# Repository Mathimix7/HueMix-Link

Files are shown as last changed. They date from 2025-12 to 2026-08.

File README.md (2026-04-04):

<h1 align="center">HueMix-Link</h1>
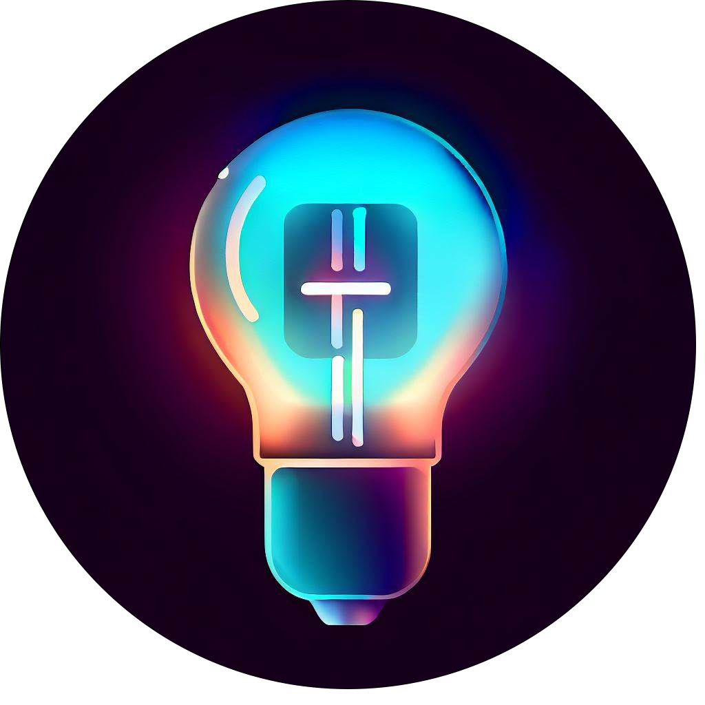
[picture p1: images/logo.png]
HueMix-Link's logo


## Table of Contents

- [Quick Start](#quick-start)
- [Project Overview](#project-overview)
- [Screenshots](#screenshots)
- [What Is In This Repository](#what-is-in-this-repository)
- [System Overview](#system-overview)
- [Prerequisites](#prerequisites)
- [Installation](#installation)
- [First-time Commissioning Workflow](#first-time-commissioning-workflow)
- [ESP Firmware: Build and Flash](#esp-firmware-build-and-flash)
- [Firmware Updates (OTA Page)](#firmware-updates-ota-page)
- [Configuration and Data Storage](#configuration-and-data-storage)
- [Networking and Ports](#networking-and-ports)
- [How Automation Works](#how-automation-works)
- [Devices](#devices)
- [License](#license)

## Quick Start

1. Install the backend on a Linux host:

 ```bash
  git clone https://github.com/Mathimix7/HueMix-Link.git
  cd HueMix-Link
  sudo bash install.sh
  ```

2. Open the web UI at `http://huemixlink.local` or your server IP.
2. Pair your Hue Bridge from the Bridge configuration page.
3. Put an ESP device into pairing mode and add it from the Pairing page.
4. Configure the device behavior, then verify it by triggering a button, motion sensor, or lightstrip sync.

## Project Overview

HueMix-Link is a local smart home bridge that connects custom ESP-based devices (gateways, buttons, remotes, motion sensors, door sensors, and lightstrips) to Philips Hue rooms and scenes.

It provides:

- A Flask web UI for setup and management
- A UDP server for low-latency gateway communication
- Automation logic for buttons, remotes, and motion sensors
- OTA firmware update workflows for all device types
- Backup and restore tools for configuration data

## Screenshots

<table width="85%" align="center">
  <tr>
    <td colspan="2" align="center">
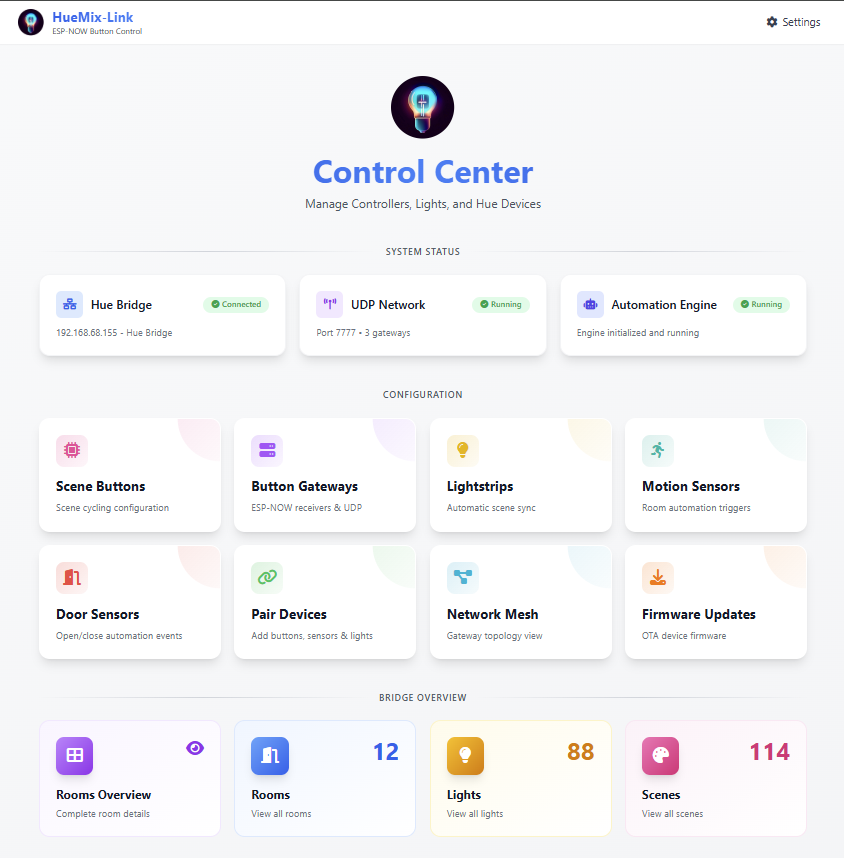
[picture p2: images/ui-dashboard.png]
Dashboard
      
    </td>
  </tr>
  <tr>
    <td width="50%" align="center">
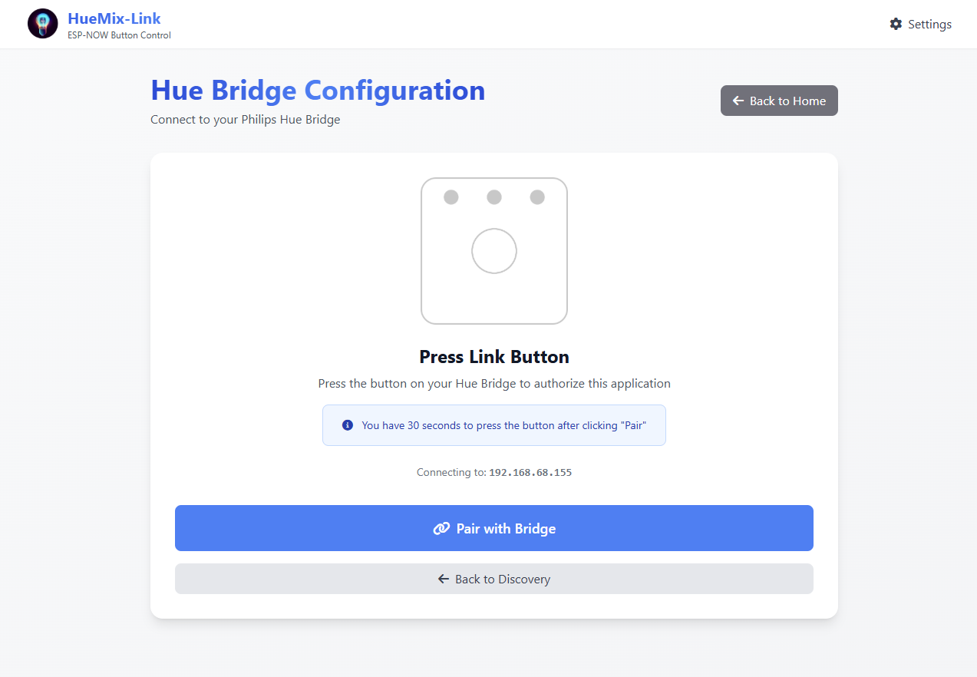
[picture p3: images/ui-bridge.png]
Bridge configuration
      
    </td>
    <td width="50%" align="center">
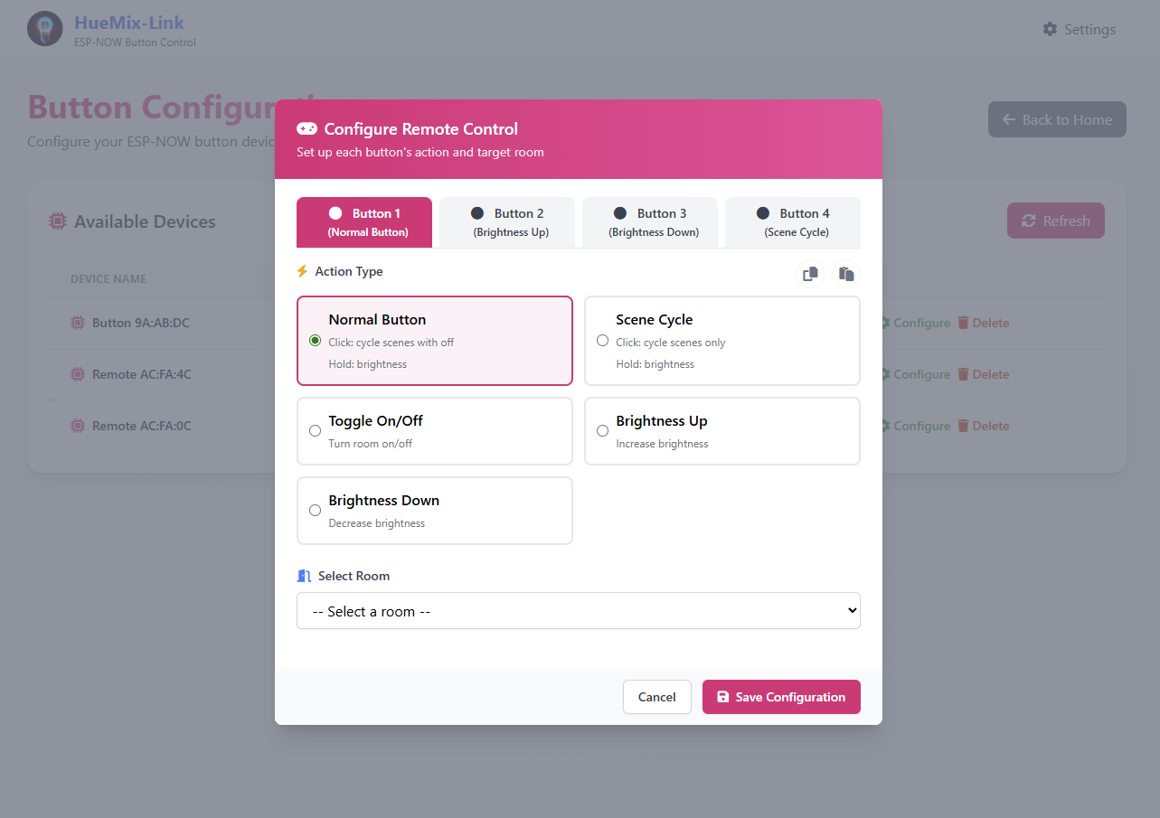
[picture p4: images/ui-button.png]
Button configuration
      
    </td>
  </tr>
  <tr>
    <td width="50%" align="center">
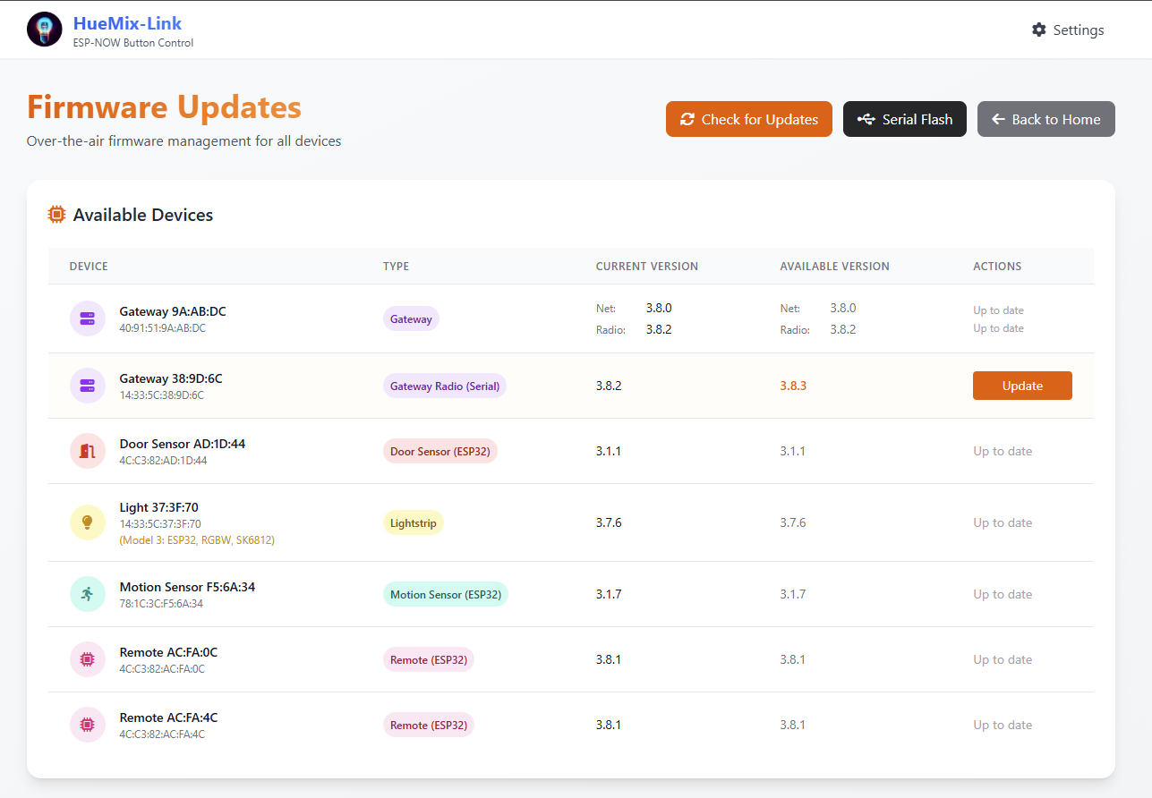
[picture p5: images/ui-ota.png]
OTA page
      
    </td>
    <td width="50%" align="center">
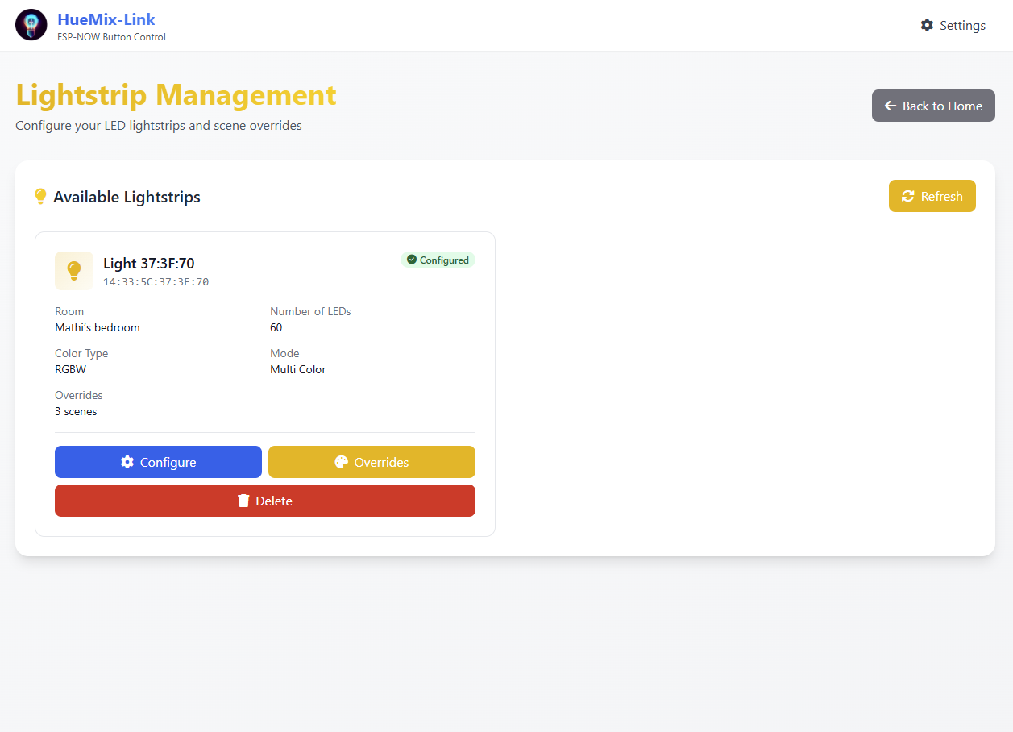
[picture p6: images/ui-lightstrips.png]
Lightstrip configuration
      
    </td>
  </tr>
</table>

## What Is In This Repository

- `python/`: Main backend service (Flask UI + UDP network + automations + OTA)
- `esp-firmware/`: PlatformIO firmware sources for all device types (gateway, buttons, remotes, motion sensors, door sensors, lightstrips)
- `Hardware-designs/`: KiCad design files for all device types (gateway, buttons, remotes, motion sensors, door sensors, lightstrips)
- `3D Files/`: 3D model files for all device types (STL format for 3D printing)
- `install.sh`: Linux installer/updater
- `VERSION`: Version file for installer/update workflows

## System Overview

### High-level architecture

1. **All ESP devices use ESP-NOW**: Low-power mesh protocol for device-to-device communication
2. **Gateways bridge ESP-NOW to UDP**: Gateways receive ESP-NOW messages and forward them to the backend via UDP
3. **Backend (UDP server) receives events**: Button presses, remote actions, motion detections, device hellos, delivery reports
4. **Automation engine maps events to Hue actions**: Scene activation, toggle on/off, brightness adjust, and lightstrip sync
5. **Hue state is cached and synchronized**: Automations and lightstrips stay aligned with current room/scene state
6. **Web UI for management**: Device pairing, automation configuration, OTA updates, monitoring, and backups

### Main runtime services

- **Flask + Waitress**: Web UI server `127.0.0.1:5001` (default)
- **UDP listener**: Receives gateway messages on `0.0.0.0:7777` (default, configurable)
- **Automation service**: Listens to device events and Hue state changes, applies configured logic
- **OTA manager**: Handles firmware distribution, chunking, and acknowledgment tracking

## Prerequisites

### Software

- Python 3.9+ (3.10+ recommended)
- `pip` and virtual environment support (`venv`)
- Network access to your Hue Bridge (same LAN)
- Linux OS with `systemd` (for production install)
- `sudo` access and `apt` package manager

### Hardware

- At least one Hue Bridge with configured rooms/scenes
- Supported HueMix-Link devices (gateways, buttons, remotes, motion sensors, door sensors, lightstrips)
- Firmware binaries matching your device type and model

## Installation

### Linux

From the repository root:

```bash
sudo bash install.sh
```

The installer will:

- Deploy the Python app to `/opt/huemix-link`
- Create a dedicated service user and Python virtual environment
- Set up a `systemd` service (`huemix-link`) to run on boot
- Configure HAProxy to expose the web app (HTTP port 80, HTTPS port 443 by default)
- Store all runtime data in `/opt/huemix-link/data`

Useful installer options:

```bash
sudo bash install.sh --help           # Show all options
sudo bash install.sh --yes            # Non-interactive install
sudo bash install.sh --dry-run        # Preview without making changes
sudo bash install.sh --force          # Force recreation of venv
sudo bash install.sh --show-version   # Show installed and source versions
sudo bash install.sh --port 8080      # Expose on custom HTTP port
sudo bash install.sh --no-https       # Disable HTTPS (HTTP only)
sudo bash install.sh --no-local       # Skip huemixlink.local hostname setup
```

After installation, the web UI is accessible at:

- `https://huemixlink.local` (or your server IP)
- `http://huemixlink.local` (or your server IP)

### Updating

To update the backend to a newer version, pull the latest code and re-run the installer:

```bash
git pull
sudo bash install.sh
```

The installer detects the existing installation, updates the files, and restarts the service automatically.

## First-time Commissioning Workflow

1. **Start the backend** (automatic on boot if installed via installer)
2. **Open the web UI** at `http://huemixlink.local` (or your server IP)
3. **Configure Hue Bridge**:
   - Go to the Bridge configuration page
   - Auto-discover or enter bridge IP manually
   - Press the Hue Bridge link button
   - Pair app with bridge (saves credentials)
4. **Pair ESP devices**:
   - Go to Pairing page
   - Start pairing window (choose device type if desired)
   - Power on or reset target devices
   - Devices announce themselves via ESP-NOW → gateway → backend
5. **Configure each device**:
    - **Buttons/Remotes**: Map to room + scenes + action behavior (normal, toggle, brightness, scene-cycle)
    - **Motion Sensors**: Set room, time slots, motion actions, after-actions, cooldown periods
    - **Door Sensors**: Set room, open/close actions, and any automation triggers tied to magnetic state changes
    - **Lightstrips**: Assign room, configure LED count/type, optional color scene overrides
    - **Gateways**: Verify online status, mesh routing, LED schedule (day/night auto-off)
6. **Validate behavior** by triggering physical events and checking Hue room/scene changes

## ESP Firmware: Build and Flash

### Flashing ESP devices

**Option 1: Serial flash via OTA page**

1. Go to the **OTA** page in the web UI
2. Select firmware type
3. Connect ESP device via serial in programming mode
4. Click **Flash** and select serial port
5. Monitor progress on the page

**Option 2: Serial port flash**

Use PlatformIO to flash directly via USB:

```bash
cd esp-firmware
pio run -e esp32_net_node --target upload
```

Or use `esptool.py` directly:

```bash
esptool.py --port /dev/ttyUSB0 write_flash 0x0 huemixlink-esp32-net-vX.Y.Z.bin
```

Pre-built firmware binaries are available in the project's GitHub releases. Download the `.bin` file(s) matching your device type and platform.

## Firmware Updates (OTA Page)

The **OTA** page in the web UI lets you:

- **Check available versions** from GitHub releases
- **Select device** type/model and target device
- **Battery-powered devices**: double-press the reset button before OTA update
- **Initiate flash** with progress monitoring
- **Monitor errors** and retry failed updates

## Configuration and Data Storage

All runtime configuration is stored in `python/data/` (or `/opt/huemix-link/data` in production) as JSON files:

- `bridge.json`: Hue bridge IP and app username
- `config.json`: Server settings (UDP port, dev mode)
- `gateways.json`: Known gateway devices
- `buttons.json`: Button and remote configurations
- `motion_sensors.json`: Motion sensor configurations and time slots
- `lightstrips.json`: Lightstrip configurations and color overrides
- `pairing_history.json`: Last 5 paired devices
- `home_id`: Unique identifier for this HueMix-Link instance. This value is embedded in every packet as a shared secret and used to verify that incoming messages belong to your installation. All devices must be paired while this ID is set — re-pairing is required if it changes.

Backups are created and restored through the settings page; they are stored in `data/backups/`.

## Networking and Ports

- **Web server (internal)**: `127.0.0.1:5001` (Flask)
- **UDP listener (internal)**: `0.0.0.0:7777` (default, receives gateway messages)
- **External HTTP/HTTPS (production)**: Exposed by HAProxy (default HTTP 80 + HTTPS 443)

UDP port can be changed in settings; the backend will restart UDP listening with the new port.

## How Automation Works

1. **Device sends event** via **ESP-NOW** (button press, remote action, motion detection)
2. **Gateway receives** via ESP-NOW and forwards message to backend via **UDP**
3. **UDP server** decodes and validates packet (signature check using HomeID)
4. **Device manager** resolves device identity; **pairing manager** verifies eligibility
5. **Automation engine** applies configured logic:
   - **Buttons/Remotes**: Scene cycle, toggle, brightness adjust, hold-to-adjust
   - **Motion Sensors**: Trigger scenes/lights on detection; post-motion fade/off actions; cooldown throttling
6. **Hue API** is called to apply scene/room/light changes
7. **Hue state manager** caches current room, light, and scene state
8. **Lightstrip sync**: Checks if any lightstrips should mirror current scene; sends raw LED commands via **ESP-NOW → gateway → UDP**

On startup, config sync reconciles saved room/scene references against live Hue topology to avoid stale mappings.

## Devices

### Gateway

<table><tr>
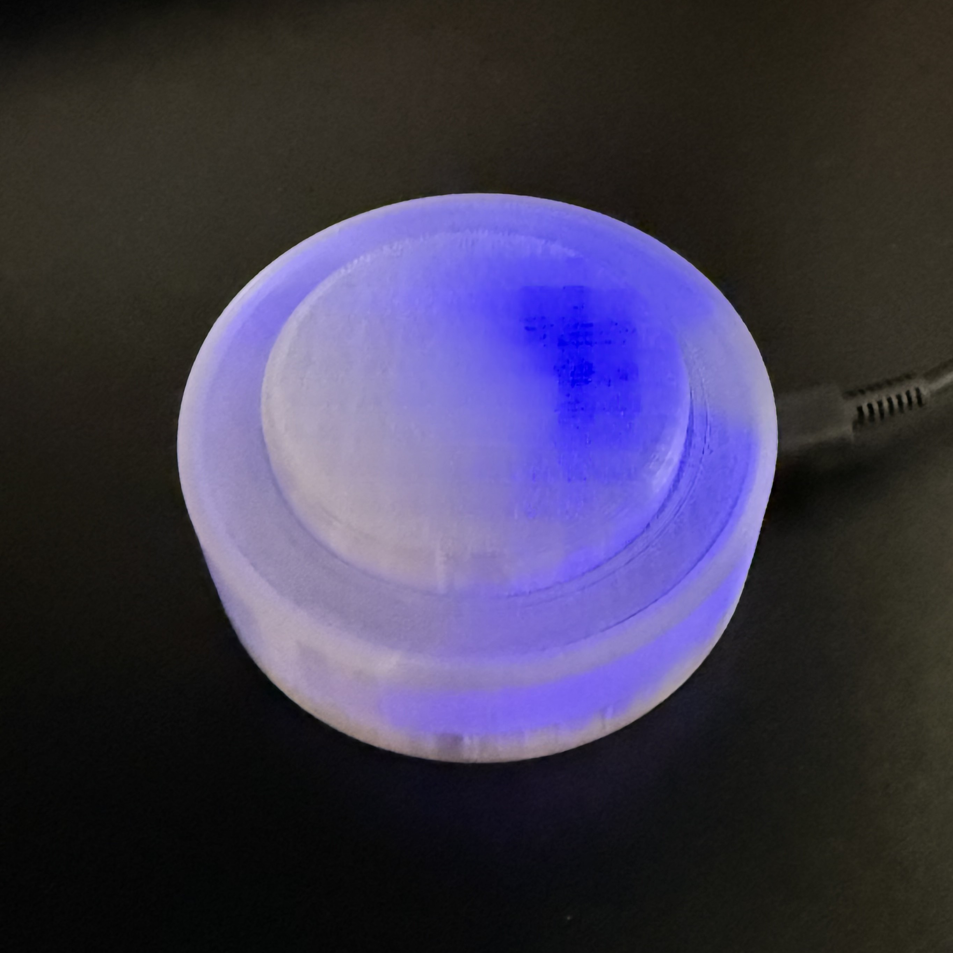
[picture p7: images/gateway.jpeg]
Gateway
  <td></td>
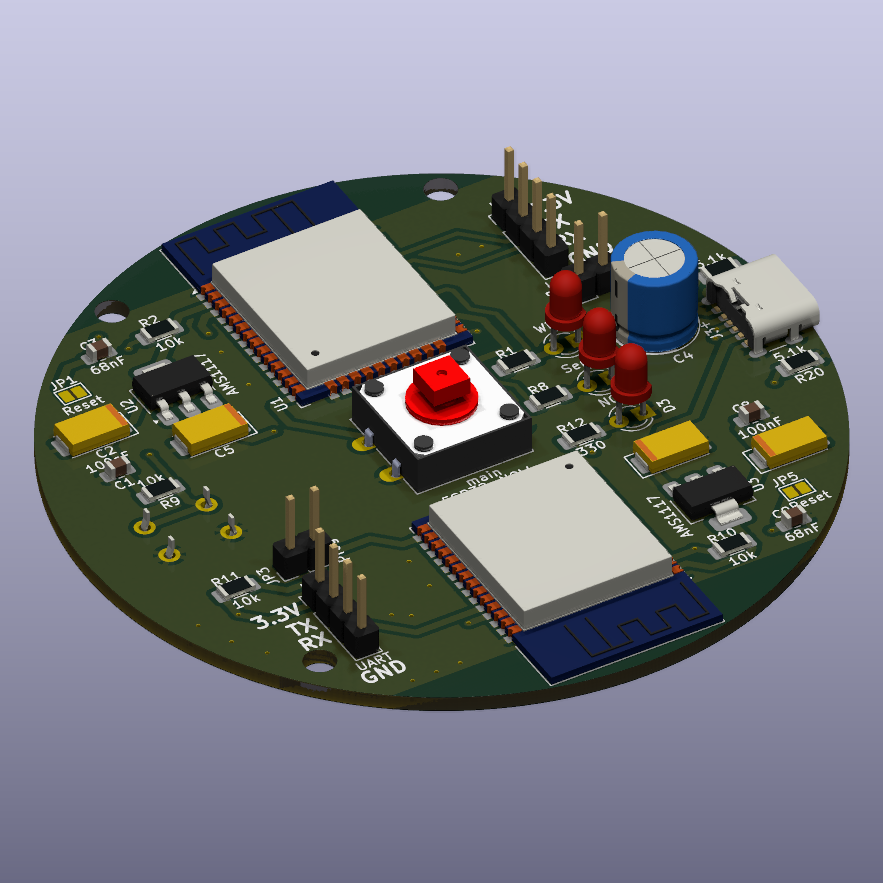
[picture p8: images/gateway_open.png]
Gateway
  <td></td>
</tr></table>

The Gateway is a single board that contains two ESP32 modules working together:

- **Net Node** — connects to your home WiFi and bridges between the backend (UDP) and the ESP-NOW mesh. Runs WiFiManager for wireless configuration and relays commands to the radio node over a high-speed UART link.
- **Radio Node** — handles all ESP-NOW communication with peripheral devices (buttons, remotes, sensors, lightstrips) and forwards packets to/from the net node over UART. Extends ESP-NOW coverage independently of WiFi.

**LED indicators**

| LED | State | Meaning |
|-----|---|---|
| WiFi | Off | No power / booting |
| WiFi | Fast blink (0.2s) | Not yet configured — WiFi config portal is open |
| WiFi | Slow blink (0.5s) | Connecting or retrying WiFi |
| WiFi | Solid on | Online and operational |
| Data | Brief flash | Packet received or forwarded |
| Data | Breathing (fade in/out) | Net node OTA firmware update in progress |
| Radio | Brief flash | ESP-NOW packet relayed |
| Radio | Breathing (fade in/out) | Radio node OTA firmware update in progress |

**Buttons**

- **Main button**: Acts as a single button that can be mapped to a Hue room in the web UI
- **Aux button**: Hold 5+ seconds to factory-reset and re-open the WiFi config portal

**Initial setup**

1. Power on the gateway — the WiFi LED fast-blinks and it broadcasts SSID `HueMix Link - XXXXXXXX`
2. Connect to that SSID (password: `HueMixLink`) with a phone or laptop
3. Enter your home WiFi credentials and the backend server IP + UDP port
4. The gateway connects, the WiFi LED goes solid, and it sends a HELLO to the backend

**Pairing**

Gateways pair automatically once configured.

**OTA**

Both nodes are updated from the OTA page. Gateways receive OTA directly (no double-press needed).

---

### Radio Gateway (Serial Python)

The Radio Gateway can also run as a serial-connected ESP32 node that pairs with the Python backend instead of WiFi.

- **Net/host side**: Python maintains the gateway state, serial transport, OTA scheduling, and dashboard telemetry
- **Radio side**: ESP32 radio node handles ESP-NOW traffic, OLED status display, and forwards packets over UART
- **LED indicators**: Follows the configured gateway LED schedule; the OLED display also respects the same on/off timing
- **OTA**: Updated from the OTA page using the `gateway_radio_python` firmware target

**Setup**

1. Flash the `esp32_radio_python` firmware
2. Connect the radio node to the backend host over USB serial
3. Configure the serial port in the web UI
4. The backend will sync HOME_ID, gateway state, and dashboard telemetry automatically

---

### Button

<table><tr>
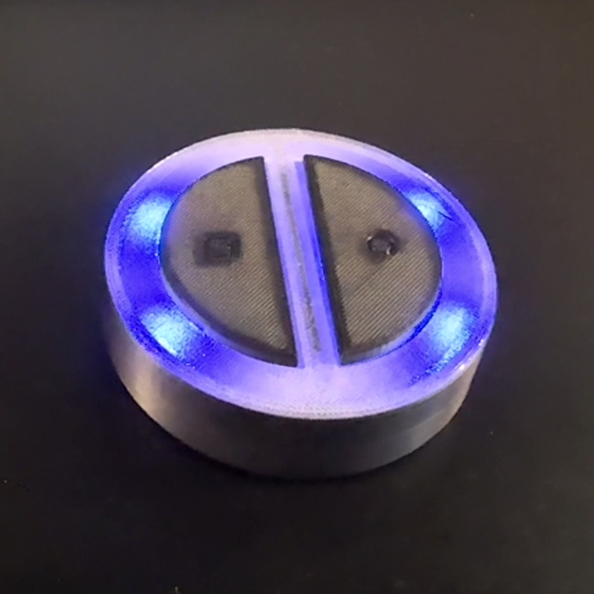
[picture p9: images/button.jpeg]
Button
  <td></td>
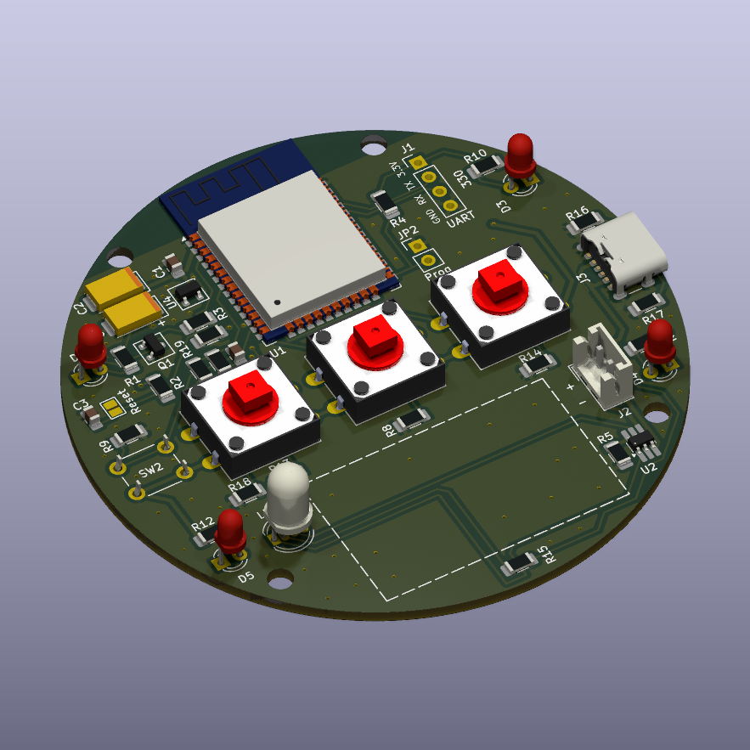
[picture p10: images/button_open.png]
Button
  <td></td>
</tr></table>

The Button is a single pushbutton device that sends click, hold, and release events via ESP-NOW. The ESP32 version is battery-powered and deep-sleeps between presses, while the ESP8266 version is always-on and runs continuously.

> [!WARNING]
> The `normal_button` firmware is deprecated. The ESP32 Normal Button board v3 and later should use the `remote_button` firmware configured as 1, 2, or 3 buttons.

**Events sent**

| Action | Trigger |
|---|---|
| Click | Short press and release |
| Holding | Held beyond 500 ms, repeated every 500 ms |
| Release | Released after a hold |

**Default automation** (configurable in web UI): Click cycles scenes in the assigned room. Hold adjusts brightness. Release stops brightness adjustment.

**LED indicators**

| State | Meaning |
|---|---|
| Brief flash | Action sent via ESP-NOW |
| 2 fast blinks | No acknowledgment — gateway may be out of range |
| 2 slow blinks | Failed to pair device |
| 3 blinks | OTA mode |
| 5 blinks | Device powered on |
| Breathing | OTA in progress |

**Setup and pairing**

1. Flash firmware via serial or the OTA page
2. Open the Pairing page, start a pairing window, then press the button to wake the device
3. After pairing, assign the button to a room in the device settings

**OTA**

**Double-press the reset button** to enter OTA mode — the LED will blink 3 times to confirm. Then initiate the flash from the OTA page.

---

### Remote

<table><tr>
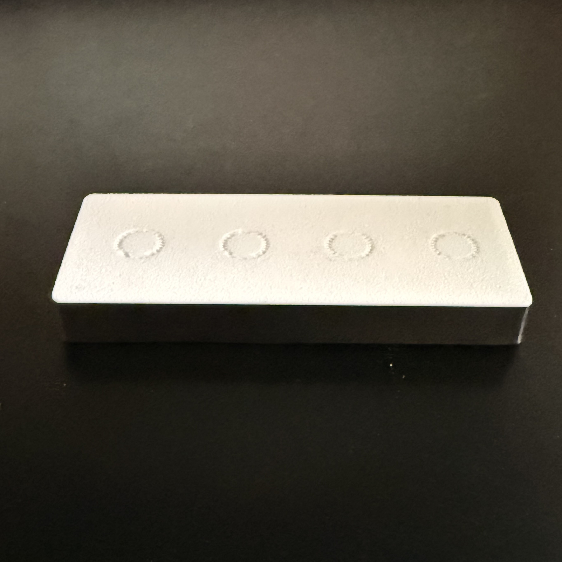
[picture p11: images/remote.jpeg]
Remote
  <td></td>
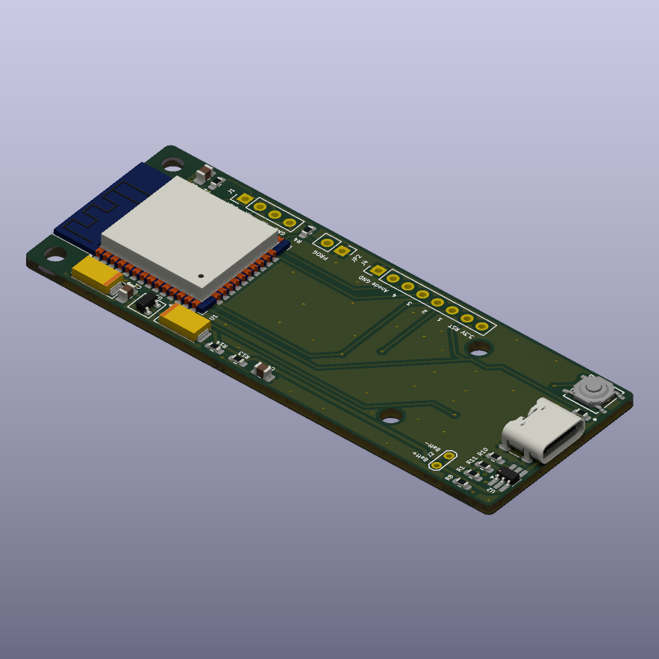
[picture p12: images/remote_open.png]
Remote
  <td></td>
</tr></table>

The Remote is a battery-powered ESP32 device with up to 4 independently configurable buttons. Each button can target a different room with its own action type. The number of active buttons (1–4) is configured via hardware at flash time.

**Action types per button** (configurable in web UI)

| Type | Click | Hold |
|---|---|---|
| Normal | Cycle scenes / turn room off | Adjust brightness |
| Toggle | Toggle room on/off | — |
| Brightness Up | Increase brightness | Increase continuously |
| Brightness Down | Decrease brightness | Decrease continuously |
| Scene Cycle | Cycle scenes (no off) | Adjust brightness |

**LED indicators**

| State | Meaning |
|---|---|
| Brief flash | Button action sent |
| 2 fast blinks | No acknowledgment — gateway may be out of range |
| 2 slow blinks | Failed to pair device |
| 3 blinks | OTA mode |
| 5 blinks | Device powered on |
| On 2 seconds | Button count configuration saved |
| Breathing | OTA in progress |

**Setting the button count**

Triple-press the reset button within 1 second to enter button-count config mode, while holding the target number of buttons simultaneously:

- 1 button: hold only button 4
- 2 buttons: hold buttons 1 + 2
- 3 buttons: hold buttons 1 + 2 + 4
- 4 buttons: hold all four buttons or None

**Setup and pairing**

1. Flash firmware via serial or the OTA page
2. Open the Pairing page, start a pairing window, then press any button to wake the device
3. After pairing, configure each button's room and action type in the device settings

**OTA**

Battery-powered. **Double-press the reset button** to enter OTA mode. The LED will blink 3 times to confirm. Then flash from the OTA page.

---

### Motion Sensor

<table><tr>
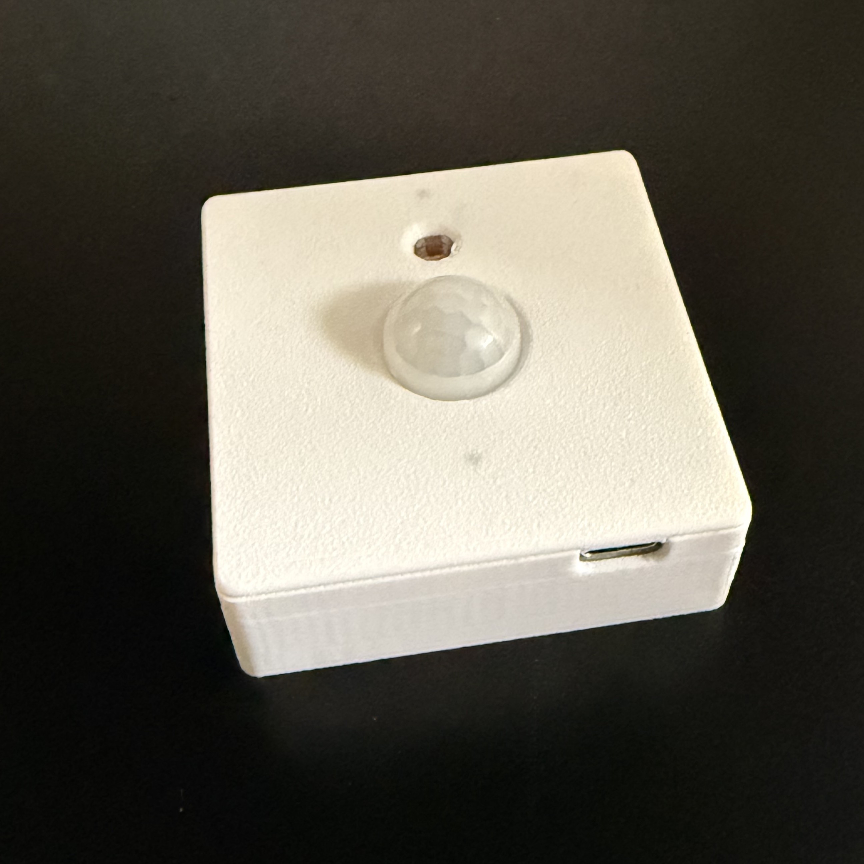
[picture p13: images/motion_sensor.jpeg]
Motion Sensor
  <td></td>
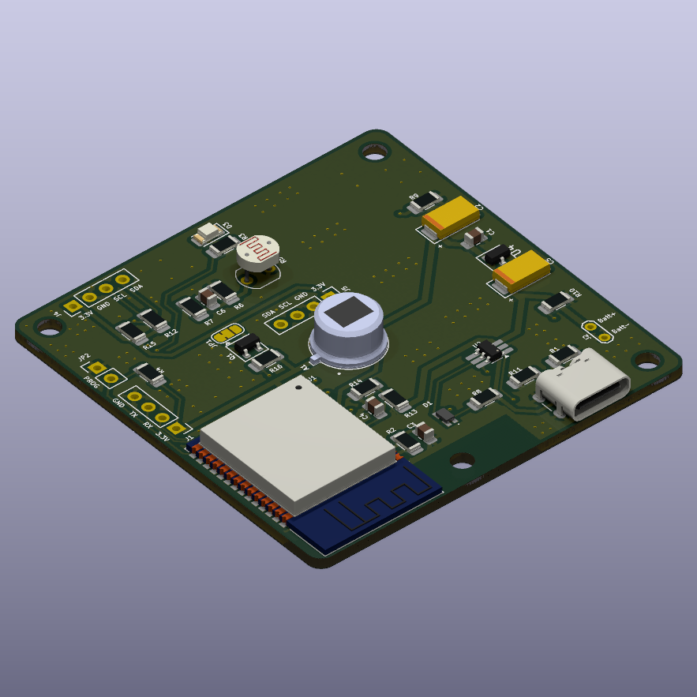
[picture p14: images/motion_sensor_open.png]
Motion Sensor
  <td></td>
</tr></table>

The Motion Sensor is a battery-powered ESP32 device with a PIR sensor and an ambient light level sensor (LDR). It sleeps in deep sleep and wakes when the PIR fires. After sending a motion event it enters a configurable cooldown period (default 60s) before re-arming.

**Data sent on motion detection**

- Motion detected flag
- Ambient light level (1-10)
- Battery voltage

**LED indicators**

| State | Meaning |
|---|---|
| Brief flash | Motion detected, event sent |
| 2 fast blinks | No acknowledgment — gateway may be out of range |
| 3 blinks | OTA mode |
| 5 blinks | Device powered on |
| Breathing | OTA in progress |

**Automation options** (configurable in web UI)

- Assign to a room and one or more scenes
- Set time slots (e.g., a different scene during the night)
- Configure an after-motion action (turn off, dim, change scene) and its delay
- Set the cooldown period (minimum seconds before re-triggering)

**Setup and pairing**

1. Flash firmware via serial or the OTA page
2. Open the Pairing page, start a pairing window, then single-press the reset button to wake the device
3. After pairing, configure the room, scenes, and time slots in the device settings

**OTA**

Battery-powered. **Double-press the reset button** to enter OTA mode. The LED will blink 3 times to confirm. Then flash from the OTA page.

---

### Door Sensor

<table><tr>
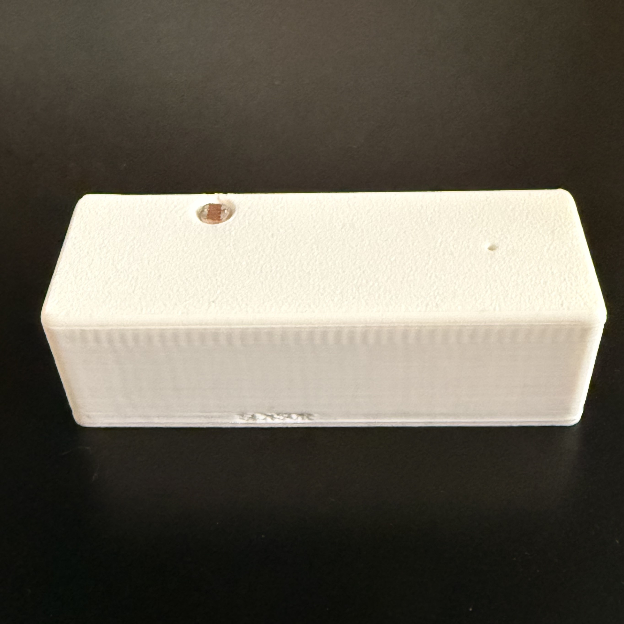
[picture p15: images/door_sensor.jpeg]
Door Sensor
  <td></td>
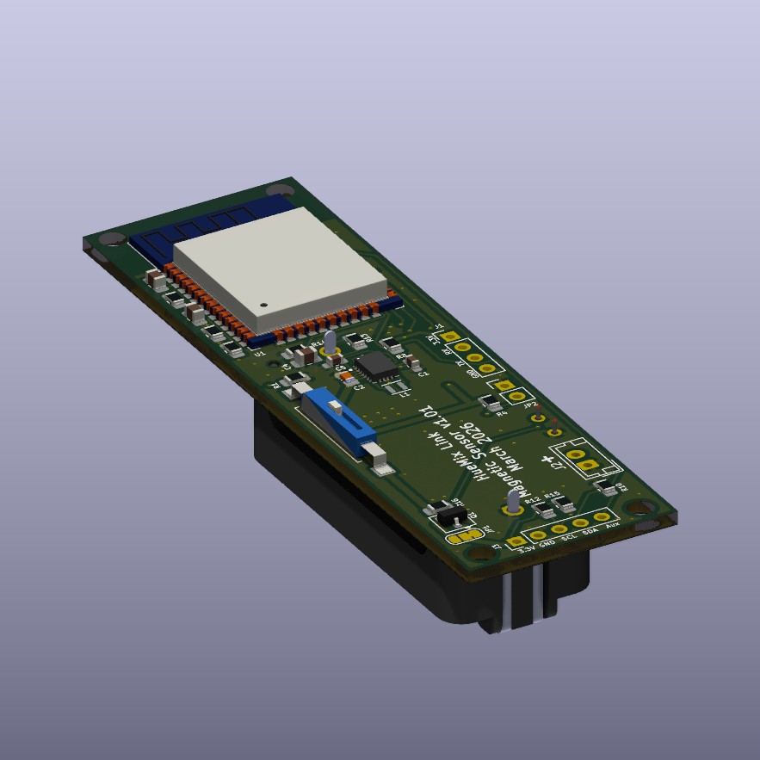
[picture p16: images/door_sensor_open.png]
Door Sensor
  <td></td>
</tr></table>

The Door Sensor is a battery-powered ESP32 device that reports magnetic open/close state changes and ambient light level over ESP-NOW.

**Events sent**

- Door opened
- Door closed
- Ambient light level (1-10)
- Battery voltage
- Firmware version / platform metadata

**LED indicators**

| State | Meaning |
|---|---|
| Brief flash | Door event sent |
| 2 fast blinks | No acknowledgment — gateway may be out of range |
| 3 blinks | OTA mode |
| 5 blinks | Device powered on |
| Breathing | OTA in progress |

**Setup and pairing**

1. Flash the door sensor firmware via serial or the OTA page
2. Open the Pairing page, start a pairing window, then single-press the reset button or activate the reed switch to wake the device
3. After pairing, assign the sensor to a room and add any open/close automations

**OTA**

Battery-powered. **Double-press the reset button** to enter OTA mode. Then flash from the OTA page.

---

### Lightstrip

<table><tr>
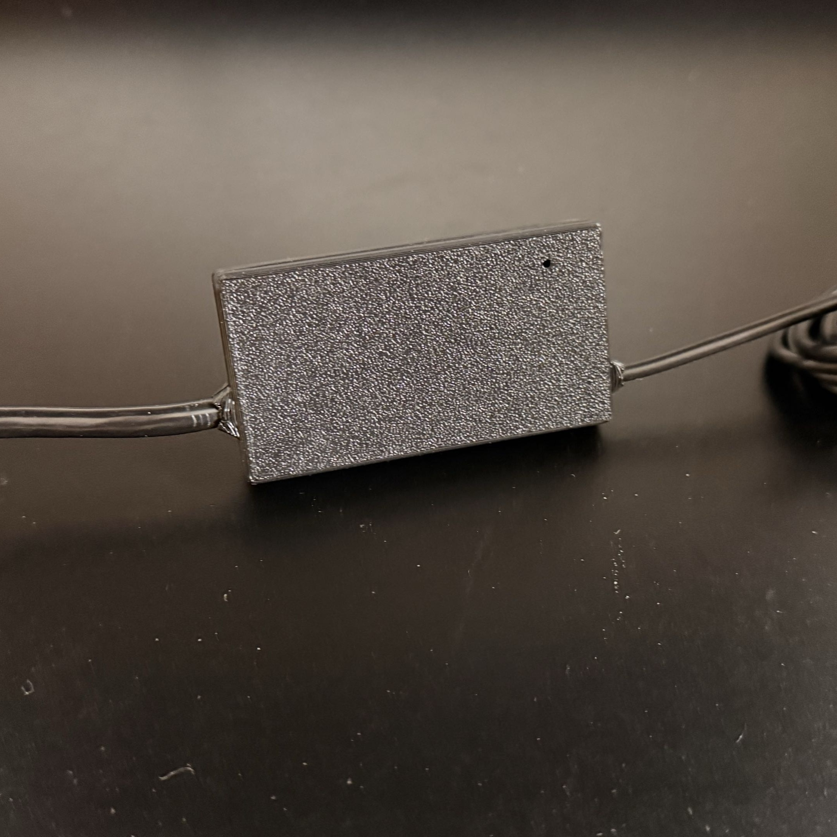
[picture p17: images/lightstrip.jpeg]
Lightstrip
  <td></td>
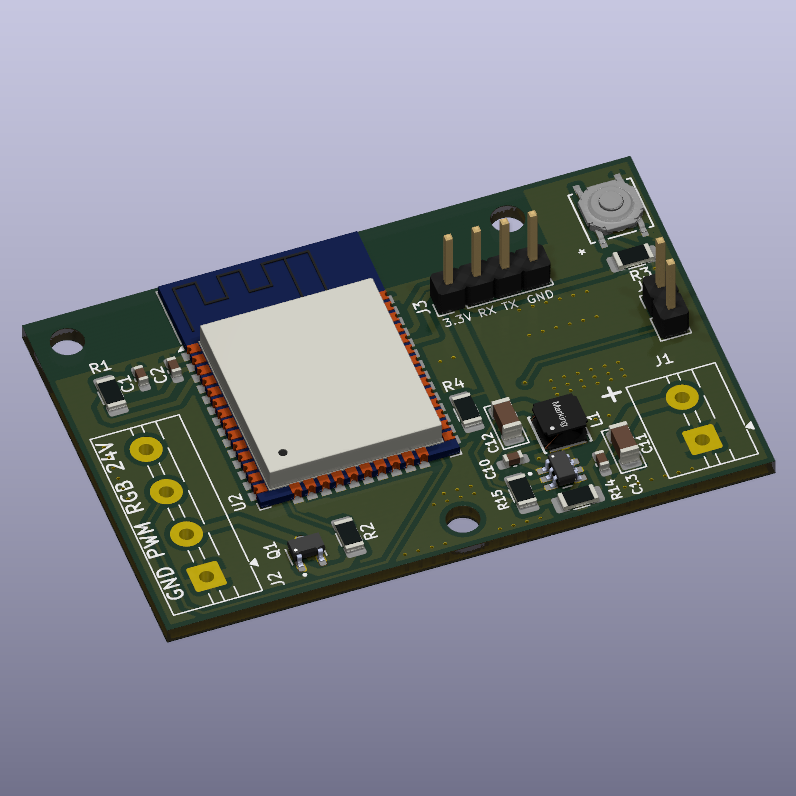
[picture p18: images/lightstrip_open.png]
Lightstrip
  <td></td>
</tr></table>

The Lightstrip is an ESP32 or ESP8266 device that drives WS2812B or SK6812 LED strips (up to 60 LEDs). It mirrors the scene colors of an assigned Hue room in real-time, syncing color, brightness, and saturation from the Hue state cache.

**Hardware models**

| Model | MCU | LED type | Notes |
|---|-----|---|---|
| 1 | ESP32 | WS2812B | Standard RGB |
| 2 | ESP8266 | WS2812B | Standard RGB |
| 3 | ESP32 | SK6812 | RGBW |
| 4 | ESP8266 | SK6812 | RGBW |
| 5 | ESP32 | WS2812B | RGB + warm white PWM channel |
| 6 | ESP8266 | WS2812B | RGB + warm white PWM channel |

**LED strip behavior**

- **On**: Displays current Hue scene colors
- **Off**: All LEDs off
- **Scene change**: Immediately transitions to new colors when the Hue room scene changes

**Setup and pairing**

1. Flash the correct model firmware to match your LED strip hardware
2. Open the Pairing page, start a pairing window, then power on or reset the device
3. After pairing, assign the lightstrip to a room and set the LED count in the device settings

**OTA**

Lightstrips receive OTA directly (no double-press needed).

---

## License

This project is licensed under the terms in `LICENSE`.

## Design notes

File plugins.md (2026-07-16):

# HueMix-Link Plugin System

HueMix-Link supports runtime-loaded plugins that extend the core platform with
custom device types, packet handlers, web UI pages, OTA firmware updates, and
more — all without modifying the core codebase.

---

## Table of Contents

- [Architecture Overview](#architecture-overview)
- [Plugin Lifecycle](#plugin-lifecycle)
- [Plugin Manifest (`plugin.json`)](#plugin-manifest-pluginjson)
- [Entry Points](#entry-points)
- [PluginHost API](#pluginhost-api)
- [Lifecycle Hooks](#lifecycle-hooks)
- [Event System](#event-system)
- [Device Registration & Packet Routing](#device-registration--packet-routing)
- [MAC Binding](#mac-binding)
- [Home Box Integration](#home-box-integration)
- [Flask Blueprint Registration](#flask-blueprint-registration)
- [OTA Firmware Support](#ota-firmware-support)
- [Complete Example: Temperature Tracking Plugin](#complete-example-temperature-tracking-plugin)
- [Installation](#installation)
- [Best Practices](#best-practices)
- [Troubleshooting](#troubleshooting)

---

## Architecture Overview

```
┌────────────────────────────────────────────────────────────┐
│                    HueMix-Link Core                        │
│  ┌─────────────┐  ┌──────────────┐  ┌───────────────────┐  │
│  │PluginManager│  │ NetworkServer│  │ PairingManager    │  │
│  │             │  │              │  │                   │  │
│  │ • load      │  │ • UDP packets│  │ • pair/unpair     │  │
│  │ • lifecycle │  │ • MAC routing│  │ • device rename   │  │
│  │ • events    │  │ • message IDs│  │ • pairing history │  │
│  └──────┬──────┘  └──────┬───────┘  └────────┬──────────┘  │
│         │                │                   │             │
│         └────────────────┼───────────────────┘             │
│                          │                                 │
│              PluginHost (injected services)                │
└──────────────────────────┼─────────────────────────────────┘
                           │
              ┌────────────┼────────────┐
              ▼            ▼            ▼
        ┌──────────┐ ┌──────────┐ ┌──────────┐
        │ Plugin A │ │ Plugin B │ │ Plugin C │
        │ (device) │ │ (service)│ │ (web UI) │
        └──────────┘ └──────────┘ └──────────┘
```

The **PluginManager** loads enabled plugins at startup from the registry
(`python/data/plugins.json`). Each plugin receives a **PluginHost** object that
provides access to core services (network server, pairing manager, config
manager, etc.) and an event bus for inter-plugin communication.

Plugins can:

- Register **custom device types** — when a device HELLO advertises a
  `plugin_id` matching the plugin, the network server routes its packets to the
  plugin.
- Handle **raw packet events** — subscribe to `packet_received` and inspect
  packet types, source MACs, and payloads.
- Expose **Flask blueprints** — add web UI endpoints under
  `/plugins/<your-plugin>/...`.
- Provide **OTA firmware metadata** — list devices eligible for over-the-air
  updates.
- Define a **home box card** — a tile rendered on the main dashboard for quick
  status at a glance.
- Subscribe to **core events** — react to pairing, device rename, and other
  system events.

---

## Plugin Lifecycle

Each plugin progresses through a well-defined lifecycle. All hooks are optional
— implement only what your plugin needs.

```
  ┌──────────────┐
  │  Registered  │  (entry exists in plugins.json)
  └──────┬───────┘
         │ [enabled = true]
         ▼
  ┌──────────────┐
  │    Import    │  module imported via importlib
  └──────┬───────┘
         ▼
  ┌──────────────┐
  │   Create     │  create_plugin() or Plugin() called
  └──────┬───────┘
         ▼
  ┌──────────────┐
  │ configure /  │  hook: prepare internal state
  │   setup      │
  └──────┬───────┘
         ▼
  ┌──────────────┐                                    ┌─────────────┐
  │   register   │  hook: register Flask blueprint    │  As many    │
  │              │  with the core app object          │  events as  │
  └──────┬───────┘                                    │  desired    │
         ▼                                            └──────▲──────┘
  ┌──────────────┐                                           │
  │ start / run  │  hook: subscribe to events, start         │
  │ / initialize │  background threads, open resources       │
  └──────┬───────┘                                           │
         │                                                   │
         ▼  (normal operation)                               │
  ┌──────────────┐  dispatch_event() ────────────────────────┘
  │   Running    │  on_packet_received()
  └──────┬───────┘  on_plugin_hello()
         │
         │ [shutdown]
         ▼
  ┌──────────────┐
  │  stop /      │  hook: flush state, close resources,
  │  shutdown /  │  stop background threads
  │  teardown    │
  └──────────────┘
```

The PluginManager calls hooks with flexible signatures. It tries multiple
argument combinations so your hook methods can accept only the parameters they
need:

```python
# All of these signatures work for register():
def register(self, app, context, host, manifest, options): ...
def register(self, app, context, host): ...
def register(self, context, host): ...
def register(self, app): ...
def register(self): ...
```

---

## Plugin Manifest (`plugin.json`)

Every plugin must provide a manifest as a standalone `plugin.json`
file at the root of the repository. The manifest is stored in the global registry at
`python/data/plugins.json` after installation.

### Required Fields

| Field | Type | Description |
|---|---|---|
| `id` | `string` | Human-readable identifier (e.g. `"temperature_tracking"`) |
| `plugin_id` | `string` | UUID v4 that uniquely identifies this plugin. Must match the UUID compiled into supporting device firmware. |
| `module` | `string` | Python import path: `"plugins.<package_name>.plugin"` |
| `version` | `string` | Semantic version of the plugin code (e.g. `"1.2.0"`). Used for update checking. |

### Optional Fields

| Field | Type | Default | Description |
|---|---|---|---|
| `enabled` | `boolean` | `true` | Whether the plugin loads at startup |
| `plugin_api_version` | `integer` | `1` | Plugin API version this plugin targets. The core rejects plugins with mismatched API versions. |
| `kind` | `string` | `"generic"` | Plugin category |
| `capabilities` | `string[]` | `[]` | Feature flags like `"devices"`, `"web_ui"`, `"ota"` |
| `options` | `object` | `{}` | Free-form configuration passed to `create_plugin()` |
| `devices` | `array` | `[]` | Device type declarations for routing (see below) |
| `ota` | `array` | `[]` | OTA firmware target declarations |
| `home_box` | `object` | `null` | Dashboard card definition |
| `metadata` | `object` | `{}` | Install-time metadata (source_repo, installed_at, etc.) |

### Device Declaration

Each entry in the `devices` array tells the core:

- What `device_type` integer this plugin claims.
- Which `packet_types` it handles.
- How the device is displayed in the pairing UI.

```json
{
  "id": "temperature_tracking",
  "plugin_id": "550e8400-e29b-41d4-a716-446655440000",
  "module": "plugins.temperature_tracking.plugin",
  "enabled": true,
  "devices": [
    {
      "device_type": 0,
      "name": "Temperature Sensor",
      "type": "Sensor",
      "icon": "🌡️"
    },
    {
      "device_type": 1,
      "name": "Battery Temp Sensor",
      "type": "Sensor",
      "icon": "🌡️"
    }
  ]
}
```

When the network server receives a HELLO packet advertising a `plugin_id` that
matches this plugin's UUID, it routes the device to this plugin. The
`device_type` value is used for pairing rules and display.

### Home Box Card

The `home_box` field defines a tile card rendered on the main dashboard:

```json
{
  "home_box": {
    "name": "Temperature Tracking",
    "description": "View sensor temperatures and configure devices",
    "icon": "thermometer-half",
    "color": "emerald",
    "link": "/plugins/temperature"
  }
}
```

If `home_box` is absent, no dashboard card is shown.

---

## Entry Points

Your plugin module must expose one of these factory callables:

### `create_plugin(options=None, context=None, host=None, manifest=None)`

A factory function that returns your plugin instance:

```python
def create_plugin(options=None, context=None, host=None, manifest=None, **_kwargs):
    return MyPlugin(options=options or {}, context=context or host, manifest=manifest)
```

### `Plugin` class

A class that the PluginManager instantiates directly:

```python
class Plugin:
    def __init__(self, options=None, context=None, host=None, manifest=None):
        self.options = options or {}
        self.context = context or host
        self.manifest = manifest
```

The PluginManager tries multiple argument combinations so your factory can
accept only the parameters it needs:

```python
# All supported signatures:
create_plugin(options, context, host, manifest)
create_plugin(options, context, host)
create_plugin(options, context)
create_plugin(context)
create_plugin()
```

---

## PluginHost API

The `PluginHost` object is the bridge between your plugin and the core system.
It is passed to your plugin as `context` or `host` in lifecycle hooks and
events.

### Service Access

```python
# Get a service, returning None if unavailable
network_server = host.service('network_server')

# Get a service, raising KeyError if unavailable
network_server = host.require('network_server')

# Check if a service exists
if host.has('pairing_manager'):
    ...
```

### Available Services

| Service Name | Object | Description |
|---|---|---|
| `app` | Flask application | Register blueprints, access config |
| `config_manager` | ConfigManager | Read/write app configuration |
| `data_manager` | DataManager | Read/write JSON data files |
| `network_server` | NetworkServer | Send/recv UDP packets to devices |
| `pairing_manager` | PairingManager | Pair/unpair devices, manage history |
| `automation_service` | AutomationService | Trigger automations |
| `home_id_manager` | HomeIDManager | Read/write HOME_ID |
| `plugin_manager` | PluginManager | Query other plugins, MAC bindings |
| `logger` | Logger | Standard Python logger |

### Event Bus

```python
# Publish an event that other plugins or the core can react to
host.publish('temperature_reading', {'sensor_mac': ..., 'temperature_c': ...})

# Subscribe to events from other plugins
host.subscribe('device_renamed', self.on_device_renamed)
```

---

## Lifecycle Hooks

All hooks are optional. Implement only what you need.

### `configure(options, context, host, manifest)` / `setup(...)`

Called first, before anything else. Use this to initialize internal state from
`options` and `manifest`.

```python
def setup(self, options=None, context=None, host=None, manifest=None):
    self.plugin_uuid = manifest.get('plugin_id') if manifest else None
    self.history_limit = options.get('history_limit', 100) if options else 100
```

### `register(app, context, host, manifest, options)`

Called after `configure/setup`. Use this to register Flask blueprints with the
core application.

```python
def register(self, app, context=None):
    self.context = context or self.context
    app.register_blueprint(self.blueprint)
```

### `start(context, host, manifest, app)` / `run(...)` / `initialize(...)`

Called last, after `register`. Use this to subscribe to events, start
background threads, open file handles, or begin network operations.

```python
def start(self, context=None):
    self.context = context or self.context
    self._subscribe_to_events()
    self._start_background_worker()
```

### `stop(context, host)` / `shutdown(...)` / `teardown(...)`

Called during graceful shutdown (reverse order of loading). Use this to flush
state, close resources, and stop threads.

```python
def stop(self, context=None):
    self._stop_background_worker()
    self._flush_readings_to_disk()
```

---

## Event System

Plugins receive events through several mechanisms:

### `on_event(event_name, payload, host)`

Generic event handler — receives all events the core dispatches:

```python
def on_event(self, event_name, payload, host=None):
    if event_name == 'packet_received':
        self._handle_packet(payload)
```

### `handle_event(event_name, payload, host)`

Alias for `on_event` with the same semantics.

### `on_{event_name}(payload, host)`

Specific event handler — only called for the named event. Takes priority over
`on_event`/`handle_event`:

```python
def on_packet_received(self, payload, host=None):
    # Only receives 'packet_received' events
    packet_type = payload.get('type')
    source_mac = payload.get('source_mac')
    ...
```

### Events Dispatched by the Core

| Event | Payload | When |
|---|---|---|
| `packet_received` | `{type, payload, source_mac, sender_ip, gateway_radio_mac}` | Any UDP packet arrives |
| `plugin_hello` | `{device_mac, plugin_uuid, plugin_device_type, rssi, version, platform, sender_ip, gateway_radio_mac, is_paired}` | A plugin device sends a HELLO |
| `device_renamed` | `{device_id, plugin_id, old_name, new_name, device_type}` | A paired device is renamed |

### Publishing Custom Events

Plugins can publish their own events for other plugins to consume:

```python
# In plugin A:
host.publish('temperature_reading', {
    'sensor_mac': 'AA:BB:CC:DD:EE:FF',
    'temperature_c': 23.5,
})

# In plugin B:
def start(self, context=None):
    context.subscribe('temperature_reading', self.on_temp_reading)

def on_temp_reading(self, event_name, payload, host=None):
    print(f"Got reading: {payload['temperature_c']}°C")
```

---

## Device Registration & Packet Routing

This is the most powerful feature of the plugin system — plugins can define
their own device types and handle raw packets.

### How Routing Works

```
Device HELLO ──► NetworkServer
                    │
                    ▼
              Has plugin_id in HELLO?
              ┌─────┴─────┐
             Yes           No
              │             │
              ▼             ▼
        PluginManager   Standard
        .get_plugin_    pairing
        for_mac()       flow
              │
              ▼
        Route all packets
        from that MAC to
        the owning plugin
```

### Declaring Device Types

In your manifest's `devices` array, list each device type your plugin owns:

```json
{
  "devices": [
    {"device_type": 42, "name": "My Custom Sensor", "type": "Sensor", "icon": "🔵"}
  ]
}
```

### Handling Packets

Implement `on_packet_received` in your plugin:

```python
MY_PACKET_TYPE = 0x55

def on_packet_received(self, event_name, payload, host=None):
    packet_type = payload.get('type')
    packet_payload = payload.get('payload') or b''
    source_mac = payload.get('source_mac')

    if packet_type != MY_PACKET_TYPE:
        return

    # Parse your custom protocol
    temp, humidity = struct.unpack('<hH', packet_payload[:4])
    self._store_reading(source_mac, temp / 10.0, humidity / 10.0)
```

### Sending Packets

Use `network_server.send_raw_packet_to_device()` to send data:

```python
def _send_config(self, mac):
    network_server = self.context.require('network_server')
    packet = self._build_packet(mac)
    network_server.send_raw_packet_to_device(
        mac,
        packet,
        wait_for_delivery=True,
        msg_id=network_server.get_message_id(),
        gateway_preference=gateway_mac,
    )
```

Because routing is MAC-based, multiple plugins can safely declare the same
`device_type` without conflicts.

---

## MAC Binding

When a plugin device is paired, the core creates a persistent `MAC → plugin_id`
binding stored in `python/data/plugin_device_bindings.json`. This binding
ensures that all future packets from that MAC are routed to the correct plugin.

```python
# Core side (called during pairing):
plugin_manager.bind_mac_to_plugin("AA:BB:CC:DD:EE:FF", "550e8400-...")

# Plugin side (check if a MAC belongs to you):
plugin_manager = host.require('plugin_manager')
plugin_for_mac = plugin_manager.get_plugin_for_mac(source_mac)
if plugin_for_mac != self.plugin_uuid:
    return  # Not my device
```

Your plugin should always verify that incoming packets are from a device bound
to it:

```python
def on_packet_received(self, event_name, payload, host=None):
    source_mac = payload.get('source_mac')
    plugin_manager = self._get_plugin_manager(host)
    if not plugin_manager:
        return

    plugin_for_mac = plugin_manager.get_plugin_for_mac(source_mac)
    if not plugin_for_mac or plugin_for_mac != self.plugin_uuid:
        return  # Not our device, skip

    # Safe to process
    ...
```

---

## Home Box Integration

A "home box" is a card rendered on the main dashboard (`/`). Define it in your
manifest:

```json
{
  "home_box": {
    "name": "Temperature Tracking",
    "description": "View sensor temperatures and configure devices",
    "icon": "thermometer-half",
    "color": "emerald",
    "link": "/plugins/temperature"
  }
}
```

- `icon`: Font Awesome icon name (e.g., `"thermometer-half"`, `"microchip"`)
- `color`: Tailwind color name (e.g., `"emerald"`, `"sky"`, `"violet"`)
- `link`: URL path to your plugin's main page

---

## Flask Blueprint Registration

Plugins can serve their own web pages by registering a Flask blueprint during
the `register` hook:

```python
class MyPlugin:
    def __init__(self, **kwargs):
        self.blueprint = Blueprint(
            'my_plugin',
            __name__,
            url_prefix='/plugins/my-plugin',
            template_folder='templates',
            static_folder='static',
        )
        self.blueprint.add_url_rule('/', 'index', self.index)
        self.blueprint.add_url_rule('/status', 'status', self.status)
        self.blueprint.add_url_rule('/api/data', 'api_data', self.api_data)

    def register(self, app, context=None):
        app.register_blueprint(self.blueprint)

    def index(self):
        return render_template('my_plugin_home.html')

    def status(self):
        return jsonify({'enabled': True, 'status': 'running'})
```

Directory structure for a plugin with web UI:

```
my_plugin/
├── __init__.py
├── plugin.py
├── templates/
│   └── my_plugin_home.html
└── static/
    ├── style.css
    └── script.js
```

---

## OTA Firmware Support

Plugins that manage devices can expose OTA metadata by implementing
`get_ota_devices()`:

```python
def get_ota_devices(self):
    return [
        {
            'mac_address': 'AA:BB:CC:DD:EE:FF',
            'version': '1.2.3',
            'platform': 'esp32',
            'last_gateway_mac': '11:22:33:44:55:66',
            'name': 'Temperature Sensor',
            'device_type': 0,
        }
    ]
```

The core collects these across all plugins and presents them in the OTA
management interface. The `plugin_id` is injected automatically by the core.

---

## Complete Example: Temperature Tracking Plugin

A full working example is included at `python/plugins/temperature_tracking/`.
It demonstrates:

- **Plugin manifest** — declares two device types (standard and battery
  temperature sensors), UUID matching firmware.
- **`create_plugin()` factory** — accepts `options`, `context`, `manifest`,
  and `host`.
- **Flask blueprint** — serves a dashboard (`/plugins/temperature/`), REST API
  endpoints (`/plugins/temperature/api/devices/...`), and a graphs page.
- **`on_packet_received`** — handles `0x55` temperature readings, parses a
  binary protocol with struct, stores readings with timestamps.
- **`on_plugin_hello`** — registers sensors when they come online, sends
  pending configuration.
- **`on_device_renamed`** — keeps internal sensor names in sync with the core
  pairing manager.
- **`get_ota_devices()`** — exposes all known sensors for OTA updates.
- **Host service usage** — uses `network_server`, `plugin_manager`, and
  `pairing_manager` from the host context.
- **Config push** — sends device configuration packets over UDP with delivery
  confirmation.

### Key Files

| File | Purpose |
|---|---|
| `plugins/temperature_tracking/plugin.py` | Main plugin class, packet handling, web UI |
| `plugins/temperature_tracking/storage.py` | In-memory + file-backed data storage (JSON) |
| `plugins/temperature_tracking/templates/` | Jinja2 templates for web UI |
| `plugins/temperature_tracking/static/` | Static assets (CSS, JS) |

---

## Installation

### Via the Admin UI

1. Navigate to **Admin → Plugin Manager**.
2. Paste the Git repository URL (GitHub only) and optionally a branch.
3. Click **Install Plugin** — the system clones the repo, validates the
   manifest, installs Python dependencies, copies the package folder, and
   registers the plugin.
4. **Restart the service** (or restart from the admin UI) for the plugin to
   load.

### Manual Installation

1. Add your plugin package to `python/plugins/<package_name>/`.
2. Add an entry to `python/data/plugins.json`:

   ```json
   {
     "plugins": [
       {
         "id": "my_plugin",
         "plugin_id": "your-uuid-here",
         "module": "plugins.my_plugin.plugin",
         "enabled": true
       }
     ]
   }
   ```

3. Restart the HueMix-Link service.

---

## Plugin Versioning & Updates

### Version Field

Every plugin should declare a `version` field in its `plugin.json` manifest using
[semantic versioning](https://semver.org/) (`MAJOR.MINOR.PATCH`, e.g., `"1.2.0"`).

- **MAJOR**: Breaking changes to the plugin's device protocol, API, or data storage.
- **MINOR**: New features that are backward-compatible.
- **PATCH**: Bug fixes and minor improvements.

The version is stored in the registry at `python/data/plugins.json` and displayed
in the admin plugin manager UI.

### Plugin API Version

The `plugin_api_version` field declares which version of the PluginHost API the
plugin was built against. The current core API version is **1**.

If the core's `PLUGIN_API_VERSION` does not match the plugin's declared
`plugin_api_version`, the plugin is **skipped at load time** with a warning in
the logs. This prevents plugins written for a different API from crashing at
runtime.

```json
{
  "id": "my_plugin",
  "plugin_id": "550e8400-...",
  "module": "plugins.my_plugin.plugin",
  "version": "1.2.0",
  "plugin_api_version": 1
}
```

### How Updates Work

The update mechanism uses **GitHub Releases**. When you check for updates:

1. The system fetches the latest release from the plugin's `source_repo` via the
   [GitHub Releases API](https://docs.github.com/en/rest/releases/releases).
2. It compares the release tag (parsed as semver) against the installed version.
3. If a newer version is found, an **Update** button appears in the admin UI.

### Applying an Update

When you click **Update**:

1. The system clones the repository at the latest release tag.
2. Validates the new manifest (`plugin.json`).
3. Removes the old plugin package directory.
4. Copies the new package files.
5. Re-installs Python dependencies from `requirements.txt` (if present).
6. Updates the registry entry with the new version and metadata — preserving
   `enabled` state, device bindings, and plugin options.
7. A **server restart** is required for the updated plugin code to load.

### Release Workflow for Plugin Developers

To make your plugin updatable via the admin UI:

1. Tag each release with a semver tag: `v1.0.0`, `v1.1.0`, `v2.0.0`, etc.
2. Create a **GitHub Release** from the tag. The release body is shown as
   release notes in the admin UI.
3. Update the `version` field in your `plugin.json` to match the release tag.

The system automatically picks up the latest release. If no formal releases
exist, it falls back to checking Git tags for the highest semver tag.

### What Gets Preserved During an Update

| Field | Preserved? |
|---|---|
| `enabled` state | Yes |
| Plugin `options` | Yes |
| MAC → plugin device bindings | Yes |
| Pairing history entries | Yes |
| Device names and metadata | Yes |
| `version` | Updated from new manifest |
| `metadata.source_repo` | Yes |
| `metadata.updated_at` | Set to current time |

---

## Best Practices

### Plugin UUID

Use a proper UUID v4 for `plugin_id` (generated via `uuid.uuid4()`). This UUID
must be compiled into any device firmware that should be routed to your plugin.

### Packet Protocol Design

- Use a dedicated `packet_type` byte (0x50–0x7F range for plugins).
- Include a signature/hash for integrity if the packet is mutated in transit.
- Pad payloads to a consistent size (185 bytes is standard in this system).

### Error Handling

- Wrap all event handlers in try/except — an unhandled exception in one plugin
  does not crash other plugins.
- Log failures with `context.logger` or a dedicated logger.
- Validate all incoming data from the network.

### State Management

- Use `data_manager.read_json()` / `write_json()` for persistent state.
- Keep internal state thread-safe (use locks if accessing from background
  threads).
- Flush state in `stop()` / `shutdown()`.

### Background Threads

- Use `threading.Thread(daemon=True)` for background workers so they don't
  block shutdown.
- Name your threads for easier debugging.

### Flask Blueprints

- Prefix all routes with `/plugins/<your-plugin-name>/`.
- Use `template_folder` and `static_folder` relative to your plugin package.
- Register the blueprint in `register()`, not `__init__()`.

---

## Troubleshooting

### Plugin not loading

- Check `python/data/plugins.json` for correct `id`, `plugin_id`, and `module`.
- Verify the module path exists: `python/plugins/<package>/plugin.py`.
- Check the server logs for import errors or exception tracebacks.

### Packets not reaching my plugin

- Verify the device firmware sends the correct `plugin_id` UUID in HELLO
  packets.
- Verify the device MAC is bound to your plugin (check
  `plugin_device_bindings.json`).
- Check `on_packet_received` signature — it must accept the event parameters.

### Blueprint 404 errors

- Ensure the blueprint is registered in `register()`, not `__init__()`.
- The core must call `register()` before the Flask server starts serving
  requests.
- Verify the `url_prefix` and route paths.

### Changes not taking effect

- Plugin changes (install, uninstall, enable, disable) require a full service
  restart — there is no hot-reload mechanism. Use the admin panel's restart
  button or run `sudo systemctl restart huemix-link`.

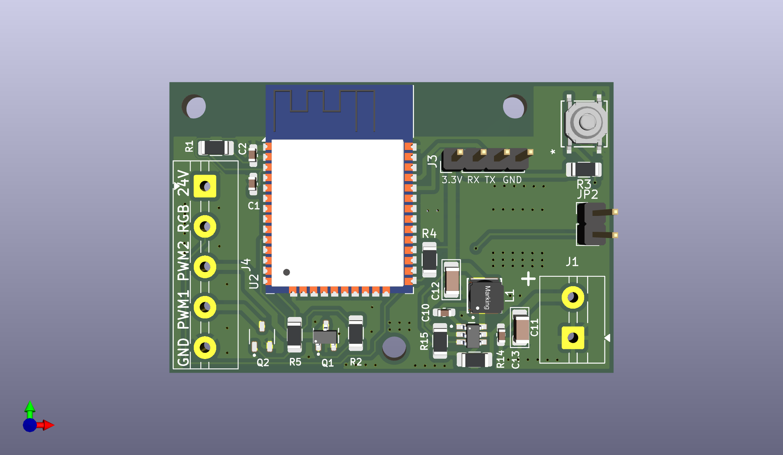
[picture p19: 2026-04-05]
Hardware-designs/Lightstrip/Lightstrip_front.png

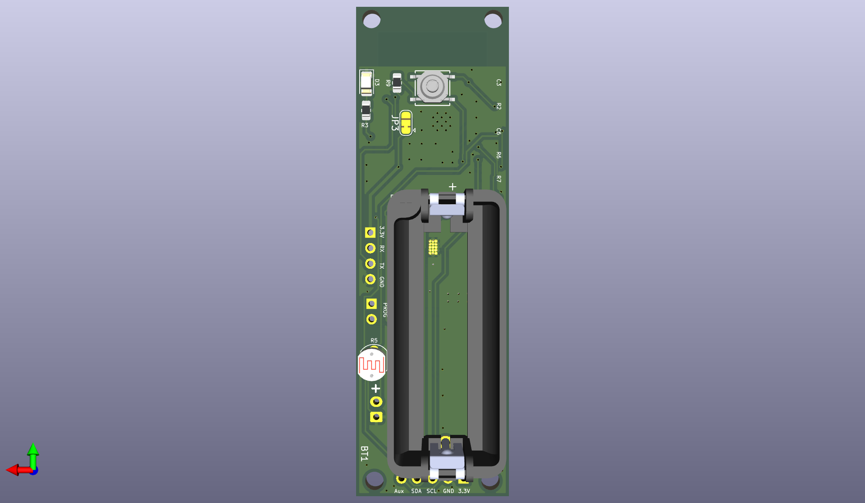
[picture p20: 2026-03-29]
Hardware-designs/Magnetic Sensor/Magnetic Sensor-back.png

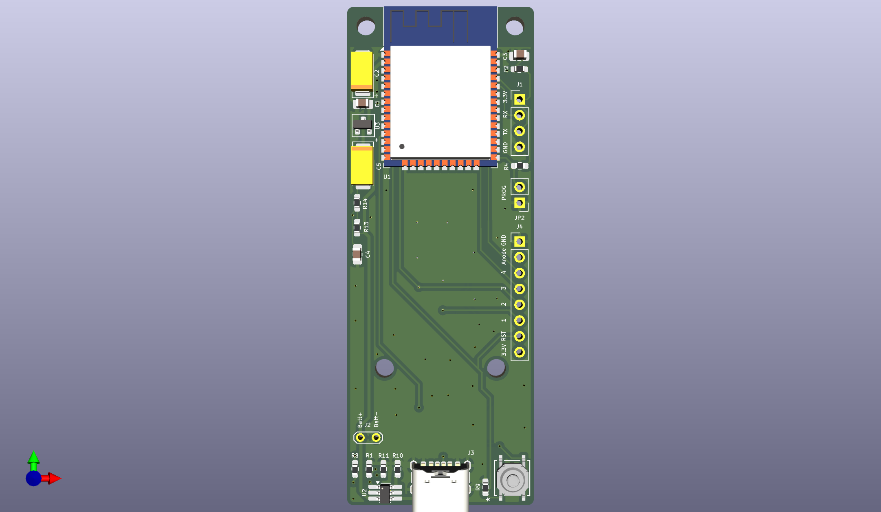
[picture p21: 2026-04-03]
Hardware-designs/Remote_4button_v1/Remote_4button_v1_front.png

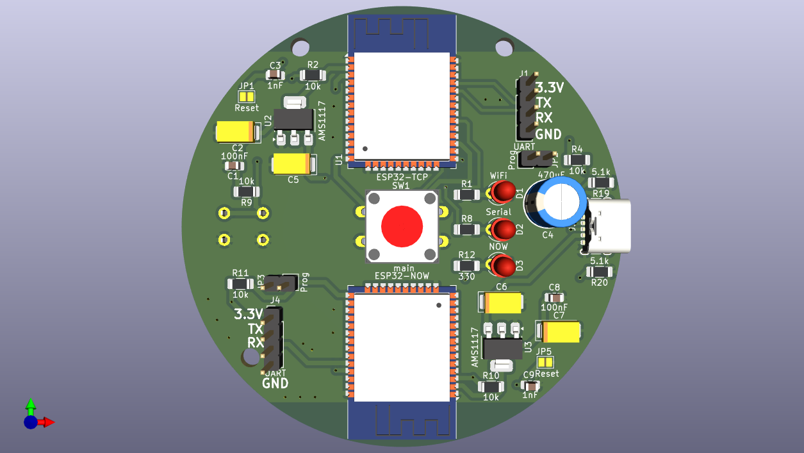
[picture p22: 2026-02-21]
Hardware-designs/Gateway_v1.1/Gateway_v1.1_front.png

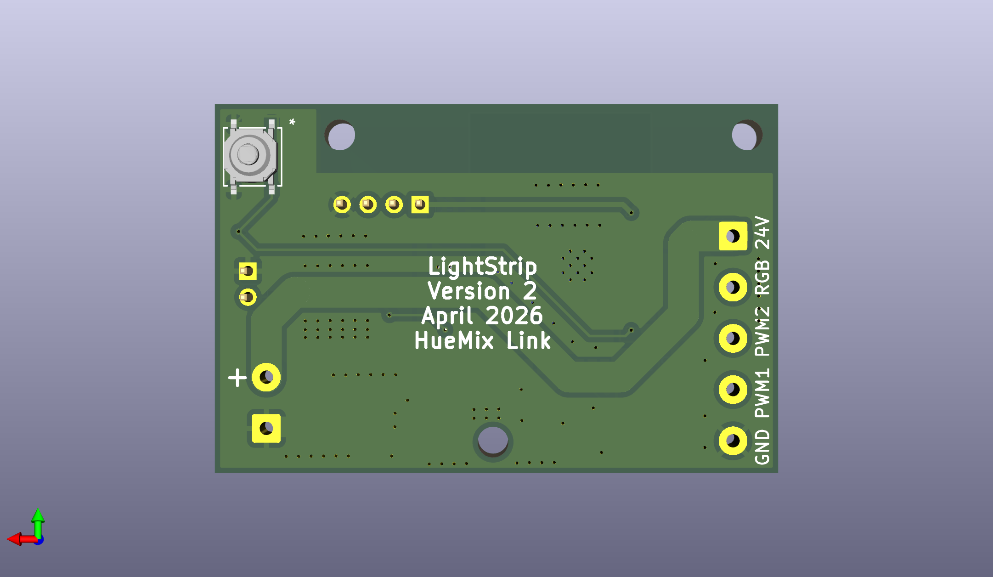
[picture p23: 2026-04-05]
Hardware-designs/Lightstrip/Lightstrip_back.png

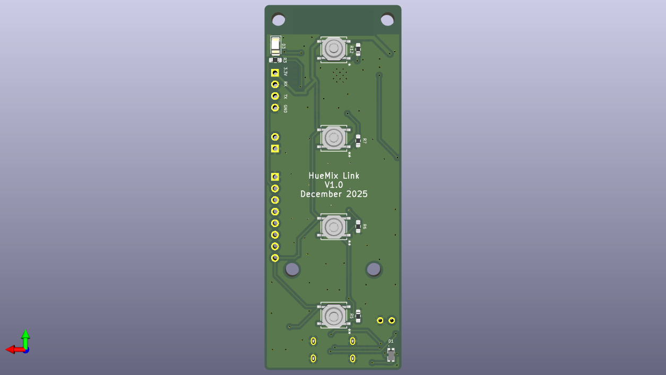
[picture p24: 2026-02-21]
Hardware-designs/Remote_4button_v1/Remote_4button_v1_back.png

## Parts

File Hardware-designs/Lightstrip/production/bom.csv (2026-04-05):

Designator | Footprint | Quantity | Value | LCSC Part #
C1 | 0603 | 1 | 68nF
C10, C13, C2 | 0603 | 3 | 100nF
C11 | 1206 | 1 | 4.7uFx25V
C12 | 1206 | 1 | 22uFx10V
J1 | TerminalBlock_MaiXu_MX126-5.0-02P_1x02_P5.00mm | 1 | In 24V
J3 | PinHeader_1x04_P2.54mm_Vertical | 1 | UART
J4 | TerminalBlock_MaiXu_MX126-5.0-05P_1x05_P5.00mm | 1 | lamps
JP2 | PinHeader_1x02_P2.54mm_Vertical | 1 | Prog
L1 | WE-LQSH_4020 | 1 | WE-LQSH_4020
Q1, Q2 | SOT95P280X125-3N | 2 | AO3400A
R1, R3, R4 | 1206 | 3 | 10K
R14 | 1206 | 1 | 412k
R15 | 1206 | 1 | 200k
R2, R5 | 1206 | 2 | 100
SW1, SW2 | SMT_FS | 2 | PTS526 SM15 SMTR2 LFS
U1 | IC_TPS560430X3FDBVT | 1 | TPS560430X3FDBVT
U2 | ESP32-WROOM-32D | 1 | ESP32-WROOM-32E

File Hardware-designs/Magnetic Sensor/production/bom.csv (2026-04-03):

Designator | Footprint | Quantity | Value | LCSC Part #
BT1 | BAT_BH123A | 1 | BH123A
C1 | 0603 | 1 | 22uF
C2 | CAPC2012X145N | 1 | 47uF
C3 | 0805 | 1 | 68nF
C4, C6 | 0805 | 2 | 100nF
C5 | 0603 | 1 | 100nF
D3 | 1206 | 1 | LED
J1 | PinHeader_1x04_P2.54mm_Vertical | 1 | UART
J2 | JST_EH_B2B-EH-A_1x02_P2.50mm_Vertical | 1 | JST_02
J3 | PinHeader_1x05_P2.54mm_Vertical | 1 | JST_05
JP2 | PinHeader_1x02_P2.54mm_Vertical | 1 | Prog
L1 | L_Murata_DFE201610P | 1 | L
Q1 | SOT-23 | 1 | AO3407A
R1 | 0805 | 1 | 200k
R10, R2, R4, R9 | 0805 | 4 | 10k
R12, R15, R16 | 0805 | 3 | 4.7k
R13, R8 | 0805 | 2 | 1M
R14 | 0805 | 1 | 300k
R3 | 0805 | 1 | 330
R5 | R_LDR_5.1x4.3mm_P3.4mm_Vertical | 1 | LDR07
R6 | 0805 | 1 | 470k
R7 | 0805 | 1 | 75k
SW1 | SW_SPST_REED_CT10-XXXX-G2 | 1 | SW_Reed_Opener
SW2 | SMT_FS | 1 | PTS526 SM15 SMTR2 LFS
U1 | ESP32-WROOM-32D | 1 | ESP32-WROOM-32
U2 | IC_TPS63021DSJR | 1 | TPS63021DSJR

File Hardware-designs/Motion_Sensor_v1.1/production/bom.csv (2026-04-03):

Designator | Footprint | Quantity | Value | LCSC Part #
A1 | TO254P940H490-3 | 1 | IRA-S410ST01
C1, C4, C6 | 0805 | 3 | 100nF
C2 | CP_EIA-6032-15_Kemet-U_HandSolder | 1 | 220uF
C3 | 0805 | 1 | 68nF
C5 | CP_EIA-6032-15_Kemet-U_HandSolder | 1 | 22uF
D1 | APHBM2012ETSGTC | 1 | LED_Dual_AKKA
D3 | 1206 | 1 | LED
J1 | PinHeader_1x04_P2.54mm_Vertical | 1 | UART
J2 | TestPoint_2Pads_Pitch2.54mm_Drill0.8mm | 1 | Bat
J3 | USB_C_Receptacle_GCT_USB4125-xx-x-0190_6P_TopMnt_Horizontal | 1 | USB_C
J4, J5 | PinHeader_1x04_P2.54mm_Vertical | 2 | I2C
JP2 | PinHeader_1x02_P2.54mm_Vertical | 1 | Prog
Q1 | SOT-23 | 1 | AO3407A
R1, R11 | 1206 | 2 | 5.1k
R10 | 1206 | 1 | 3.9k
R12, R15, R16 | 1206 | 3 | 4.7k
R13 | 1206 | 1 | 1M
R14 | 1206 | 1 | 300k
R2, R4, R9 | 1206 | 3 | 10k
R3, R8 | 1206 | 2 | 330
R5 | R_LDR_5.1x4.3mm_P3.4mm_Vertical | 1 | LDR07
R6 | 1206 | 1 | 470k
R7 | 1206 | 1 | 75k
SW2 | SMT_FS | 1 | PTS526 SM15 SMTR2 LFS
U1 | ESP32-WROOM-32D | 1 | ESP32-WROOM-32
U2 | TSOT-23-6_HandSoldering | 1 | TP4057
U4 | SOT-23 | 1 | MCP1700

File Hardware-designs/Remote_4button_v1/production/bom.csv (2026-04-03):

Designator | Footprint | Quantity | Value | LCSC Part #
C1, C4 | 0805 | 2 | 100nF
C2 | CP_EIA-6032-15_Kemet-U_HandSolder | 1 | 220uF
C3 | 0805 | 1 | 68nF
C5 | CP_EIA-6032-15_Kemet-U_HandSolder | 1 | 22uF
D1 | APHBM2012ETSGTC | 1 | LED_Dual_AKKA
D3 | 1206 | 1 | LED
J1 | PinHeader_1x04_P2.54mm_Vertical | 1 | UART
J2 | TestPoint_2Pads_Pitch2.54mm_Drill0.8mm | 1 | Bat
J3 | USB_C_Receptacle_GCT_USB4125-xx-x-0190_6P_TopMnt_Horizontal | 1 | USB_C
J4 | PinHeader_1x08_P2.54mm_Vertical | 1 | Conn_01x08_Pin
JP2 | PinHeader_1x02_P2.54mm_Vertical | 1 | Prog
R1, R11 | 0603 | 2 | 5.1k
R10 | 0603 | 1 | 3.9k
R12, R2, R4, R5, R6, R7, R9 | 0603 | 7 | 10k
R13 | 0603 | 1 | 1M
R14 | 0603 | 1 | 300
R3, R8 | 0603 | 2 | 330
SW1, SW2, SW3, SW4, SW5 | SMT_FS | 5 | PTS526 SM15 SMTR2 LFS
U1 | ESP32-WROOM-32D | 1 | ESP32-WROOM-32
U2 | TSOT-23-6_HandSoldering | 1 | TP4057
U3 | SOT-23 | 1 | MCP1700T-1202E-TT

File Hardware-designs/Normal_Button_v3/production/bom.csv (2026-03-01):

Designator | Footprint | Quantity | Value | LCSC Part #
C1, C4 | 0805 | 2 | 100nF
C2 | CP_EIA-6032-15_Kemet-U_HandSolder | 1 | 220uF
C3 | 0805 | 1 | 1nF
C5 | CP_EIA-6032-15_Kemet-U_HandSolder | 1 | 22uF
D1, D3, D4, D5 | LED_D3.0mm | 4 | LED
J1 | PinHeader_1x04_P2.54mm_Vertical | 1 | UART
J2 | JST_EH_B2B-EH-A_1x02_P2.50mm_Vertical | 1 | Bat
J3 | USB_C_Receptacle_GCT_USB4125-xx-x-0190_6P_TopMnt_Horizontal | 1 | USB_C
JP1 | SolderJumper-2_P1.3mm_Open_Pad1.0x1.5mm | 1 | Reset
JP2 | PinHeader_1x02_P2.54mm_Vertical | 1 | Prog
LED1 | LED_D5.0mm-4_RGB | 1 | Everlight_EASV3015RGBA0
Q1 | SOT-23 | 1 | MMBT3904
R1, R10, R11, R12, R15 | 1206 | 5 | 330
R13, R14, R18, R2, R4, R8, R9 | 1206 | 7 | 10k
R16, R17 | 1206 | 2 | 5.1k
R19 | 1206 | 1 | 100k
R3 | 1206 | 1 | 1k
R5 | 1206 | 1 | 3.9k
R6 | 1206 | 1 | 1M
R7 | 1206 | 1 | 300k
SW1 | SW_PUSH-12mm | 1 | main
SW2 | SW_PUSH_6mm | 1 | Aux
SW3 | SW_PUSH-12mm | 1 | Side 1
SW4 | SW_PUSH-12mm | 1 | Side 2
U1 | ESP32-WROOM-32E | 1 | ESP32-WROOM-32
U2 | TSOT-23-6_HandSoldering | 1 | TP4057
U4 | SOT-23 | 1 | MCP1700T-3302E/TT

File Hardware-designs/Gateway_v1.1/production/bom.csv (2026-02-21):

Designator | Footprint | Quantity | Value | LCSC Part #
C1, C8 | 0805 | 2 | 100nF
C2, C7 | CP_EIA-6032-15_Kemet-U_HandSolder | 2 | 220uF
C3, C9 | 0805 | 2 | 1nF
C4 | CP_Radial_D8.0mm_P3.50mm | 1 | 470uF
C5, C6 | CP_EIA-6032-15_Kemet-U_HandSolder | 2 | 22uF
D1 | LED_D3.0mm | 1 | WiFi
D2 | LED_D3.0mm | 1 | Serial
D3 | LED_D3.0mm | 1 | NOW
J1, J4 | PinHeader_1x04_P2.54mm_Vertical | 2 | UART
J3 | USB_C_Receptacle_GCT_USB4125-xx-x-0190_6P_TopMnt_Horizontal | 1 | USB_C
JP1, JP5 | SolderJumper-2_P1.3mm_Open_Pad1.0x1.5mm | 2 | Reset
JP2, JP3 | PinHeader_1x02_P2.54mm_Vertical | 2 | Prog
R1, R12, R8 | 1206 | 3 | 330
R10, R11, R2, R4, R9 | 1206 | 5 | 10k
R19, R20 | 1206 | 2 | 5.1k
SW1 | SW_PUSH-12mm | 1 | main
SW2 | SW_PUSH_6mm | 1 | Aux
U1 | ESP32-WROOM-32 | 1 | ESP32-TCP
U2, U3 | SOT-223-3_TabPin2 | 2 | AMS1117
U4 | ESP32-WROOM-32 | 1 | ESP32-NOW

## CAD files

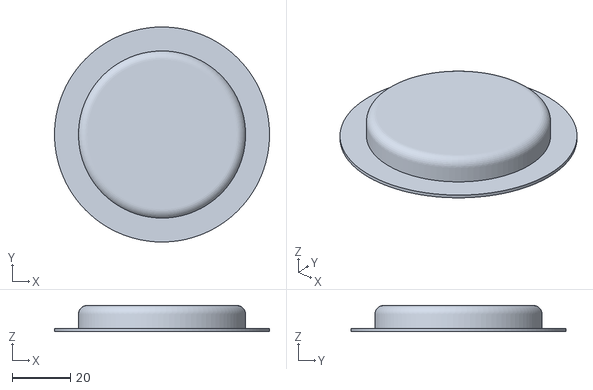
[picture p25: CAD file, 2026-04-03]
3D Files/Buttons/1_Button/Button_1_Button.stl
74.0 x 74.0 x 9.00

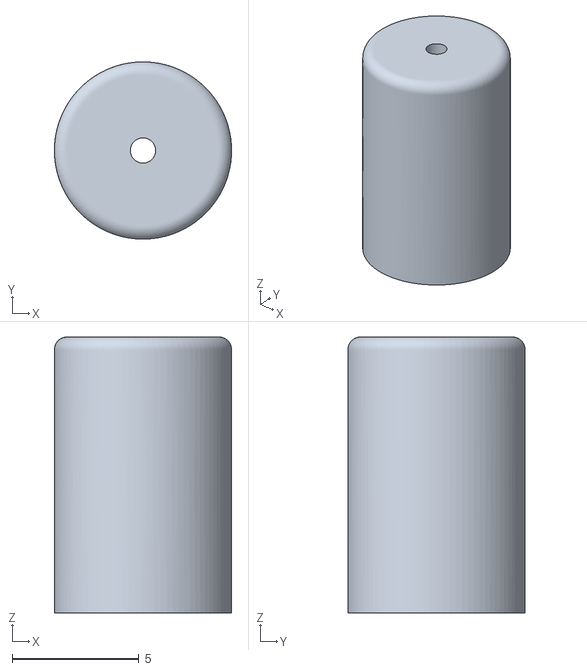
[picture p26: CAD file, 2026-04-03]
3D Files/Buttons/2_Button/Axle 2_2 buttons.stl
7.00 x 7.00 x 10.9

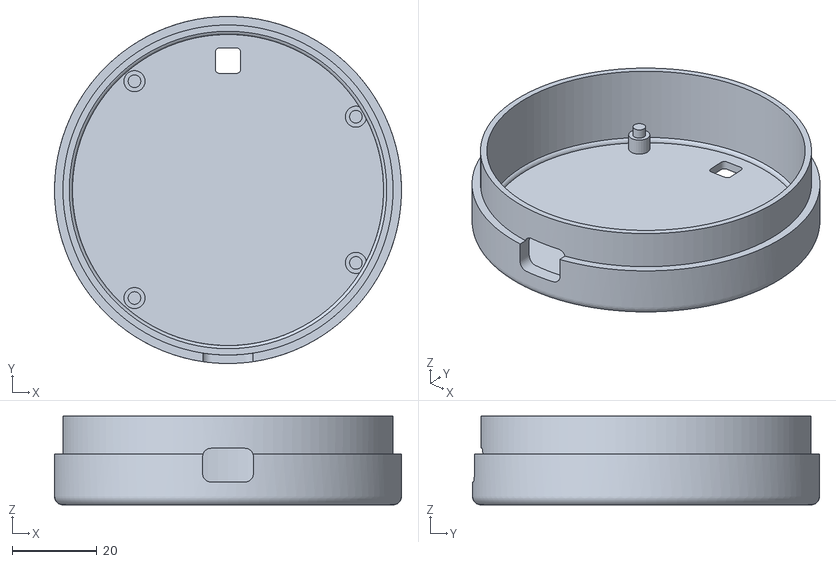
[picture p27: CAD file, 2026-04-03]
3D Files/Buttons/3_Button/Base_3 buttons.stl
82.0 x 82.0 x 21.0

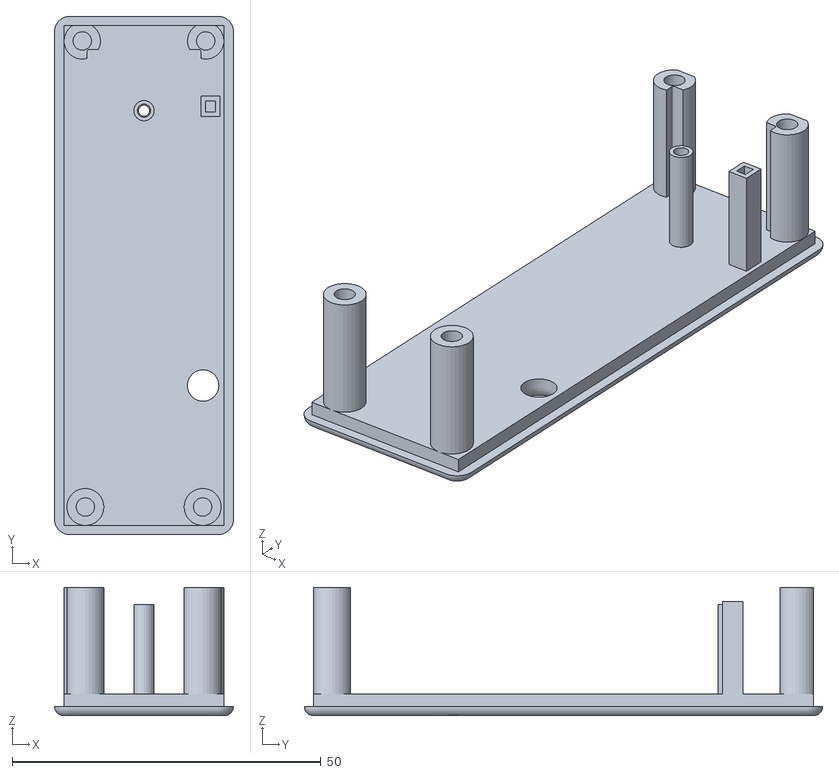
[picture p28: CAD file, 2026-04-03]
3D Files/Door Sensor/Lid Magnetic Sensor.stl
29.0 x 84.0 x 20.8

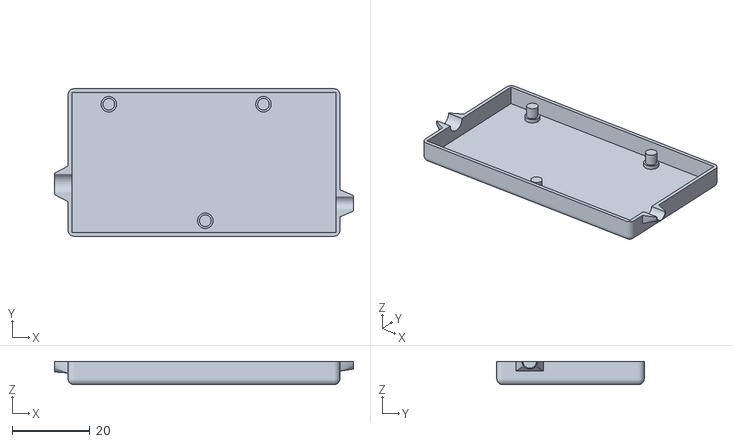
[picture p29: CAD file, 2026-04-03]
3D Files/Lightstrip/Base Lightstrip controller.stl
77.0 x 38.0 x 6.00

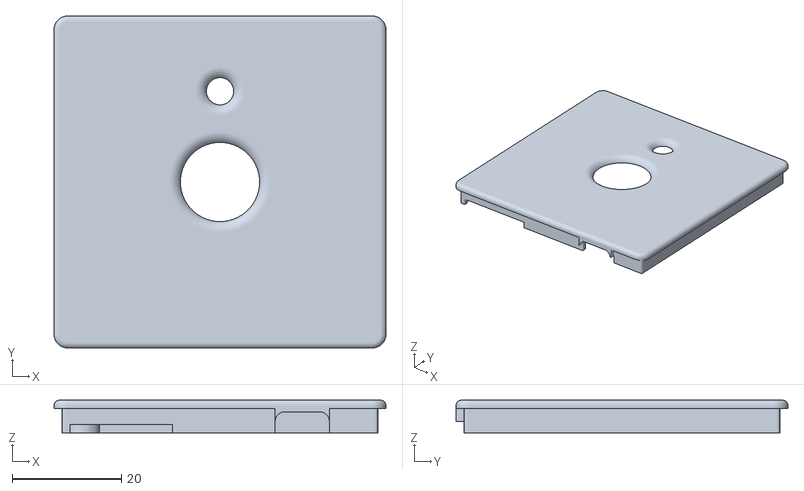
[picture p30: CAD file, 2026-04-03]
3D Files/Motion Sensor/Lid Motion Sensor_14mm.stl
60.8 x 60.8 x 6.00

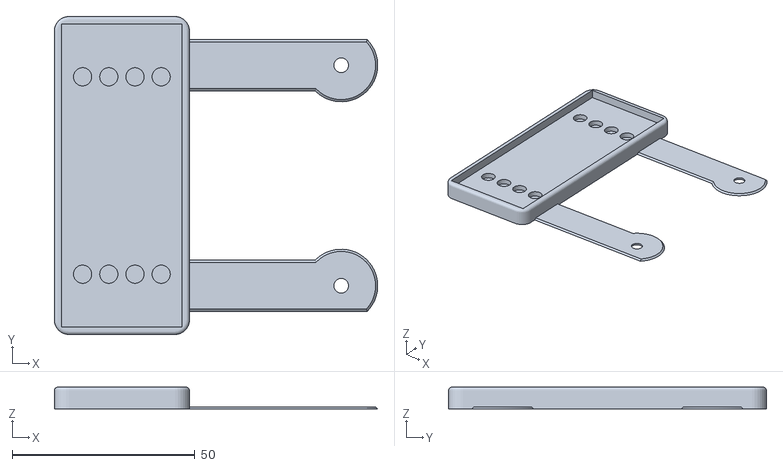
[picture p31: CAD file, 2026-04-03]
3D Files/Remote/Remote Holder.stl
88.5 x 87.0 x 6.00

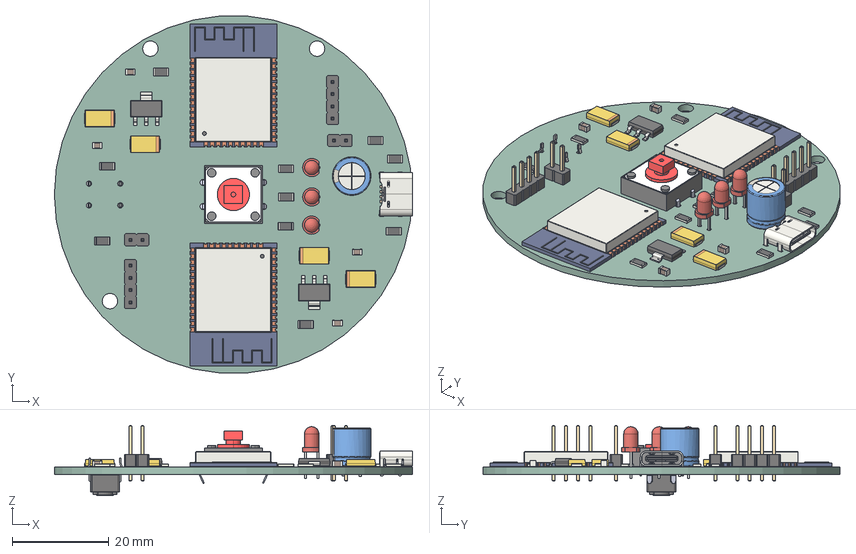
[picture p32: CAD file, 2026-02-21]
Hardware-designs/Gateway_v1.1/Gateway_v1.1.step
74.3 x 74.0 x 14.5 mm
CP_EIA-6032-15_Kemet-U x 4
USB_C_Receptacle_GCT_USB4125-xx-x-0190_6P_TopMnt_Horizontal
SOT-223 x 2
PinHeader_1x04_P2.54mm_Vertical x 2
R_1206_3216Metric x 10
Body002 (Mirror #1)
Body003 (Mirror #2)
C_0805_2012Metric x 4
PinHeader_1x02_P2.54mm_Vertical x 2
ESP32-WROOM-32 x 2
LED_D3.0mm x 3
CP_Radial_D8.0mm_P3.50mm
SW_PUSH_6mm
Gateway_v1.1_PCB

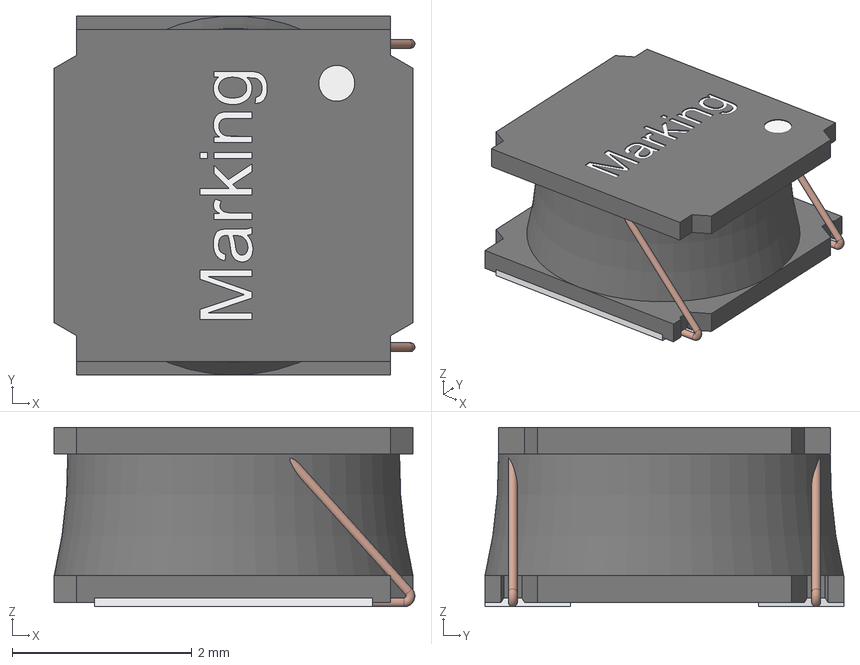
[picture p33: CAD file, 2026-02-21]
Hardware-designs/Lightstrip/components/74405042100/WE-LQSH_4020.step
4.02 x 4.00 x 2.00 mm
housing
contact x 2
Glue
Wire x 2

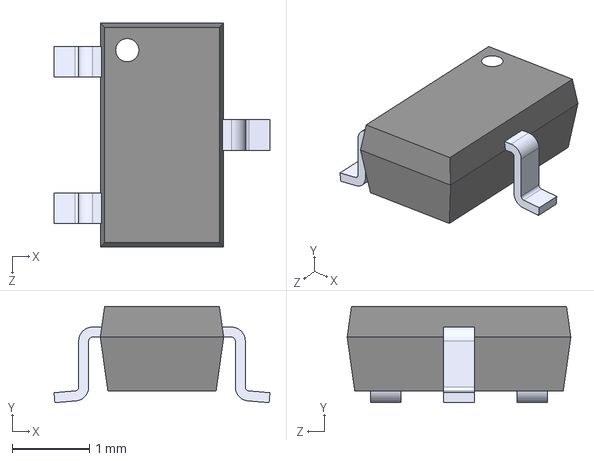
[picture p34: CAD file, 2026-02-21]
Hardware-designs/Lightstrip/components/AO3400A/AO3400A.step
2.80 x 1.25 x 2.90 mm

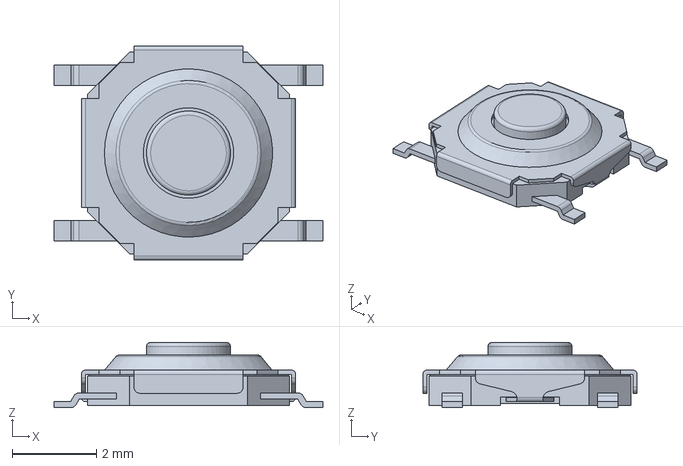
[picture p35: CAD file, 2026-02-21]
Hardware-designs/Lightstrip/components/PTS526_SM15_SMTR2_LFS/PTS526SK15SMTR2_LFS.stp
6.40 x 5.10 x 1.55 mm

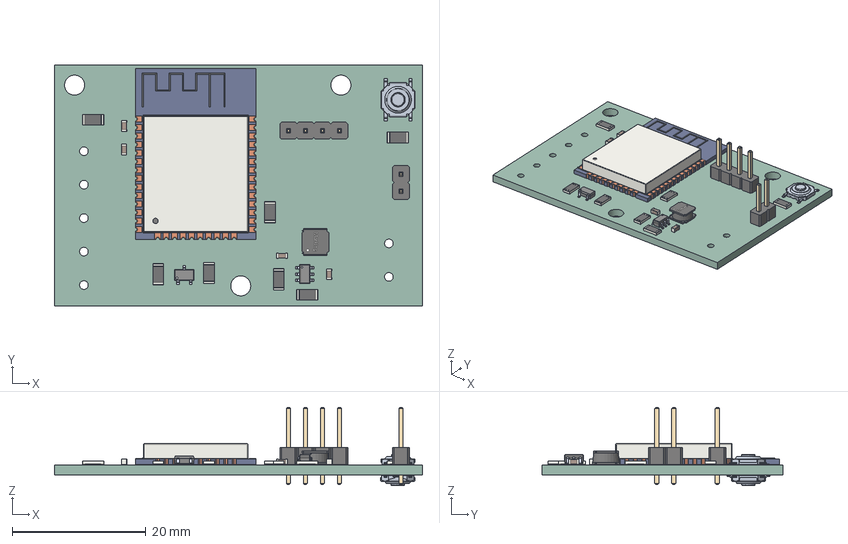
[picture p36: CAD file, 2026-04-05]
Hardware-designs/Lightstrip/Lightstrip.step
55.0 x 36.0 x 11.7 mm
R_1206_3216Metric x 7
ESP32-WROOM-32
PinHeader_1x04_P2.54mm_Vertical
C_0603_1608Metric x 4
housing
contact x 2
Glue
Wire x 2
PinHeader_1x02_P2.54mm_Vertical
PTS526SK15SMTR2_LFS x 2
AO3400A
TPS560430X3FDBVT
Lightstrip_PCB

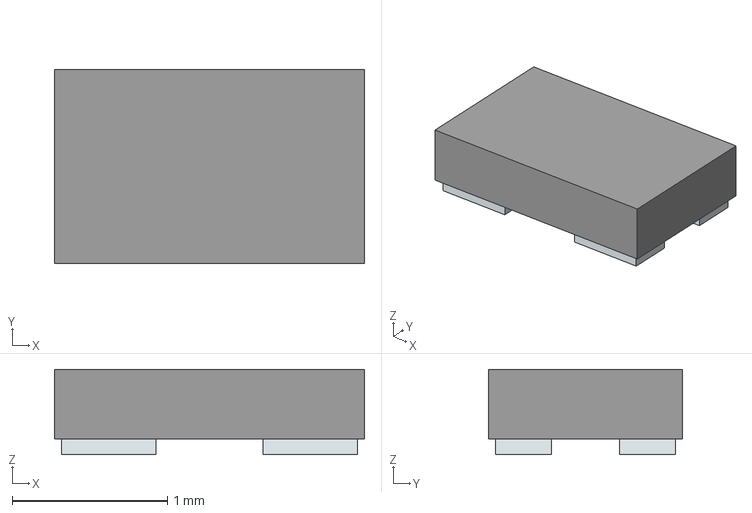
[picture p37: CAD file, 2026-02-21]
Hardware-designs/Magnetic Sensor/components/APHBM2012ETSGTC/APHBM2012ETSGTC.stp
2.00 x 1.25 x 0.55 mm
Pins

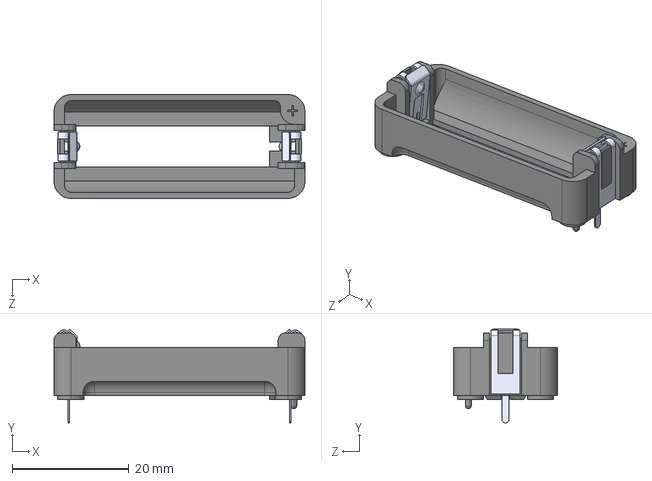
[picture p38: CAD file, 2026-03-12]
Hardware-designs/Magnetic Sensor/components/BH123A/BH123A.step
43.0 x 16.1 x 17.8 mm

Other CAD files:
3D Files/Gateway/Button Server.stl
Hardware-designs/Magnetic Sensor/components/C1608X5R1A226M080AC/C1608X5R1A226M080AC.step
Hardware-designs/Magnetic Sensor/components/IRA_S410ST01/IRA-S410ST01.step
Hardware-designs/Magnetic Sensor/components/MCP1700T_3302E_MB/SOT-23_MC_MCH.step
3D Files/Buttons/1_Button/Axle_1_Button.stl
3D Files/Buttons/1_Button/Base_1_Button.stl
3D Files/Buttons/1_Button/Lid_1_Button.stl
3D Files/Buttons/2_Button/Axle 1_2 buttons.stl
3D Files/Buttons/2_Button/Base_2 buttons.stl
3D Files/Buttons/2_Button/Circle button_2 buttons.stl
3D Files/Buttons/2_Button/Lid_2 buttons.stl
3D Files/Buttons/2_Button/Square button_2 buttons.stl
3D Files/Buttons/3_Button/Axle 1_3 buttons.stl
3D Files/Buttons/3_Button/Axle 2_3 buttons.stl
3D Files/Buttons/3_Button/Axle 3_3 buttons.stl
3D Files/Buttons/3_Button/Center button_3 buttons.stl
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

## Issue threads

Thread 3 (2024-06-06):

GPIO12 pull resistor

gmixich, 2024-06-06:
Don't install R3 (GPIO12 pull up resistor). ESP32 can't boot correctly when GPIO12 has the resistor installed. When running internal pull-up is activate for properly function of button.

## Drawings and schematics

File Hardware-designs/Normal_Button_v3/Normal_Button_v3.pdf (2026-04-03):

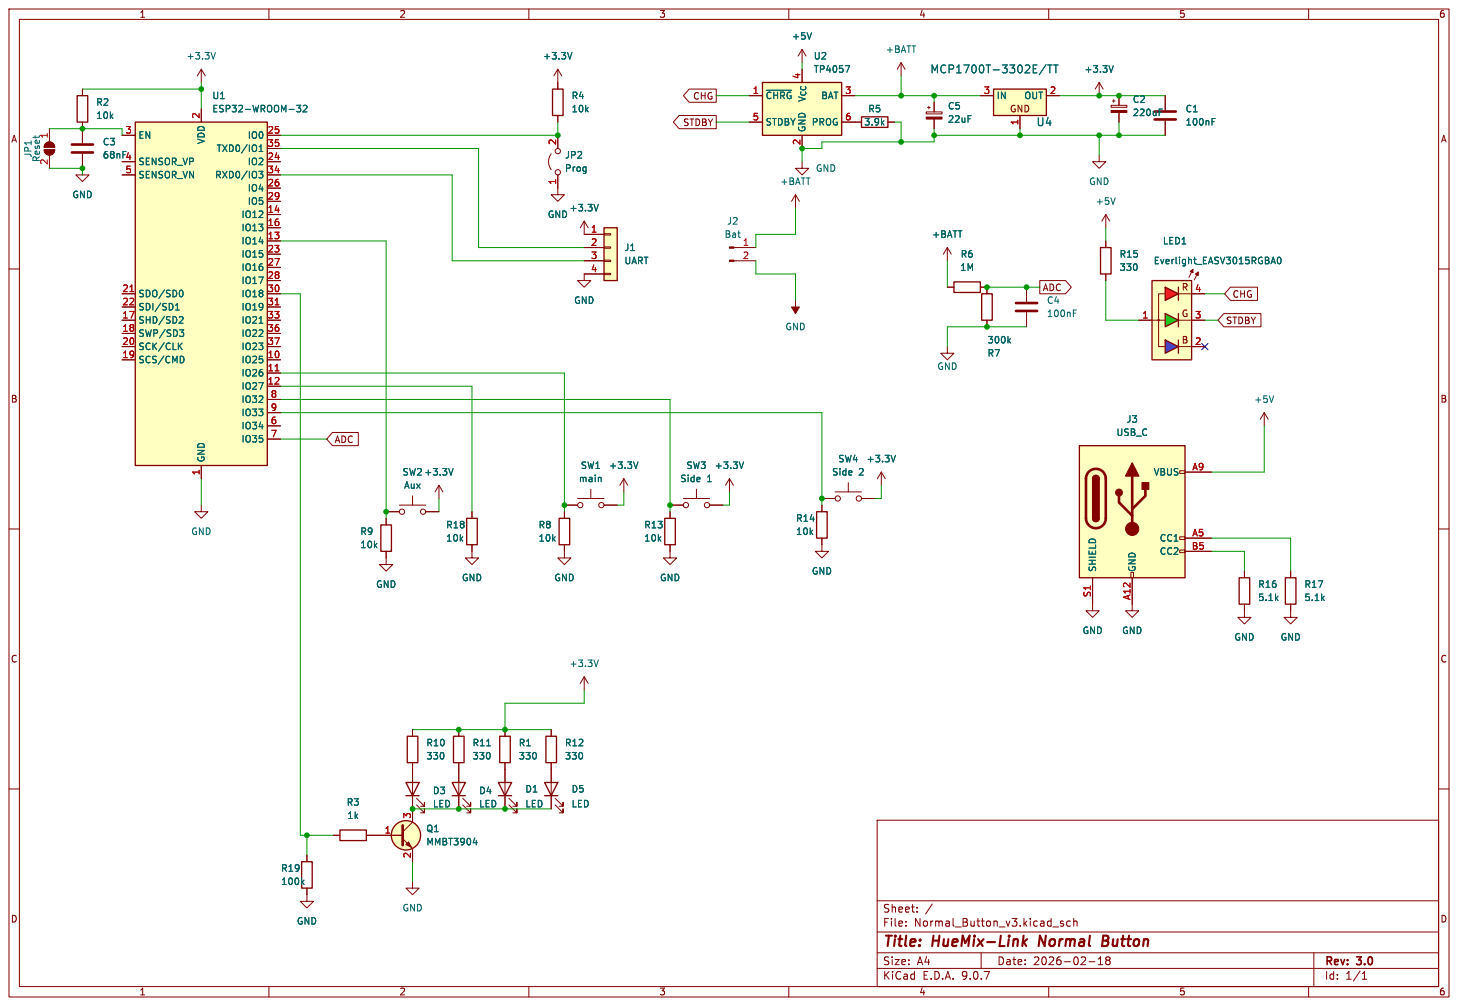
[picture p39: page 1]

1 2 +3.3V U2 TP4057 ~{CHRG} 1 STDBY 5 V_{CC} 4 GND

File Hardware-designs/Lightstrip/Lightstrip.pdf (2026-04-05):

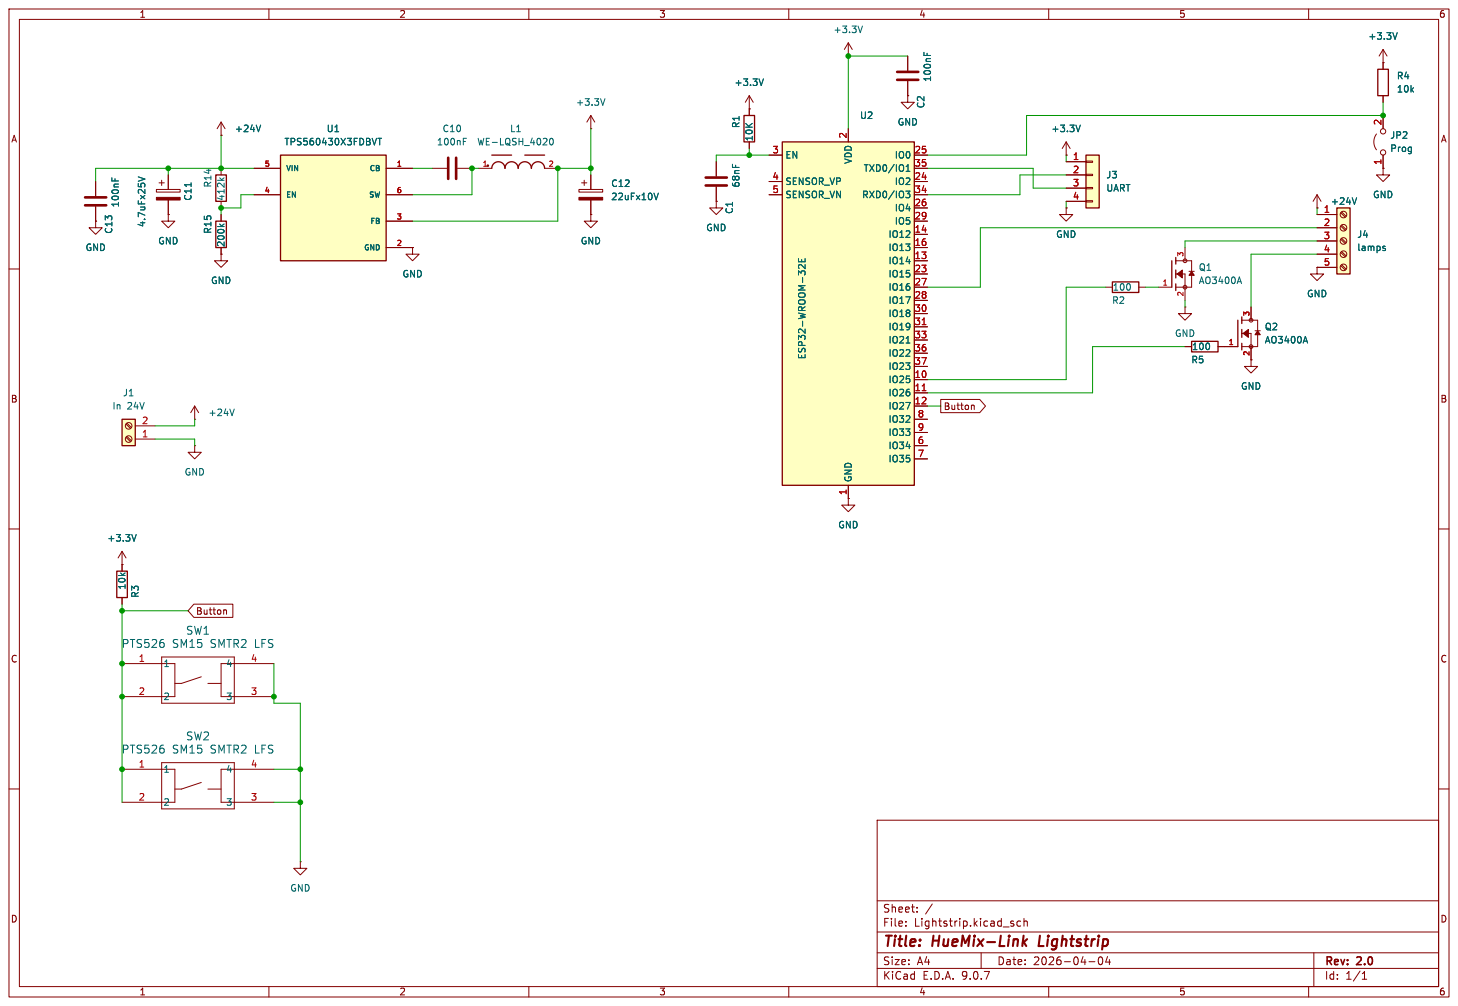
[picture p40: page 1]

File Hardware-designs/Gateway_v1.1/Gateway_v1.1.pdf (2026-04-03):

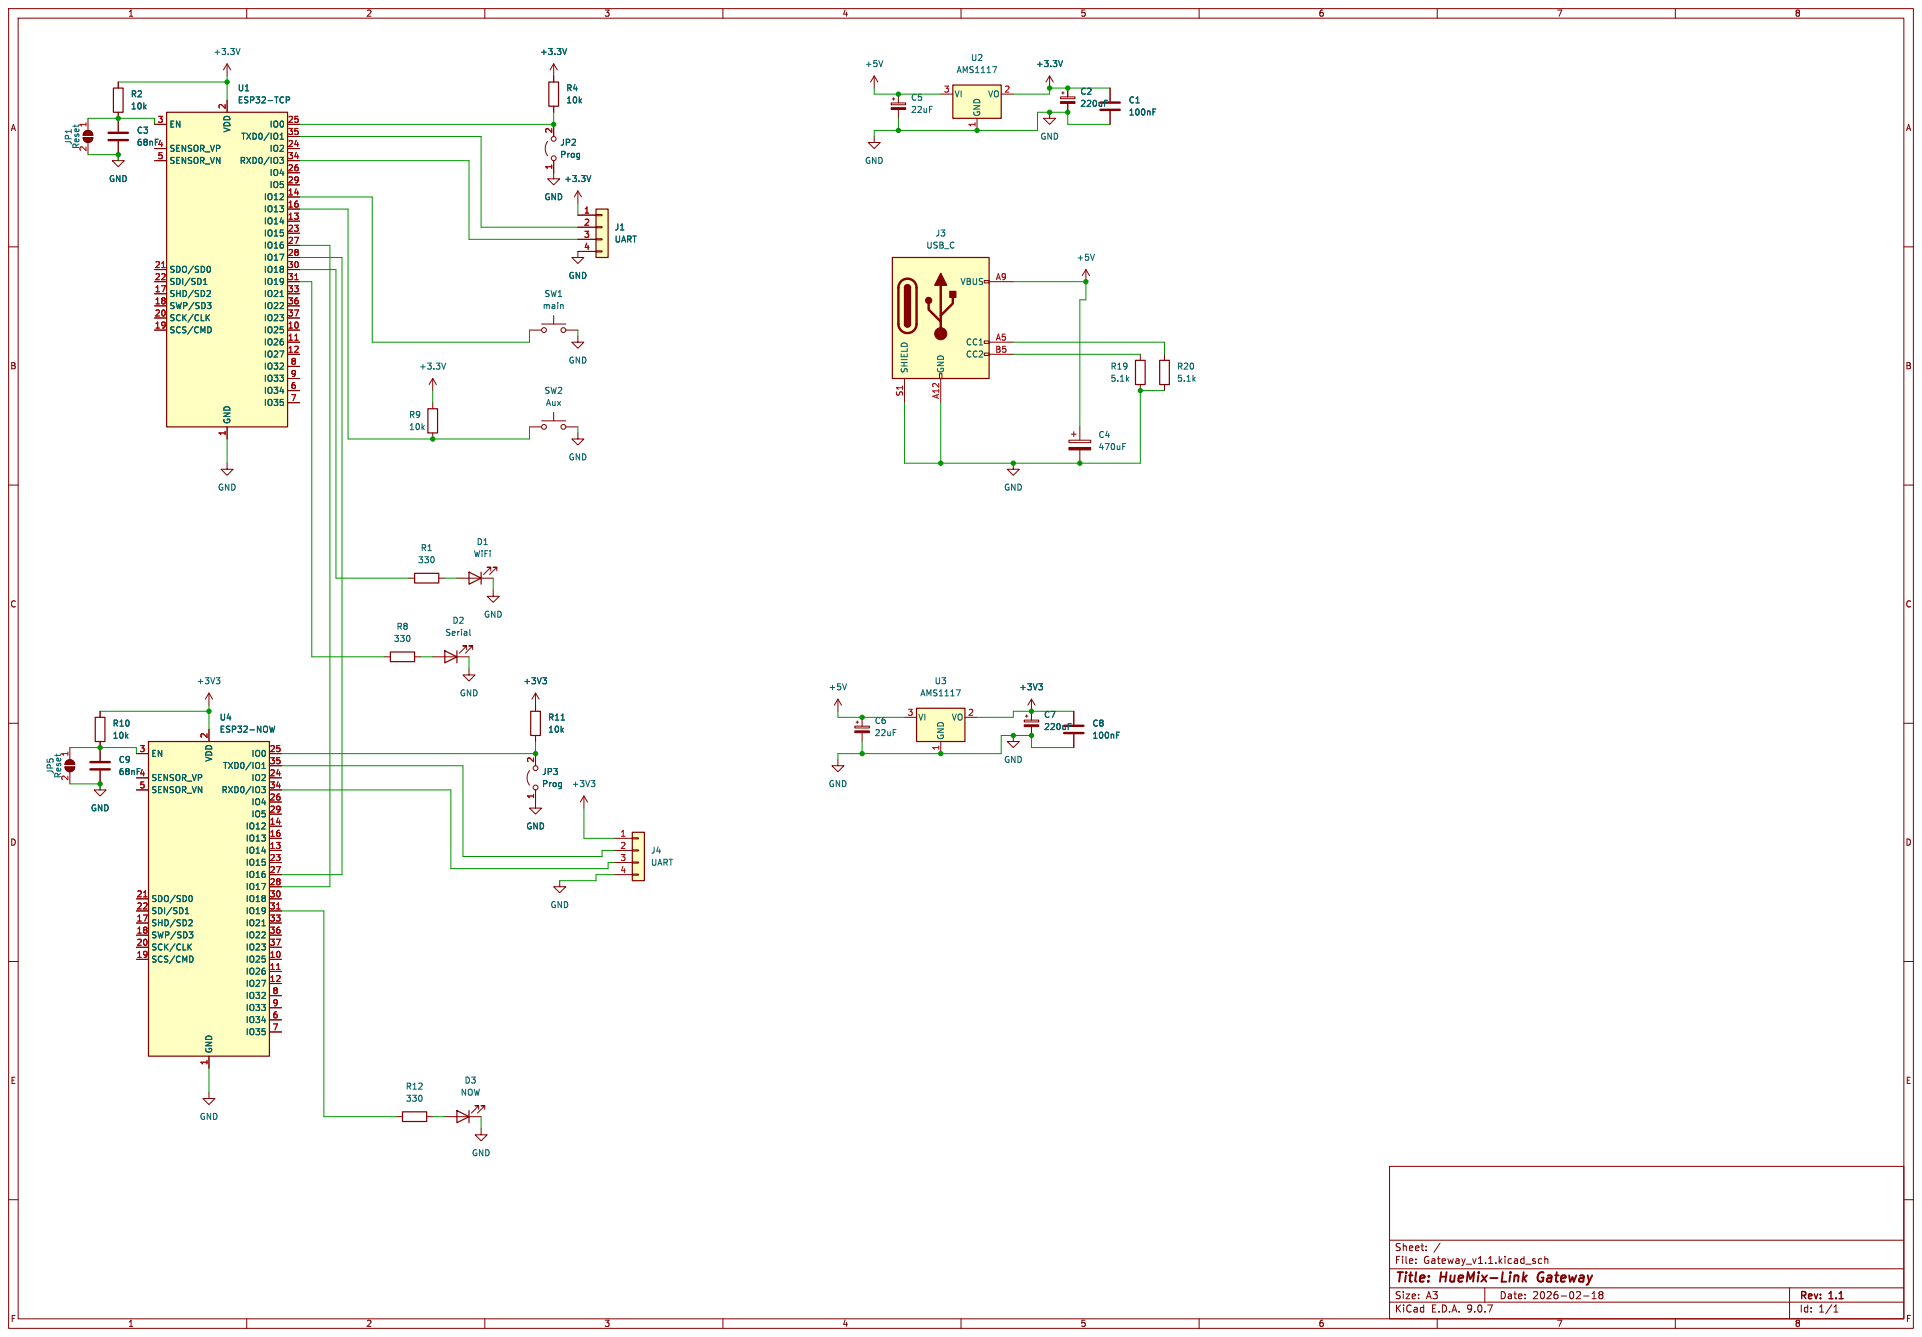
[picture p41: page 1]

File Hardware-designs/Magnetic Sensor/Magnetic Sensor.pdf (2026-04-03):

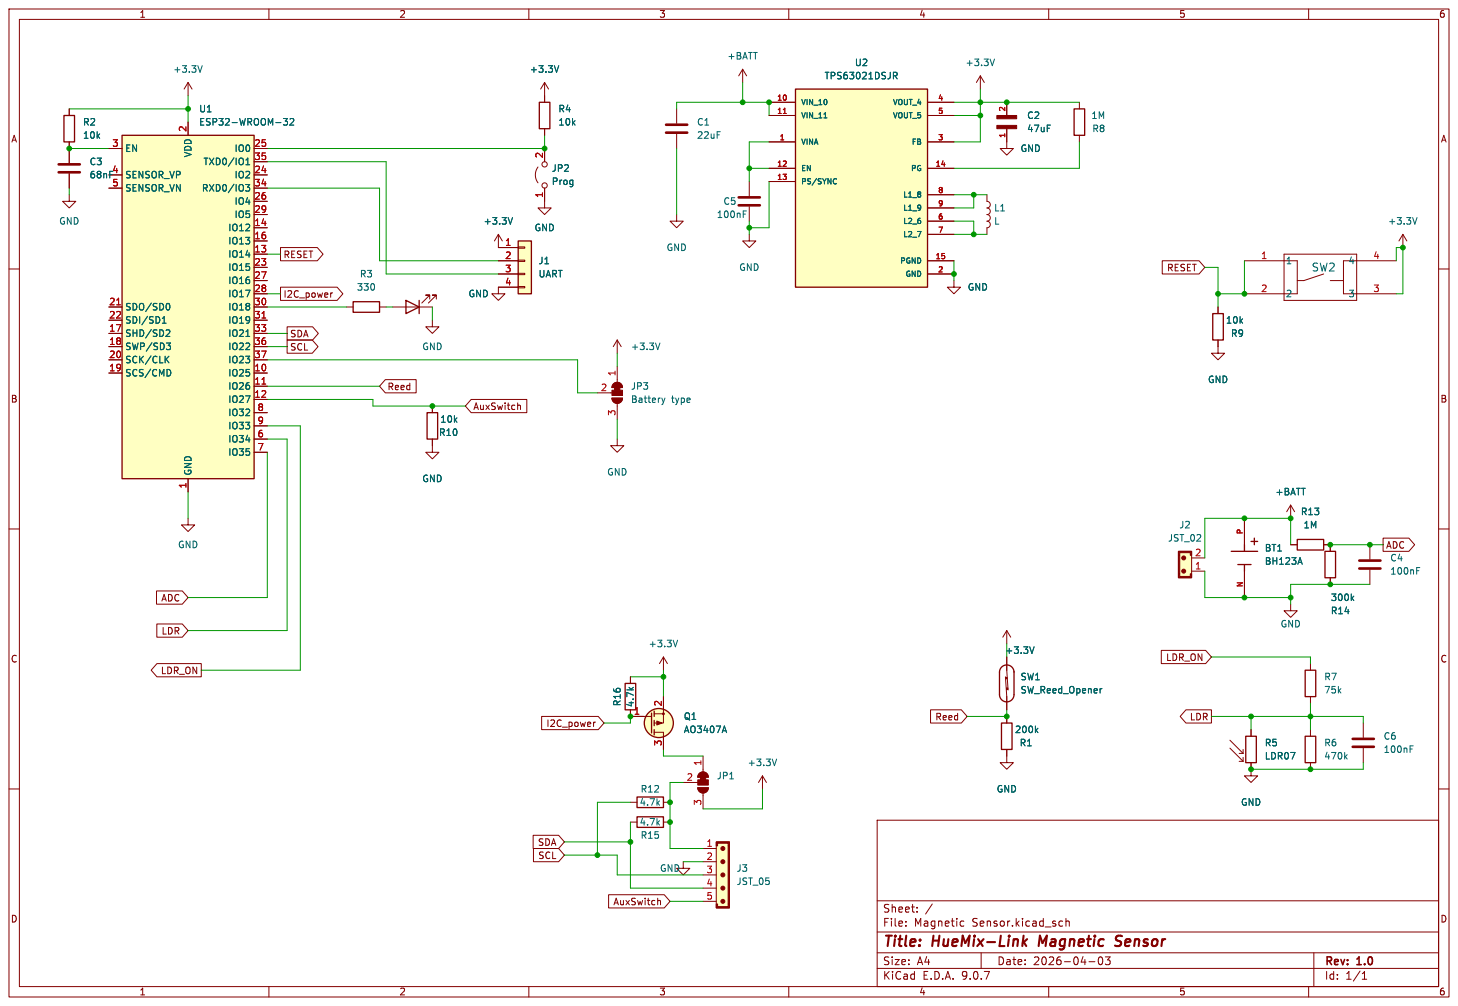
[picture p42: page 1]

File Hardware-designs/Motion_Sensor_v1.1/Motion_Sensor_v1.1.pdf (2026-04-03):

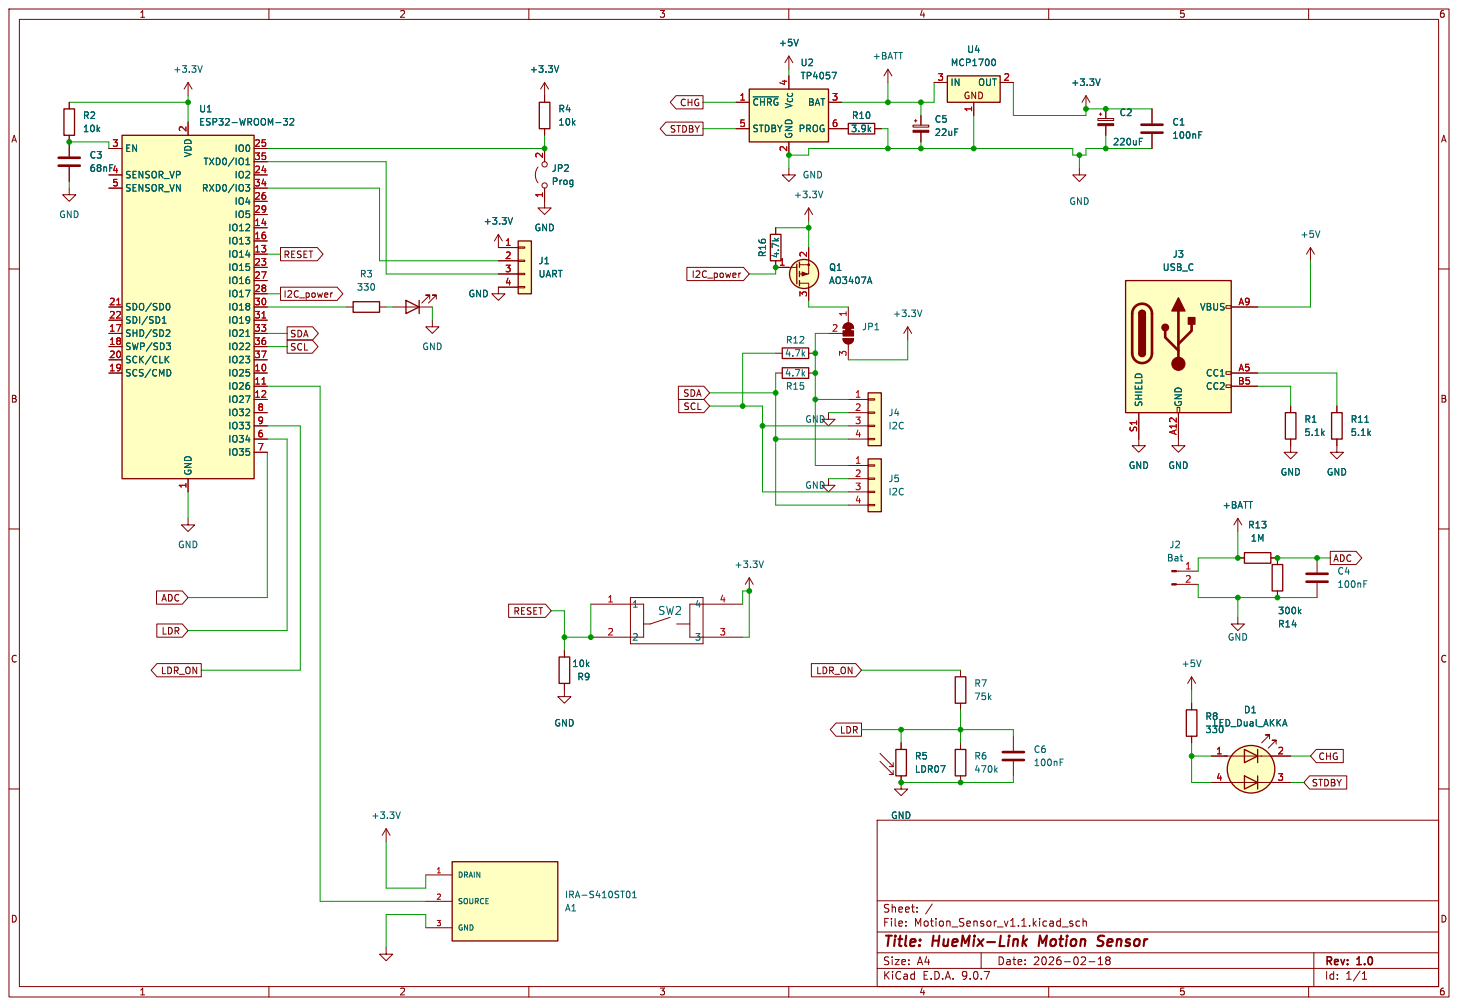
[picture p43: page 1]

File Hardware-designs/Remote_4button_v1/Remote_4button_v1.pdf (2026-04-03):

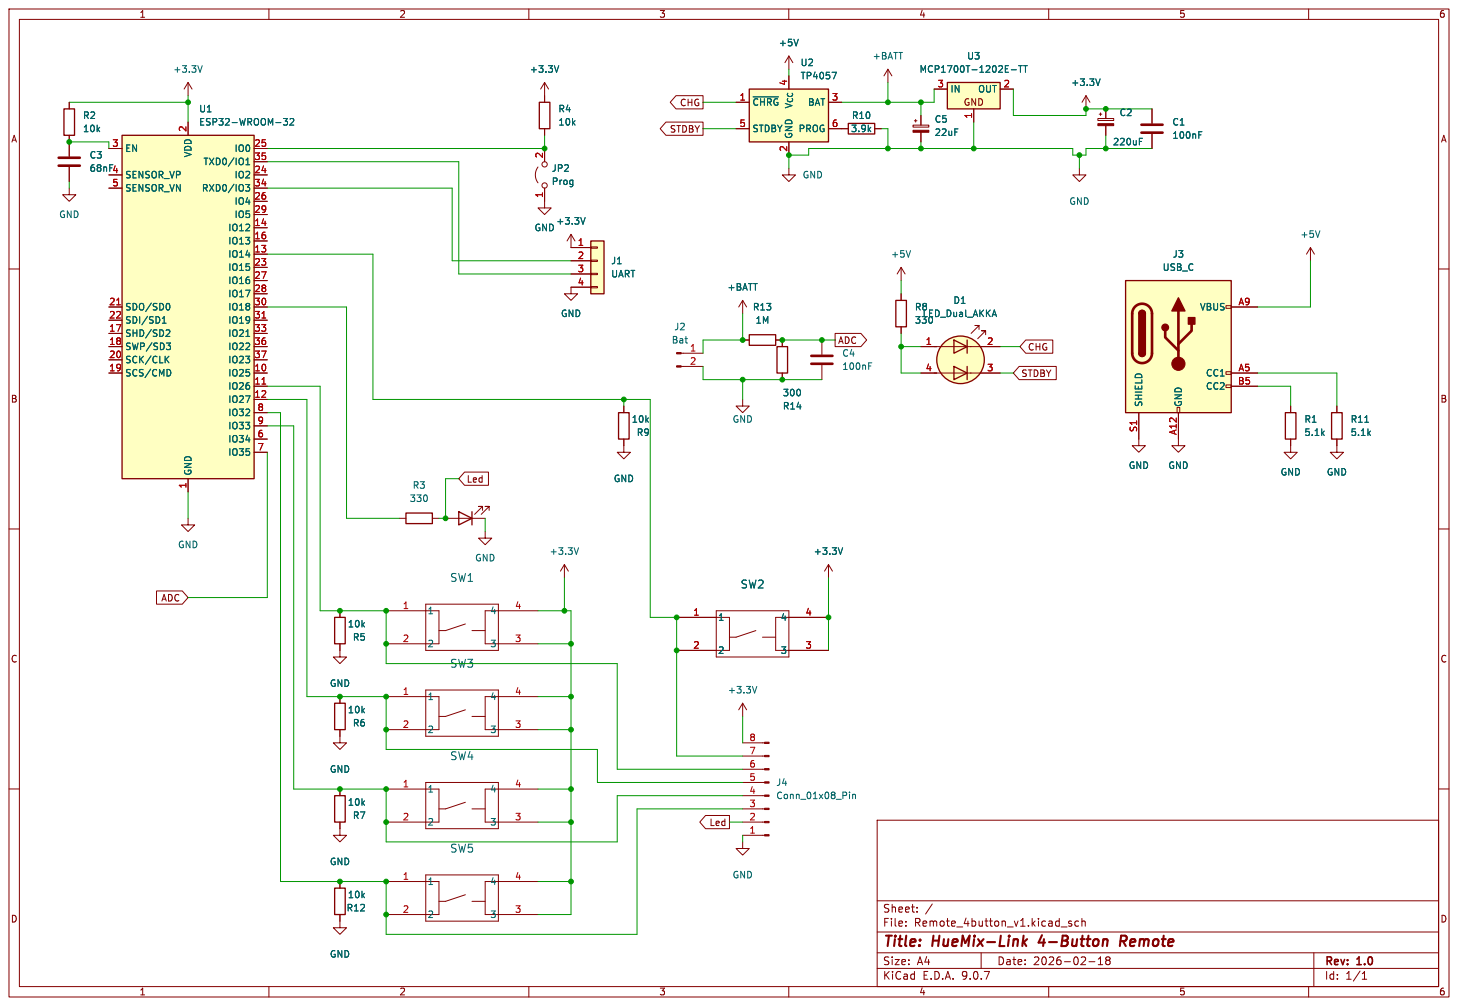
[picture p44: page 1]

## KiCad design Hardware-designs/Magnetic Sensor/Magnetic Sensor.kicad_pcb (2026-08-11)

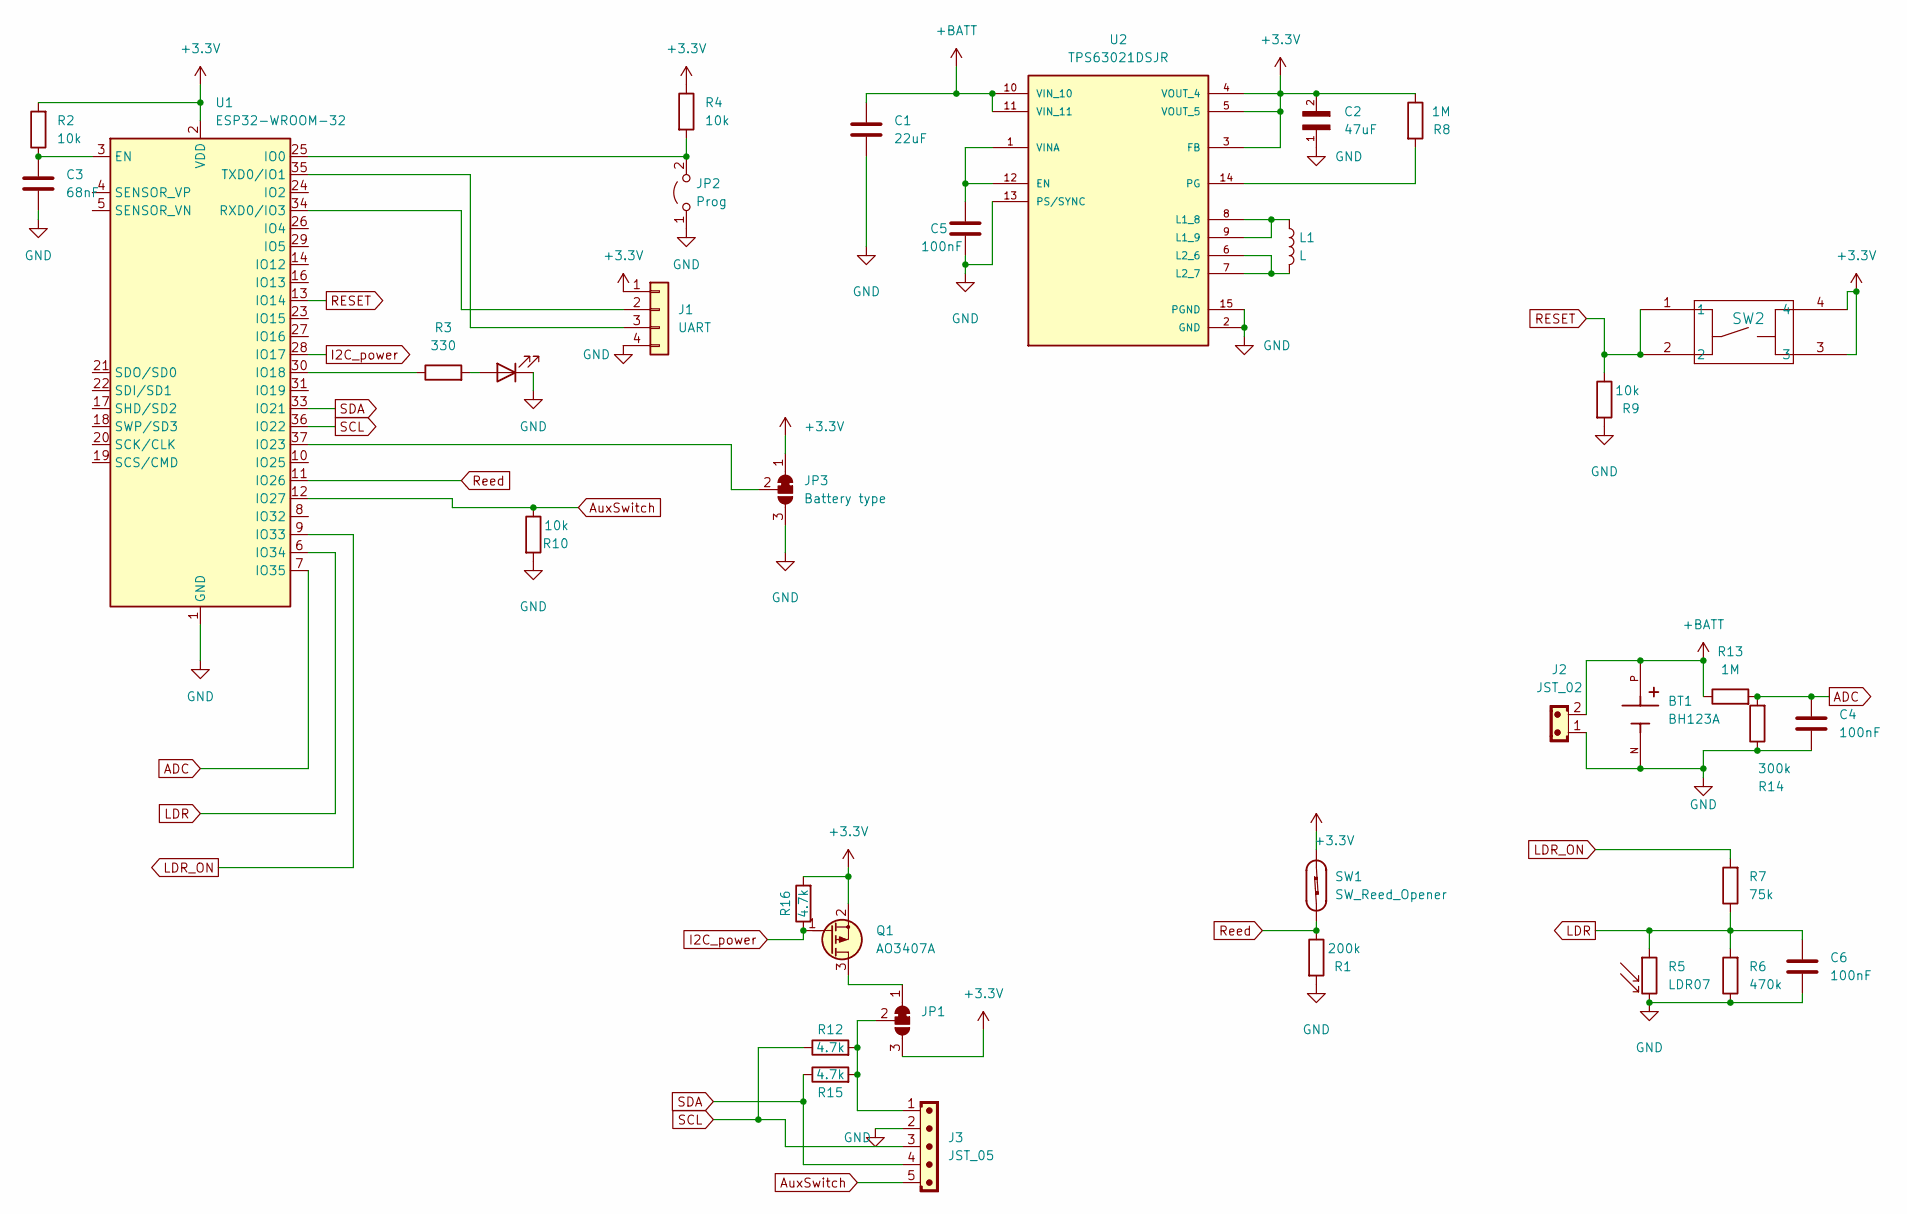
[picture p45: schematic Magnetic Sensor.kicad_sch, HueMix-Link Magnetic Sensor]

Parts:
BT1: BH123A; BAT_BH123A; PARTREV E
C1: 22uF; C_0603_1608Metric_Pad1.08x0.95mm_HandSolder
C2: 47uF; CAPC2012X145N; PARTREV NA
C3: 68nF; C_0805_2012Metric_Pad1.18x1.45mm_HandSolder
C4, C6: 100nF; C_0805_2012Metric_Pad1.18x1.45mm_HandSolder
C5: 100nF; C_0603_1608Metric_Pad1.08x0.95mm_HandSolder
D3: LED; LED_1206_3216Metric
J1: UART; PinHeader_1x04_P2.54mm_Vertical
J2: JST_02; JST_EH_B2B-EH-A_1x02_P2.50mm_Vertical
J3: JST_05; PinHeader_1x05_P2.54mm_Vertical
JP1: SolderJumper_3_Bridged12; SolderJumper-3_P1.3mm_Bridged12_RoundedPad1.0x1.5mm
JP2: Prog; PinHeader_1x02_P2.54mm_Vertical
JP3: Battery type; SolderJumper-3_P1.3mm_Bridged12_RoundedPad1.0x1.5mm
L1: L; L_Murata_DFE201610P
Q1: AO3407A; SOT-23
R1: 200k; R_0805_2012Metric_Pad1.20x1.40mm_HandSolder
R2, R4, R9, R10: 10k; R_0805_2012Metric_Pad1.20x1.40mm_HandSolder
R3: 330; R_0805_2012Metric_Pad1.20x1.40mm_HandSolder
R5: LDR07; R_LDR_5.1x4.3mm_P3.4mm_Vertical
R6: 470k; R_0805_2012Metric_Pad1.20x1.40mm_HandSolder
R7: 75k; R_0805_2012Metric_Pad1.20x1.40mm_HandSolder
R8, R13: 1M; R_0805_2012Metric_Pad1.20x1.40mm_HandSolder
R12, R15, R16: 4.7k; R_0805_2012Metric_Pad1.20x1.40mm_HandSolder
R14: 300k; R_0805_2012Metric_Pad1.20x1.40mm_HandSolder
SW1: SW_Reed_Opener; SW_SPST_REED_CT10-XXXX-G2
SW2: PTS526 SM15 SMTR2 LFS; SMT_FS
U1: ESP32-WROOM-32; ESP32-WROOM-32D
U2: TPS63021DSJR; IC_TPS63021DSJR; PARTREV I

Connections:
+3.3V: C2.2, J1.1, JP1.3 (B), JP3.1 (A), Q1.2 (S), R2.2, R4.1, R8.1, R16.2, SW1.2, SW2.3, SW2.4, U1.2 (VDD), U2.3 (FB), U2.4 (VOUT_4), U2.5 (VOUT_5)
+BATT: BT1.P, C1.1, J2.2, R13.1, U2.10 (VIN_10), U2.11 (VIN_11)
ADC: C4.1, R13.2, R14.2, U1.7 (IO35)
AuxSwitch: J3.5, R10.1, U1.12 (IO27)
GND: BT1.N, C1.2, C2.1, C3.2, C4.2, C5.2, C6.2, D3.1 (K), J1.4, J2.1, J3.2, JP2.1 (A), JP3.3 (B), R1.2, R5.2, R6.1, R9.2, R10.2, R14.1, U1.1 (GND), U1.15 (GND), U1.38 (GND), U1.39 (GND), U2.2 (GND), U2.13 (PS/SYNC), U2.15 (PGND)
I2C_power: Q1.1 (G), R16.1, U1.28 (IO17)
LDR: C6.1, R5.1, R6.2, R7.1, U1.6 (IO34)
LDR_ON: R7.2, U1.9 (IO33)
unnamed: D3.2 (A), R3.2
unnamed: J1.2, U1.34 (RXD0/IO3)
unnamed: J1.3, U1.35 (TXD0/IO1)
unnamed: JP1.1 (A), Q1.3 (D)
unnamed: J3.1, JP1.2 (C), R12.2, R15.2
unnamed: JP2.2 (B), R4.2, U1.25 (IO0)
unnamed: JP3.2 (C), U1.37 (IO23)
unnamed: C3.1, R2.1, U1.3 (EN)
unnamed: R3.1, U1.30 (IO18)
unnamed: C5.1, U2.1 (VINA), U2.12 (EN)
unnamed: L1.1, U2.8 (L1_8), U2.9 (L1_9)
unnamed: L1.2, U2.6 (L2_6), U2.7 (L2_7)
unnamed: R8.2, U2.14 (PG)
RESET: R9.1, SW2.1, SW2.2, U1.13 (IO14)
Reed: R1.1, SW1.1, U1.11 (IO26)
SCL: J3.3, R12.1, U1.36 (IO22)
SDA: J3.4, R15.1, U1.33 (IO21)

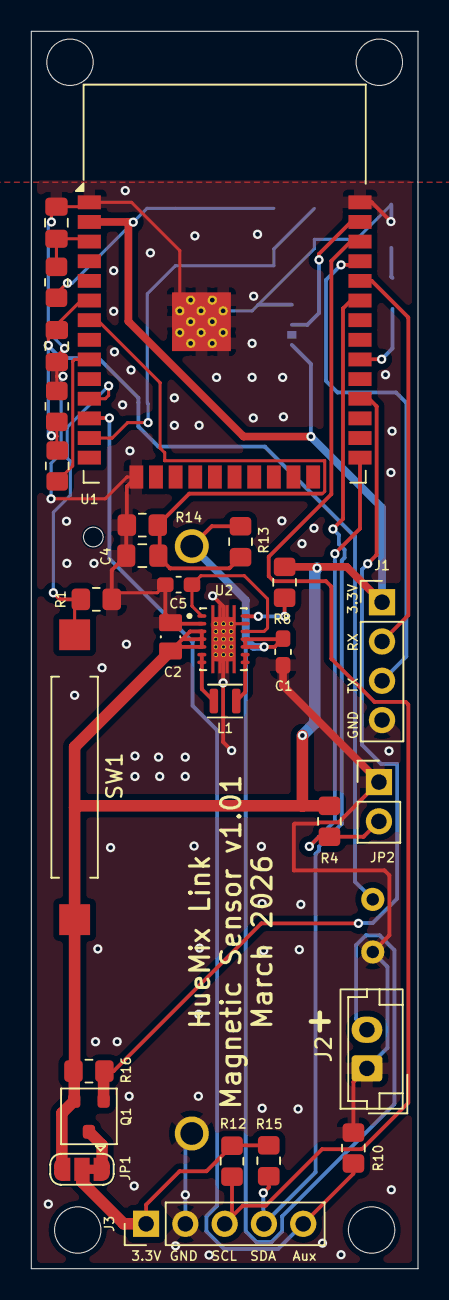
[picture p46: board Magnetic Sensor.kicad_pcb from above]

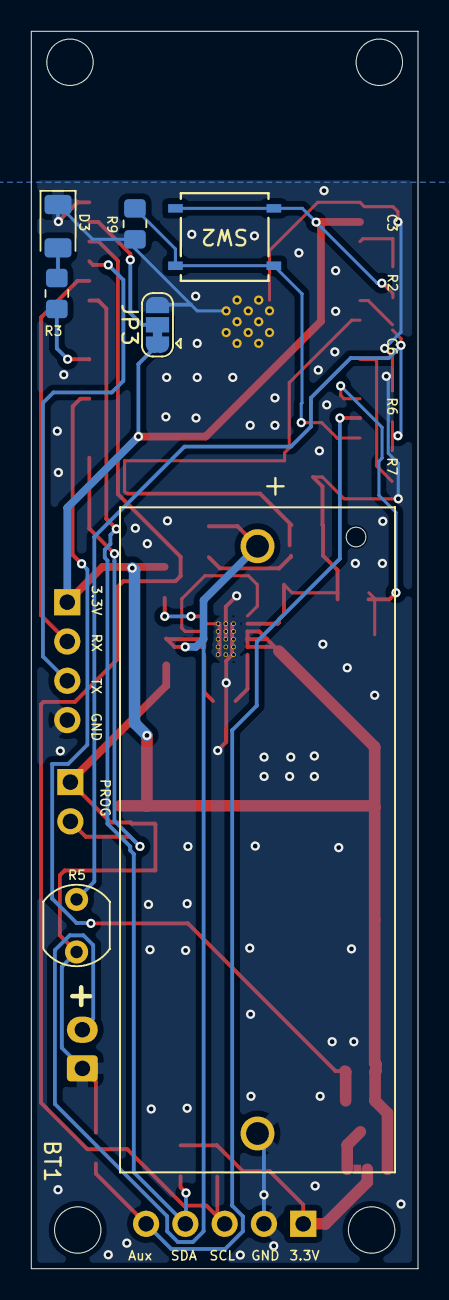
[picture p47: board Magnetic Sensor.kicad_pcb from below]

Board: 2 copper layers, 25.0 x 80.0 mm, 35 parts (7 on the bottom side), 25 nets.

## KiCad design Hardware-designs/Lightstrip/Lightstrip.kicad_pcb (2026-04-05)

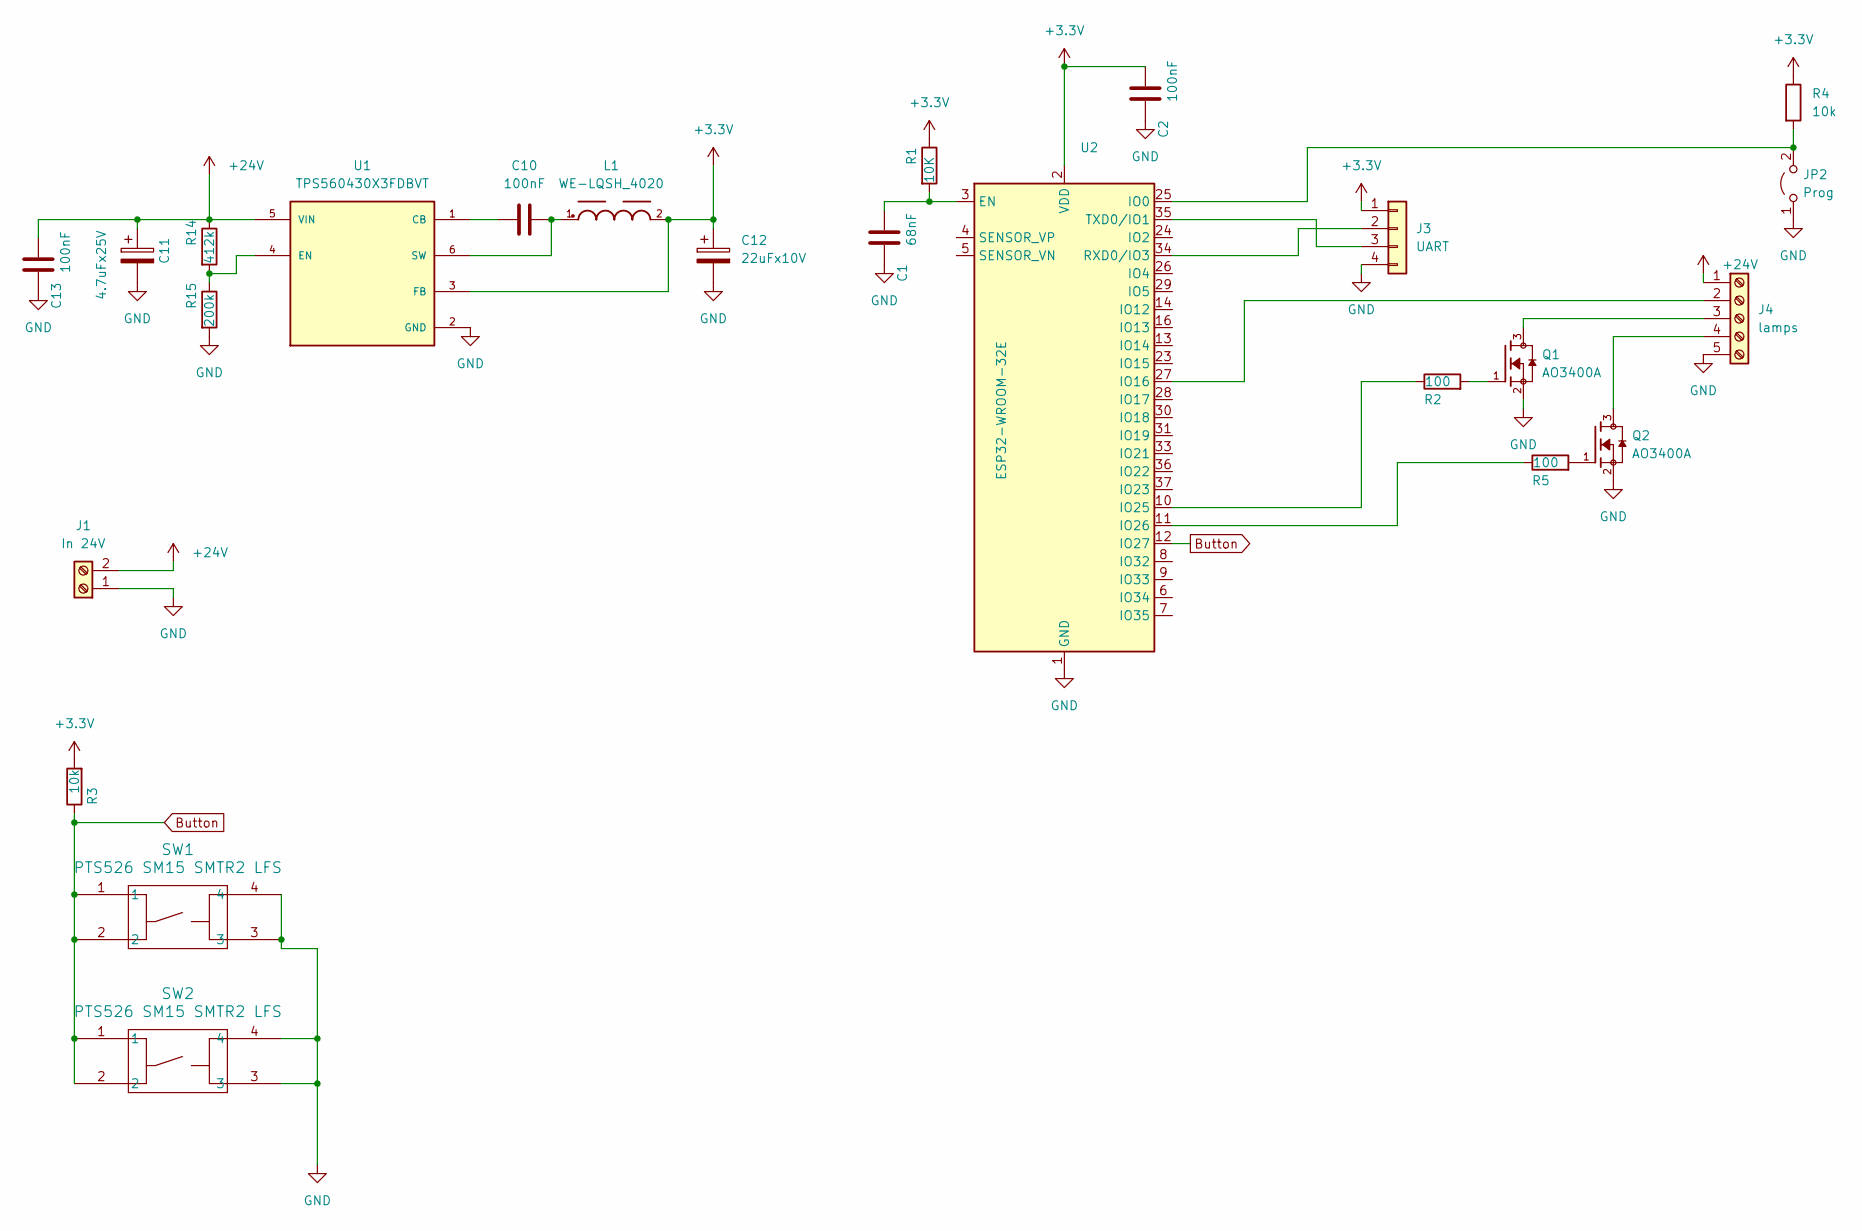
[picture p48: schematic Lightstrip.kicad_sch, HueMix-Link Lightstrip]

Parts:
C1: 68nF; C_0603_1608Metric_Pad1.08x0.95mm_HandSolder
C2, C10, C13: 100nF; C_0603_1608Metric_Pad1.08x0.95mm_HandSolder
C11: 4.7uFx25V; C_1206_3216Metric_Pad1.33x1.80mm_HandSolder
C12: 22uFx10V; C_1206_3216Metric_Pad1.33x1.80mm_HandSolder
J1: In 24V; TerminalBlock_MaiXu_MX126-5.0-02P_1x02_P5.00mm
J3: UART; PinHeader_1x04_P2.54mm_Vertical
J4: lamps; TerminalBlock_MaiXu_MX126-5.0-05P_1x05_P5.00mm
JP2: Prog; PinHeader_1x02_P2.54mm_Vertical
L1: WE-LQSH_4020
Q1, Q2: AO3400A; SOT95P280X125-3N; PARTREV L
R1: 10K; R_1206_3216Metric_Pad1.30x1.75mm_HandSolder
R2, R5: 100; R_1206_3216Metric_Pad1.30x1.75mm_HandSolder
R3, R4: 10k; R_1206_3216Metric_Pad1.30x1.75mm_HandSolder
R14: 412k; R_1206_3216Metric_Pad1.30x1.75mm_HandSolder
R15: 200k; R_1206_3216Metric_Pad1.30x1.75mm_HandSolder
SW1, SW2: PTS526 SM15 SMTR2 LFS; SMT_FS
U1: TPS560430X3FDBVT; IC_TPS560430X3FDBVT; PARTREV B
U2: ESP32-WROOM-32E; ESP32-WROOM-32D

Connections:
+3.3V: C2.2, C12.1, J3.1, L1.2, R1.1, R3.2, R4.1, U1.3 (FB), U2.2 (VDD)
+24V: C11.1, C13.2, J1.2, J4.1, R14.1, U1.5 (VIN)
Button: R3.1, SW1.1, SW1.2, SW2.1, SW2.2, U2.12 (IO27)
GND: C1.1, C2.1, C11.2, C12.2, C13.1, J1.1, J3.4, J4.5, JP2.1 (A), Q1.2, Q2.2, R15.2, SW1.3, SW1.4, SW2.3, SW2.4, U1.2 (GND), U2.1 (GND), U2.15 (GND), U2.38 (GND), U2.39 (GND)
unnamed: J3.2, U2.34 (RXD0/IO3)
unnamed: J3.3, U2.35 (TXD0/IO1)
unnamed: J4.2, U2.27 (IO16)
unnamed: J4.3, Q1.3
unnamed: J4.4, Q2.3
unnamed: JP2.2 (B), R4.2, U2.25 (IO0)
unnamed: Q1.1, R2.2
unnamed: Q2.1, R5.2
unnamed: C10.1, U1.1 (CB)
unnamed: R14.2, R15.1, U1.4 (EN)
unnamed: C10.2, L1.1, U1.6 (SW)
unnamed: C1.2, R1.2, U2.3 (EN)
unnamed: R2.1, U2.10 (IO25)
unnamed: R5.1, U2.11 (IO26)

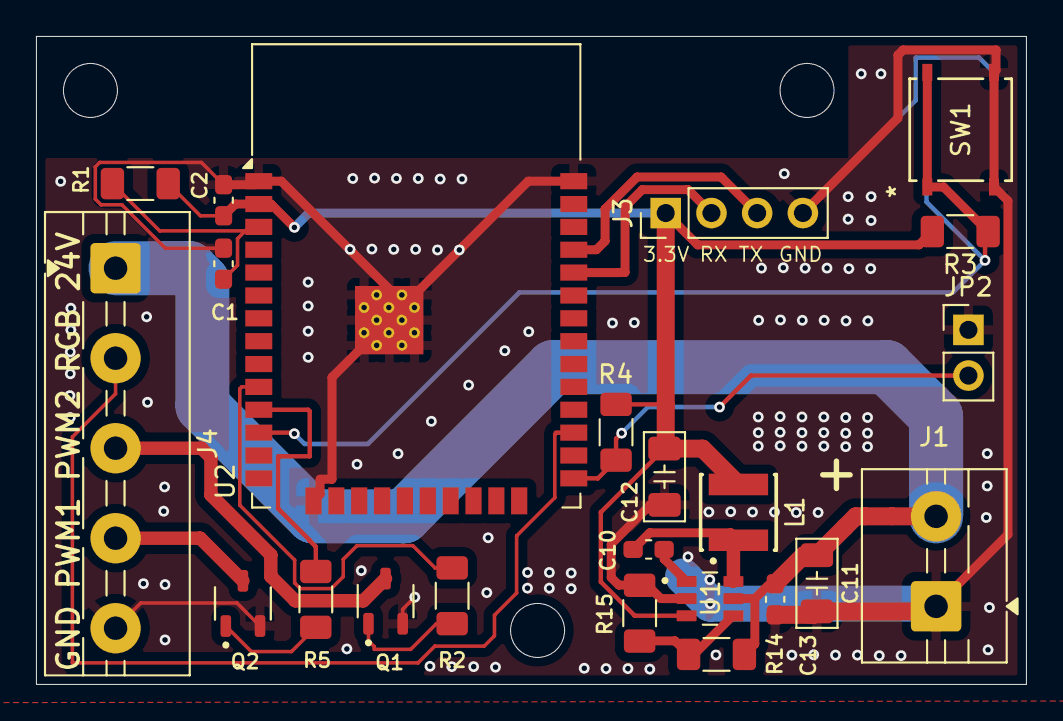
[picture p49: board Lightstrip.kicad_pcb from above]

Board: 2 copper layers, 55.0 x 36.0 mm, 24 parts (1 on the bottom side), 18 nets.

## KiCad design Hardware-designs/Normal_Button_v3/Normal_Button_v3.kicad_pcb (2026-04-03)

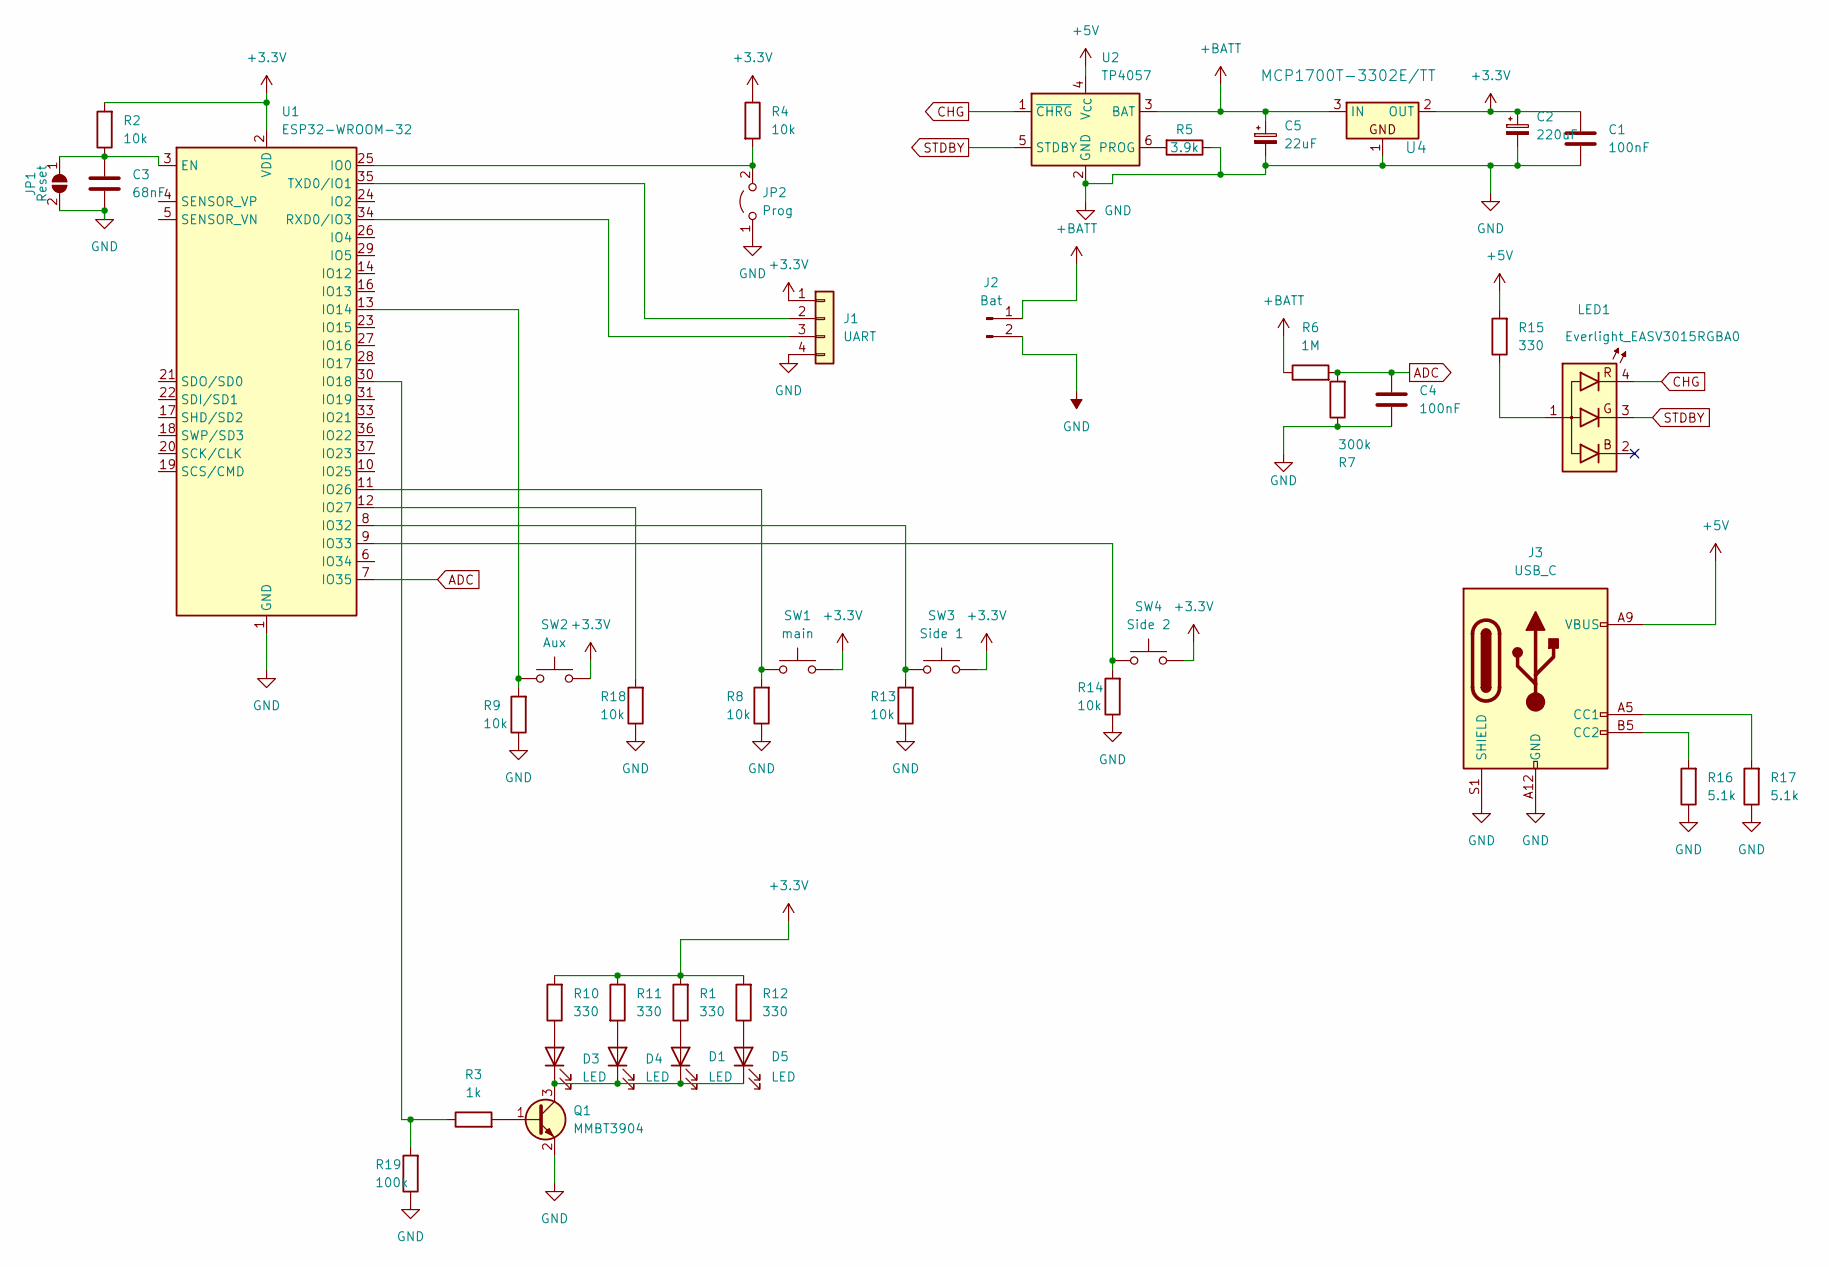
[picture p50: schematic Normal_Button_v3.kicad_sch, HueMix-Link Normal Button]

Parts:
C1, C4: 100nF; C_0805_2012Metric_Pad1.18x1.45mm_HandSolder
C2: 220uF; CP_EIA-6032-15_Kemet-U_HandSolder
C3: 68nF; C_0805_2012Metric_Pad1.18x1.45mm_HandSolder
C5: 22uF; CP_EIA-6032-15_Kemet-U_HandSolder
D1, D3, D4, D5: LED; LED_D3.0mm
J1: UART; PinHeader_1x04_P2.54mm_Vertical
J2: Bat; JST_EH_B2B-EH-A_1x02_P2.50mm_Vertical
J3: USB_C; USB_C_Receptacle_GCT_USB4125-xx-x-0190_6P_TopMnt_Horizontal
JP1: Reset; SolderJumper-2_P1.3mm_Open_Pad1.0x1.5mm
JP2: Prog; PinHeader_1x02_P2.54mm_Vertical
LED1: Everlight_EASV3015RGBA0; LED_D5.0mm-4_RGB
Q1: MMBT3904; SOT-23
R1, R10, R11, R12, R15: 330; R_1206_3216Metric_Pad1.30x1.75mm_HandSolder
R2, R4, R8, R9, R13, R14, R18: 10k; R_1206_3216Metric_Pad1.30x1.75mm_HandSolder
R3: 1k; R_1206_3216Metric_Pad1.30x1.75mm_HandSolder
R5: 3.9k; R_1206_3216Metric_Pad1.30x1.75mm_HandSolder
R6: 1M; R_1206_3216Metric_Pad1.30x1.75mm_HandSolder
R7: 300k; R_1206_3216Metric_Pad1.30x1.75mm_HandSolder
R16, R17: 5.1k; R_1206_3216Metric_Pad1.30x1.75mm_HandSolder
R19: 100k; R_1206_3216Metric_Pad1.30x1.75mm_HandSolder
SW1: main; SW_PUSH-12mm
SW2: Aux; SW_PUSH_6mm
SW3: Side 1; SW_PUSH-12mm
SW4: Side 2; SW_PUSH-12mm
U1: ESP32-WROOM-32; ESP32-WROOM-32E
U2: TP4057; TSOT-23-6_HandSoldering
U4: MCP1700T-3302E/TT; SOT-23

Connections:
+3.3V: C1.1, C2.1, J1.1, R1.2, R2.2, R4.1, R10.2, R11.1, R12.2, SW1.2, SW2.2, SW3.2, SW4.2, U1.2 (VDD), U4.2 (OUT)
+5V: J3.A9 (VBUS), J3.B9 (VBUS), R15.2, U2.4 (V_{CC})
+BATT: C5.1, J2.1, R6.1, U2.3 (BAT), U4.3 (IN)
ADC: C4.1, R6.2, R7.2, U1.7 (IO35)
CHG: LED1.4 (R), U2.1 (~CHRG)
GND: C1.2, C2.2, C3.2, C4.2, C5.2, J1.4, J2.2, J3.A12 (GND), J3.B12 (GND), J3.S1 (SHIELD), JP1.2 (B), JP2.1 (A), Q1.2 (E), R5.1, R7.1, R8.1, R9.1, R13.1, R14.1, R16.1, R17.1, R18.1, R19.1, U1.1 (GND), U1.15 (GND), U1.38 (GND), U1.39 (GND), U2.2 (GND), U4.1
unnamed: D1.2 (A), R1.1
unnamed: D1.1 (K), D3.1 (K), D4.1 (K), D5.1 (K), Q1.3 (C)
unnamed: D3.2 (A), R10.1
unnamed: D4.2 (A), R11.2
unnamed: D5.2 (A), R12.1
unnamed: J1.2, U1.35 (TXD0/IO1)
unnamed: J1.3, U1.34 (RXD0/IO3)
unnamed: J3.A5 (CC1), R17.2
unnamed: J3.B5 (CC2), R16.2
unnamed: C3.1, JP1.1 (A), R2.1, U1.3 (EN)
unnamed: JP2.2 (B), R4.2, U1.25 (IO0)
unnamed: LED1.1 (A), R15.1
unnamed: Q1.1 (B), R3.2
unnamed: R9.2, SW2.1, U1.13 (IO14)
unnamed: R3.1, R19.2, U1.30 (IO18)
unnamed: R8.2, SW1.1, U1.11 (IO26)
unnamed: R18.2, U1.12 (IO27)
unnamed: R13.2, SW3.1, U1.8 (IO32)
unnamed: R14.2, SW4.1, U1.9 (IO33)
unnamed: R5.2, U2.6 (PROG)
STDBY: LED1.3 (G), U2.5 (STDBY)

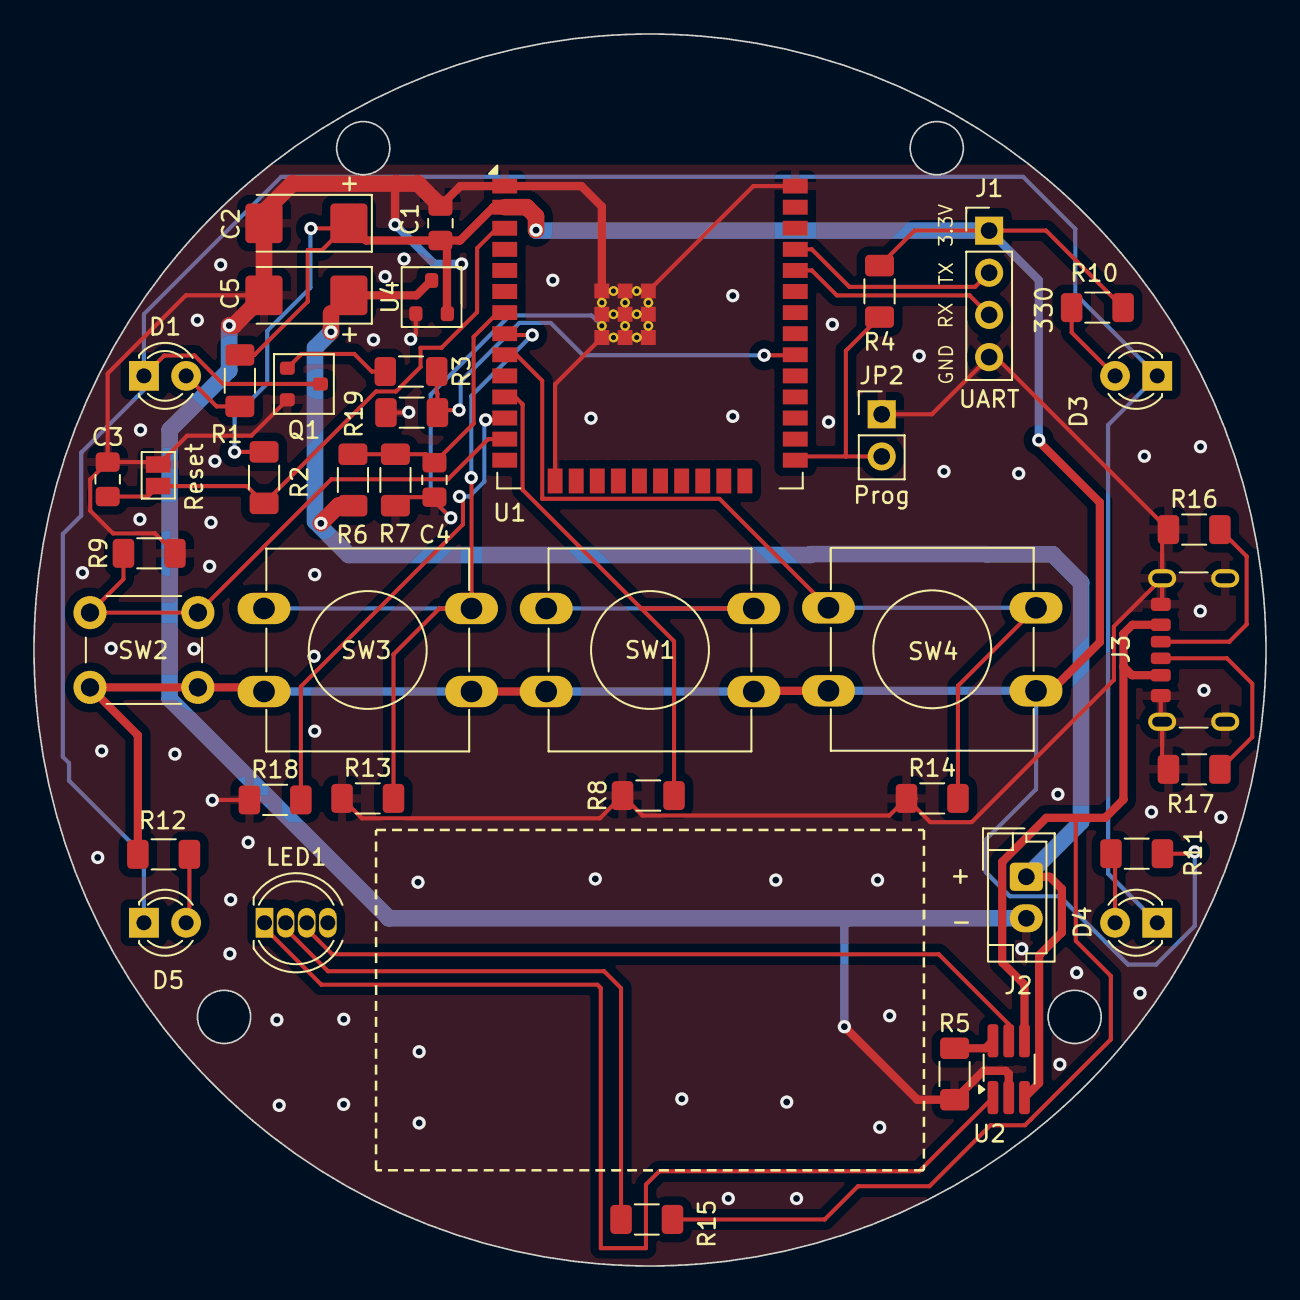
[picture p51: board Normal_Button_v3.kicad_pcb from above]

Board: 2 copper layers, 74.2 x 74.2 mm, 42 parts (0 on the bottom side), 27 nets.

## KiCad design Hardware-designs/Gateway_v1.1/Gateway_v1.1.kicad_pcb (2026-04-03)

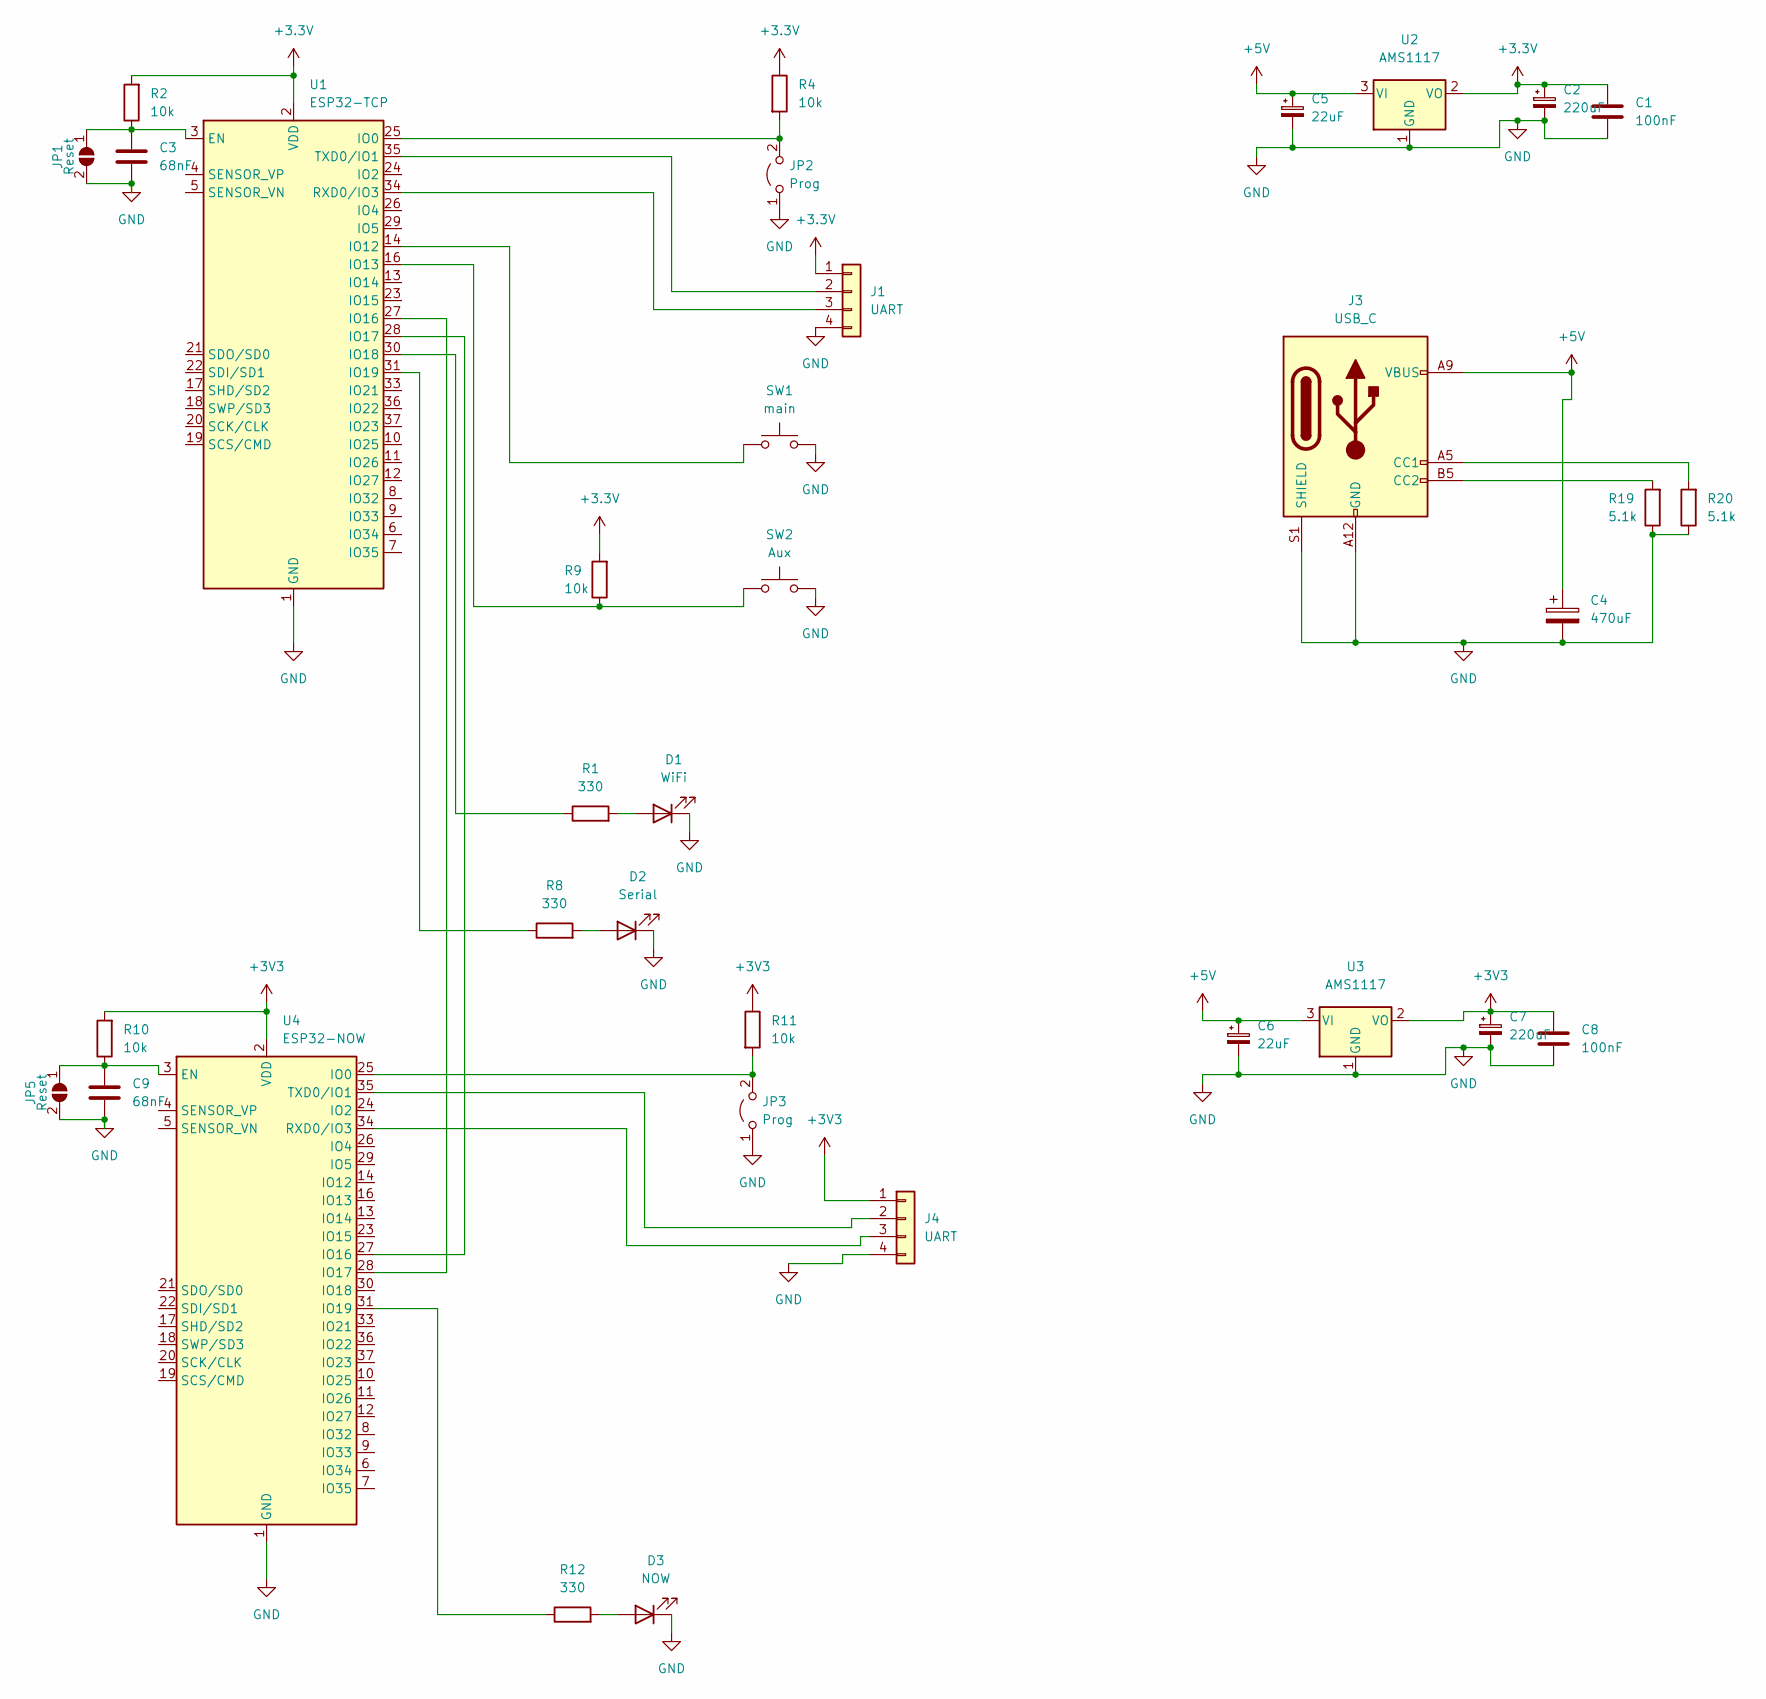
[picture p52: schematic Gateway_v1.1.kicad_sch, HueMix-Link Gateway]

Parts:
C1, C8: 100nF; C_0805_2012Metric_Pad1.18x1.45mm_HandSolder
C2, C7: 220uF; CP_EIA-6032-15_Kemet-U_HandSolder
C3, C9: 68nF; C_0805_2012Metric_Pad1.18x1.45mm_HandSolder
C4: 470uF; CP_Radial_D8.0mm_P3.50mm
C5, C6: 22uF; CP_EIA-6032-15_Kemet-U_HandSolder
D1: WiFi; LED_D3.0mm
D2: Serial; LED_D3.0mm
D3: NOW; LED_D3.0mm
J1, J4: UART; PinHeader_1x04_P2.54mm_Vertical
J3: USB_C; USB_C_Receptacle_GCT_USB4125-xx-x-0190_6P_TopMnt_Horizontal
JP1, JP5: Reset; SolderJumper-2_P1.3mm_Open_Pad1.0x1.5mm
JP2, JP3: Prog; PinHeader_1x02_P2.54mm_Vertical
R1, R8, R12: 330; R_1206_3216Metric_Pad1.30x1.75mm_HandSolder
R2, R4, R9, R10, R11: 10k; R_1206_3216Metric_Pad1.30x1.75mm_HandSolder
R19, R20: 5.1k; R_1206_3216Metric_Pad1.30x1.75mm_HandSolder
SW1: main; SW_PUSH-12mm
SW2: Aux; SW_PUSH_6mm
U1: ESP32-TCP; ESP32-WROOM-32
U2, U3: AMS1117; SOT-223-3_TabPin2
U4: ESP32-NOW; ESP32-WROOM-32

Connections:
+3.3V: C1.1, C2.1, J1.1, R2.2, R4.1, R9.2, U1.2 (VDD), U2.2 (VO)
+3V3: C7.1, C8.1, J4.1, R10.2, R11.1, U3.2 (VO), U4.2 (VDD)
+5V: C4.1, C5.1, C6.1, J3.A9 (VBUS), J3.B9 (VBUS), U2.3 (VI), U3.3 (VI)
GND: C1.2, C2.2, C3.2, C4.2, C5.2, C6.2, C7.2, C8.2, C9.2, D1.1 (K), D2.1 (K), D3.1 (K), J1.4, J3.A12 (GND), J3.B12 (GND), J3.S1 (SHIELD), J4.4, JP1.2 (B), JP2.1 (A), JP3.1 (A), JP5.2 (B), R19.1, R20.1, SW1.2, SW2.2, U1.1 (GND), U1.15 (GND), U1.38 (GND), U1.39 (GND), U2.1 (GND), U3.1 (GND), U4.1 (GND), U4.15 (GND), U4.38 (GND), U4.39 (GND)
unnamed: D1.2 (A), R1.2
unnamed: D2.2 (A), R8.2
unnamed: D3.2 (A), R12.2
unnamed: J1.2, U1.35 (TXD0/IO1)
unnamed: J1.3, U1.34 (RXD0/IO3)
unnamed: J3.A5 (CC1), R20.2
unnamed: J3.B5 (CC2), R19.2
unnamed: J4.2, U4.35 (TXD0/IO1)
unnamed: J4.3, U4.34 (RXD0/IO3)
unnamed: C3.1, JP1.1 (A), R2.1, U1.3 (EN)
unnamed: JP2.2 (B), R4.2, U1.25 (IO0)
unnamed: JP3.2 (B), R11.2, U4.25 (IO0)
unnamed: C9.1, JP5.1 (A), R10.1, U4.3 (EN)
unnamed: SW1.1, U1.14 (IO12)
unnamed: R9.1, SW2.1, U1.16 (IO13)
unnamed: U1.27 (IO16), U4.28 (IO17)
unnamed: U1.28 (IO17), U4.27 (IO16)
unnamed: R1.1, U1.30 (IO18)
unnamed: R8.1, U1.31 (IO19)
unnamed: R12.1, U4.31 (IO19)

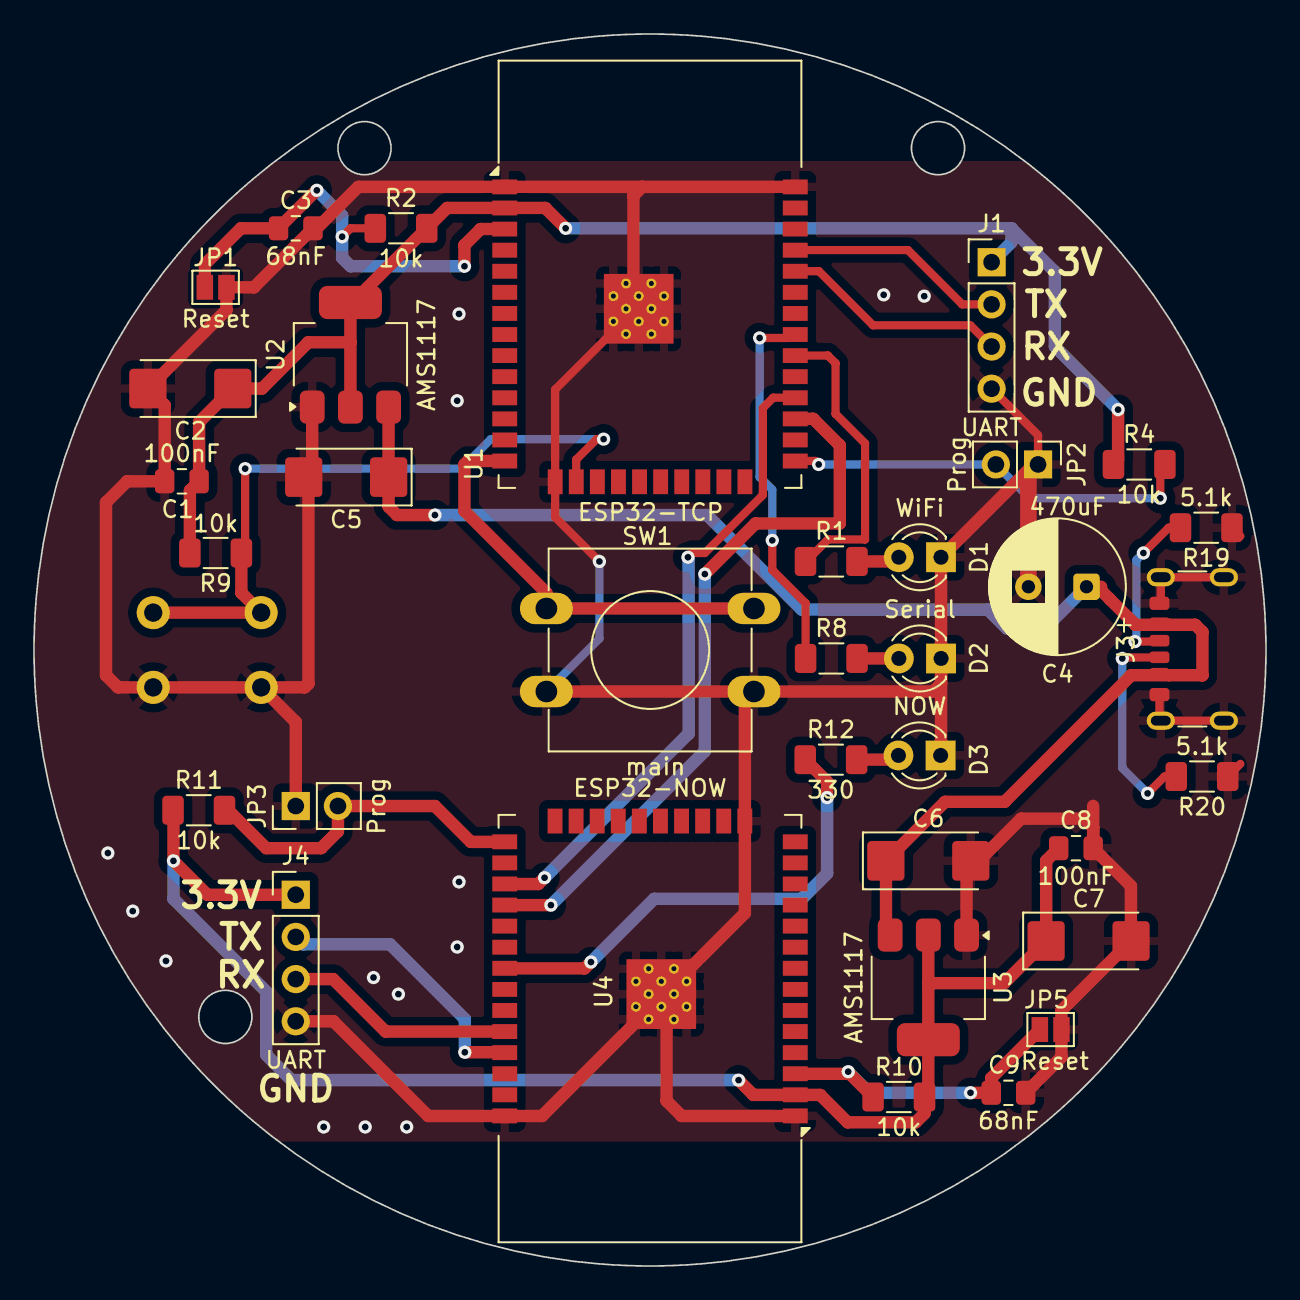
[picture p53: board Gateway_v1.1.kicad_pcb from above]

Board: 2 copper layers, 74.2 x 74.2 mm, 35 parts (1 on the bottom side), 24 nets.

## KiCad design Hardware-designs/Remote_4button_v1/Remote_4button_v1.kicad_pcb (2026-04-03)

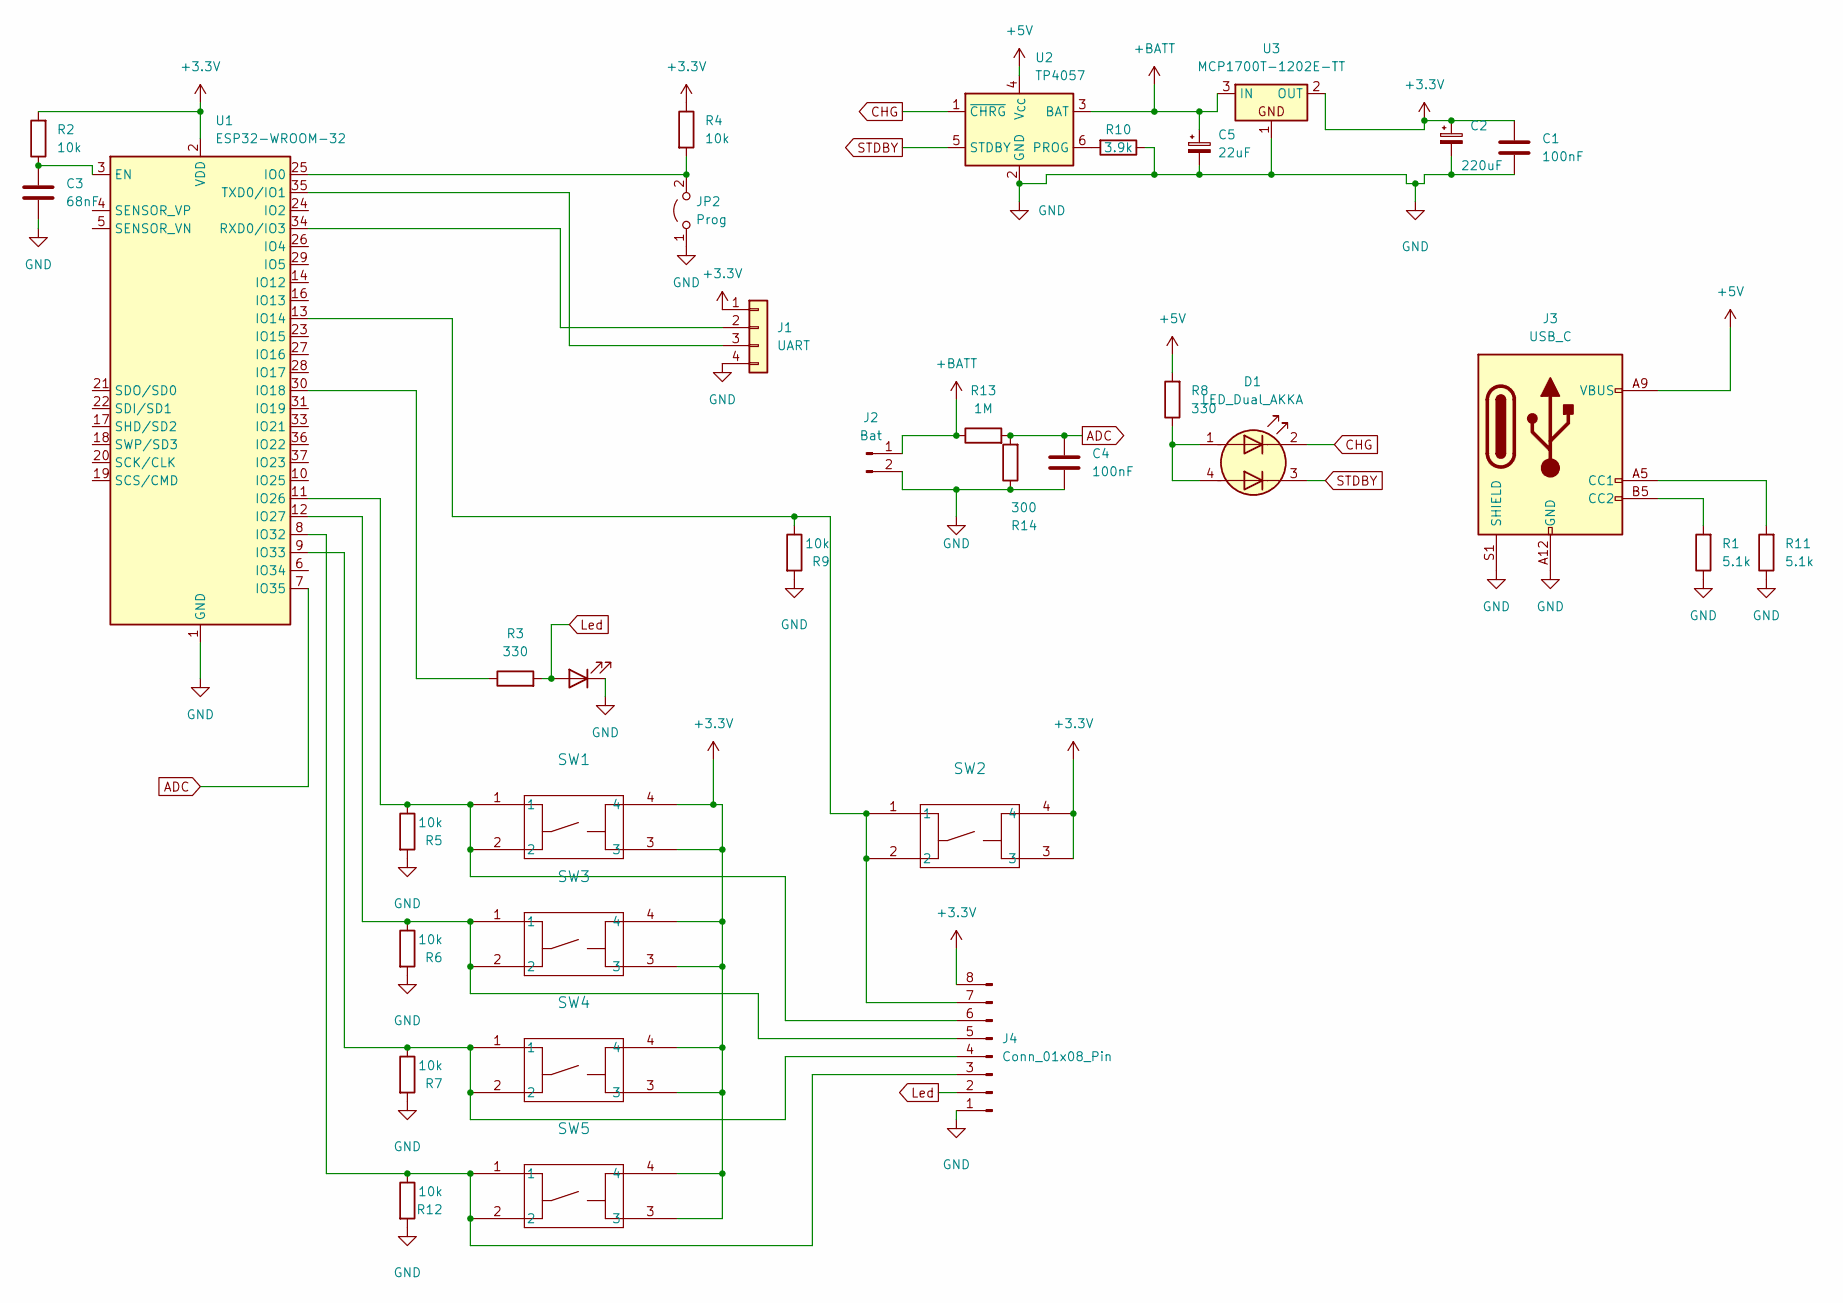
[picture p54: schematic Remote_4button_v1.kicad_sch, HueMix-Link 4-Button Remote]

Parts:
C1, C4: 100nF; C_0805_2012Metric_Pad1.18x1.45mm_HandSolder
C2: 220uF; CP_EIA-6032-15_Kemet-U_HandSolder
C3: 68nF; C_0805_2012Metric_Pad1.18x1.45mm_HandSolder
C5: 22uF; CP_EIA-6032-15_Kemet-U_HandSolder
D1: LED_Dual_AKKA; APHBM2012ETSGTC
D3: LED; LED_1206_3216Metric
J1: UART; PinHeader_1x04_P2.54mm_Vertical
J2: Bat; TestPoint_2Pads_Pitch2.54mm_Drill0.8mm
J3: USB_C; USB_C_Receptacle_GCT_USB4125-xx-x-0190_6P_TopMnt_Horizontal
J4: Conn_01x08_Pin; PinHeader_1x08_P2.54mm_Vertical
JP2: Prog; PinHeader_1x02_P2.54mm_Vertical
R1, R11: 5.1k; R_0603_1608Metric_Pad0.98x0.95mm_HandSolder
R2, R4, R5, R6, R7, R9, R12: 10k; R_0603_1608Metric_Pad0.98x0.95mm_HandSolder
R3, R8: 330; R_0603_1608Metric_Pad0.98x0.95mm_HandSolder
R10: 3.9k; R_0603_1608Metric_Pad0.98x0.95mm_HandSolder
R13: 1M; R_0603_1608Metric_Pad0.98x0.95mm_HandSolder
R14: 300; R_0603_1608Metric_Pad0.98x0.95mm_HandSolder
SW1, SW2, SW3, SW4, SW5: PTS526 SM15 SMTR2 LFS; SMT_FS
U1: ESP32-WROOM-32; ESP32-WROOM-32D
U2: TP4057; TSOT-23-6_HandSoldering
U3: MCP1700T-1202E-TT; SOT-23

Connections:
+3.3V: C1.1, C2.1, J1.1, J4.8, R2.2, R4.1, SW1.3, SW1.4, SW2.3, SW2.4, SW3.3, SW3.4, SW4.3, SW4.4, SW5.3, SW5.4, U1.2 (VDD), U3.2 (OUT)
+5V: J3.A9 (VBUS), J3.B9 (VBUS), R8.2, U2.4 (V_{CC})
+BATT: C5.1, J2.1, R13.1, U2.3 (BAT), U3.3 (IN)
ADC: C4.1, R13.2, R14.2, U1.7 (IO35)
CHG: D1.2 (K1), U2.1 (~CHRG)
GND: C1.2, C2.2, C3.2, C4.2, C5.2, D3.1 (K), J1.4, J2.2, J3.A12 (GND), J3.B12 (GND), J3.S1 (SHIELD), J4.1, JP2.1 (A), R1.1, R5.2, R6.2, R7.2, R9.2, R10.1, R11.1, R12.2, R14.1, U1.1 (GND), U1.15 (GND), U1.38 (GND), U1.39 (GND), U2.2 (GND), U3.1
Led: D3.2 (A), J4.2, R3.2
unnamed: D1.1 (A1), D1.4 (A2), R8.1
unnamed: J1.2, U1.34 (RXD0/IO3)
unnamed: J1.3, U1.35 (TXD0/IO1)
unnamed: J3.A5 (CC1), R11.2
unnamed: J3.B5 (CC2), R1.2
unnamed: J4.3, R12.1, SW5.1, SW5.2, U1.8 (IO32)
unnamed: J4.4, R7.1, SW4.1, SW4.2, U1.9 (IO33)
unnamed: J4.5, R6.1, SW3.1, SW3.2, U1.12 (IO27)
unnamed: J4.6, R5.1, SW1.1, SW1.2, U1.11 (IO26)
unnamed: J4.7, R9.1, SW2.1, SW2.2, U1.13 (IO14)
unnamed: JP2.2 (B), R4.2, U1.25 (IO0)
unnamed: C3.1, R2.1, U1.3 (EN)
unnamed: R3.1, U1.30 (IO18)
unnamed: R10.2, U2.6 (PROG)
STDBY: D1.3 (K2), U2.5 (STDBY)

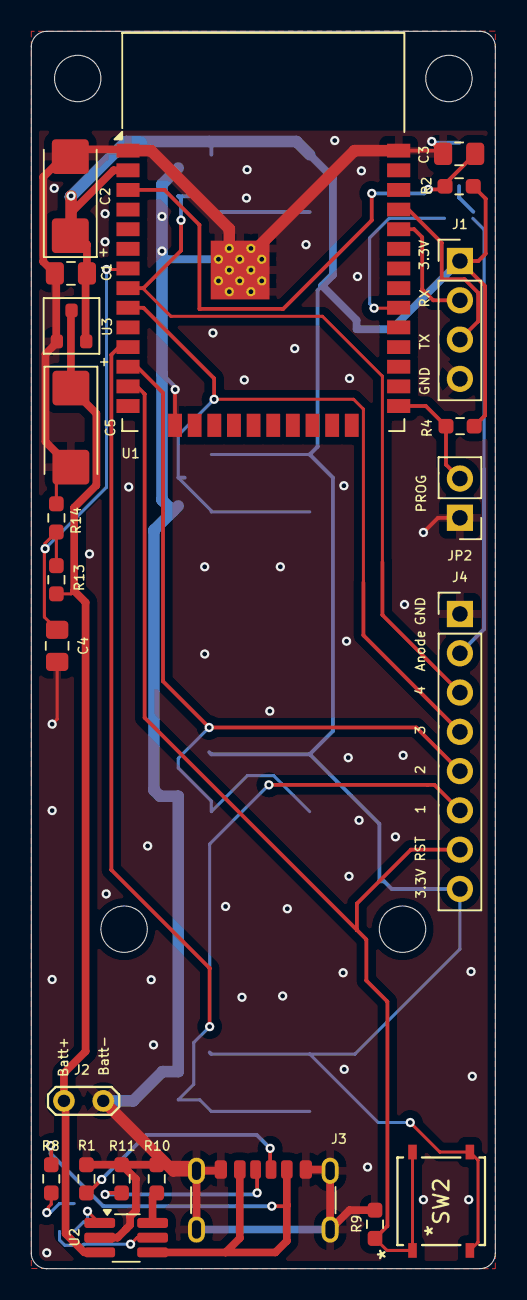
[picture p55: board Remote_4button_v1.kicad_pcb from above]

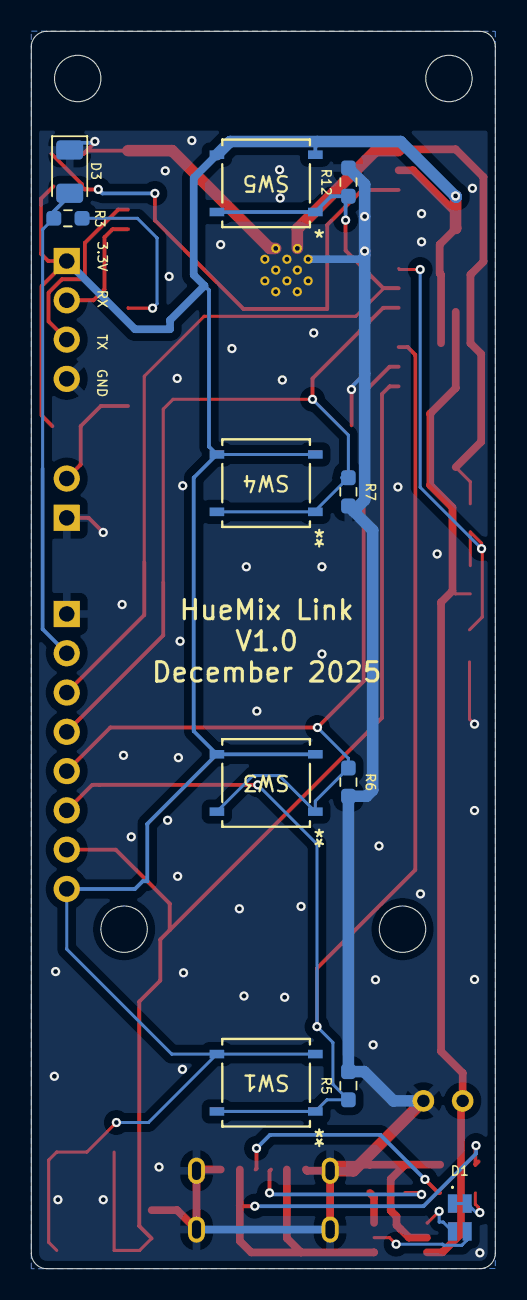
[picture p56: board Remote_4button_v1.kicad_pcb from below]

Board: 2 copper layers, 30.0 x 80.0 mm, 34 parts (11 on the bottom side), 22 nets.

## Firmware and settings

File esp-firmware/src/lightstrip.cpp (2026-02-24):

/* 
  HUEMIXLINK V3 - LIGHT STRIP FIRMWARE
  Supports: ESP32 & ESP8266
*/

#include "HueMixLink.h"
#include <Preferences.h>
#include <FastLED.h>
#include <Ticker.h>

// --- CONFIGURATION ---
#define MAX_LEDS    60

// --- MODEL ID ---
// Each firmware variant has a unique model ID for identification
// ODD numbers = ESP32, EVEN numbers = ESP8266
// Pairs represent the same type across platforms:
// Model 1 (ESP32) & 2 (ESP8266): RGB, GRB, WS2812B
// Model 3 (ESP32) & 4 (ESP8266): RGBW, GRB, SK6812
// Model 5 (ESP32) & 6 (ESP8266): RGB (WS2812B) + Global Warm White PWM
#ifndef LIGHTSTRIP_MODEL
  #error "LIGHTSTRIP_MODEL not defined"
#endif
  // Models 1 & 2: Standard RGB
#if LIGHTSTRIP_MODEL == 1 || LIGHTSTRIP_MODEL == 2
  #define IS_RGBW  false
  #define COLOR_ORDER GRB
  #define LED_TYPE WS2812B
#elif LIGHTSTRIP_MODEL == 3 || LIGHTSTRIP_MODEL == 4
  // Models 3 & 4: RGBW Strip
  #define IS_RGBW  true
  #define LED_TYPE SK6812
  #define COLOR_ORDER GRB 
#elif LIGHTSTRIP_MODEL == 5 || LIGHTSTRIP_MODEL == 6
  // Models 5 & 6: RGB + Global Warm White PWM
  #define IS_RGBW  false
  #define HAS_WARMWHITE_PWM true
  #define COLOR_ORDER RGB
  #define LED_TYPE WS2812B
  // Warm white color profile (3000K)
  #define WW_R 255
  #define WW_G 180
  #define WW_B 107
#else
  #error "Unknown LIGHTSTRIP_MODEL"
#endif

// --- PLATFORM SETUP ---
#if defined(ESP8266)
  #include <ESP8266WiFi.h>
  #include <espnow.h>
  #include <Updater.h>
  #include <bearssl/bearssl_hash.h>
  #define LED_PIN     D2
  #define PIN_RESET   D1
  #define ONBOARD_LED D4
  #if LIGHTSTRIP_MODEL == 6
    #define WHITE_LED_PIN  D3
  #endif
#else
  #include <WiFi.h>
  #include <esp_now.h>
  #include <esp_wifi.h>
  #include <esp_ota_ops.h>
  #include <esp_partition.h>
  #include "mbedtls/sha256.h"
  #define LED_PIN     16  
  #define PIN_RESET   27
  #define ONBOARD_LED 2
  #if LIGHTSTRIP_MODEL == 5
    #define WHITE_LED_PIN  26
  #endif
#endif

// --- GLOBALS ---
Preferences prefs;
uint32_t HOME_ID = 0; 
uint16_t numLeds = MAX_LEDS;
Payload_GatewayList gateways;
uint8_t broadcastAddress[] = {0xFF, 0xFF, 0xFF, 0xFF, 0xFF, 0xFF};
int lastSuccessfulGatewayIndex = -1;

// --- OTA LED BREATHING (using onboard LED) ---
#define LED_PWM_FREQ 500
#define LED_PWM_RESOLUTION 8
Ticker breathingTicker;
int breathingDirection = 1;
int breathingBrightness = 0;
bool breathingActive = false;
volatile bool breathingUpdatePending = false;  // Flag for interrupt-safe LED update

#define CMD_SET_LED_COUNT 0x50
#define CMD_FACTORY_RESET 0xFF

const uint8_t gamma8[] = {
    0,  0,  0,  0,  0,  0,  0,  0,  0,  0,  0,  0,  0,  0,  0,  0,
    0,  0,  0,  0,  0,  0,  0,  0,  0,  0,  0,  0,  1,  1,  1,  1,
    1,  1,  1,  1,  1,  1,  1,  1,  1,  2,  2,  2,  2,  2,  2,  2,
    2,  3,  3,  3,  3,  3,  3,  3,  4,  4,  4,  4,  4,  5,  5,  5,
    5,  6,  6,  6,  6,  7,  7,  7,  7,  8,  8,  8,  9,  9,  9, 10,
   10, 10, 11, 11, 11, 12, 12, 13, 13, 13, 14, 14, 15, 15, 16, 16,
   17, 17, 18, 18, 19, 19, 20, 20, 21, 21, 22, 22, 23, 24, 24, 25,
   25, 26, 27, 27, 28, 29, 29, 30, 31, 32, 32, 33, 34, 35, 35, 36,
   37, 38, 39, 39, 40, 41, 42, 43, 44, 45, 46, 47, 48, 49, 50, 50,
   51, 52, 54, 55, 56, 57, 58, 59, 60, 61, 62, 63, 64, 66, 67, 68,
   69, 70, 72, 73, 74, 75, 77, 78, 79, 81, 82, 83, 85, 86, 87, 89,
   90, 92, 93, 95, 96, 98, 99,101,102,104,105,107,109,110,112,114,
  115,117,119,120,122,124,126,127,129,131,133,135,137,138,140,142,
  144,146,148,150,152,154,156,158,160,162,164,167,169,171,173,175,
  177,180,182,184,186,189,191,193,196,198,200,203,205,208,210,213,
  215,218,220,223,225,228,231,233,236,239,241,244,247,249,252,255 
};

struct CRGBW {
  union {
    struct {
      uint8_t g;
      uint8_t r;
      uint8_t b;
      uint8_t w;
    };
    uint8_t raw[4];
  };

  CRGBW(){}
  CRGBW(uint8_t _r, uint8_t _g, uint8_t _b, uint8_t _w) {
    r = _r; g = _g; b = _b; w = _w;
  }
  
  // Quick assign from CRGB
  inline void operator = (const CRGB& c) {
    r = c.r; g = c.g; b = c.b; w = 0;
  }
};


#if IS_RGBW
CRGBW leds[MAX_LEDS];
CRGB *ledsAsRGB = (CRGB*)leds;
#else
CRGB leds[MAX_LEDS];
#endif

bool isPaired = false;
unsigned long lastPairRequest = 0;
volatile bool deliveryComplete = false;
volatile bool deliverySuccess = false;

CRGBW rgbToRgbw(const CRGB &rgb) {
  // 1. Get the maximum brightness of the requested color
  uint8_t maxVal = max(rgb.r, max(rgb.g, rgb.b));
  
  // 2. If it's black, return black immediately
  if (maxVal == 0) return CRGBW(0,0,0,0);

  // 3. Calculate Saturation (0 = White, 255 = Fully Colorful)
  // We use FastLED's built-in saturation math logic here
  uint8_t minVal = min(rgb.r, min(rgb.g, rgb.b));
  uint8_t saturation = 255 - ((minVal * 255) / maxVal);

  // 4. LOGIC: 
  // If Saturation is High (> 200), keep White LED OFF (Pure Color).
  // If Saturation is Low, mix in the White LED.
  
  if (saturation >= 200) {
      // Deep rich color: Don't use the White channel at all.
      return CRGBW(rgb.r, rgb.g, rgb.b, 0); 
  } 
  else {
      // Pastel or White: Move the "common" part to the White LED
      // But scale it down slightly (0.8) because W LEDs are usually overpowering
      uint8_t whiteAmt = (uint8_t)(minVal * 0.8); 
      return CRGBW(rgb.r - whiteAmt, rgb.g - whiteAmt, rgb.b - whiteAmt, whiteAmt);
  }
}

#ifdef HAS_WARMWHITE_PWM
// --- WARM WHITE PWM CONTROL (Models 5 & 6) ---
void setWhitePWM(uint8_t val) {
  #ifdef ESP32
    // Use LEDC PWM on ESP32
    static bool pwmConfigured = false;
    if (!pwmConfigured) {
      ledcAttach(WHITE_LED_PIN, LED_PWM_FREQ, LED_PWM_RESOLUTION);
      pwmConfigured = true;
    }
    ledcWrite(WHITE_LED_PIN, val);
  #else
    // Use analogWrite on ESP8266
    analogWrite(WHITE_LED_PIN, val);
  #endif
}

// --- WARM WHITE EXTRACTION ALGORITHM (Models 5 & 6) ---
// Calculates how much warm white component is shared across all pixels
// Returns the warm white level (0-255)
uint8_t extractWarmWhite(CRGB* pixelData, uint8_t count) {
  if (count == 0) return 0;
  
  // Find the maximum amount of warm white that ALL pixels contain
  uint8_t maxSharedWW = 255;
  
  for(int i = 0; i < count; i++) {
    uint8_t r = pixelData[i].r;
    uint8_t g = pixelData[i].g;
    uint8_t b = pixelData[i].b;
    
    // Calculate how much warm white fits in this pixel
    // by finding the limiting factor (bottleneck)
    uint16_t ww_from_r = ((uint16_t)r * 255) / WW_R;
    uint16_t ww_from_g = ((uint16_t)g * 255) / WW_G;
    uint16_t ww_from_b = ((uint16_t)b * 255) / WW_B;
    
    // The minimum determines how much warm white this pixel can contribute
    uint8_t pixel_ww = min(ww_from_r, min(ww_from_g, ww_from_b));
    
    // Track the minimum across all pixels (shared amount)
    if (pixel_ww < maxSharedWW) {
      maxSharedWW = pixel_ww;
    }
  }
  
  // Now subtract the warm white contribution from each pixel
  uint16_t ww_r = ((uint16_t)maxSharedWW * WW_R) / 255;
  uint16_t ww_g = ((uint16_t)maxSharedWW * WW_G) / 255;
  uint16_t ww_b = ((uint16_t)maxSharedWW * WW_B) / 255;
  for(int i = 0; i < count; i++) {
    pixelData[i].r = (pixelData[i].r > ww_r) ? (pixelData[i].r - ww_r) : 0;
    pixelData[i].g = (pixelData[i].g > ww_g) ? (pixelData[i].g - ww_g) : 0;
    pixelData[i].b = (pixelData[i].b > ww_b) ? (pixelData[i].b - ww_b) : 0;
  }
  
  return maxSharedWW;
}
#endif

// --- OTA STATE MACHINE ---
enum OtaState { OTA_IDLE, OTA_RECEIVING, OTA_VALIDATING, OTA_COMPLETE };
OtaState otaState = OTA_IDLE;
#if defined(ESP32)
  const esp_partition_t *update_partition = nullptr;
  esp_ota_handle_t update_handle = 0;
  mbedtls_sha256_context sha256_ctx;
#else
  br_sha256_context sha256_ctx;
#endif
uint32_t expected_firmware_size = 0;
uint32_t received_bytes = 0;
uint16_t expected_chunk_index = 0;
uint8_t expected_sha256[32];
unsigned long last_ota_activity = 0;

// Packet queue for ESP8266 interrupt-safe processing
#ifdef ESP8266
  #define PACKET_QUEUE_SIZE 10
  struct PacketQueueItem {
    HueMixLinkPacket packet;
    uint8_t mac[6];
    bool valid;
  };
  PacketQueueItem packetQueue[PACKET_QUEUE_SIZE];
  volatile uint8_t packetQueueHead = 0;
  volatile uint8_t packetQueueTail = 0;
#endif

// --- OTA LED INDICATOR (PWM breathing on onboard LED) ---
void updateBreathing() {
  breathingBrightness += breathingDirection * 10;
  if (breathingBrightness >= 255) {
    breathingBrightness = 255;
    breathingDirection = -1;
  } else if (breathingBrightness <= 0) {
    breathingBrightness = 0;
    breathingDirection = 1;
  }
  
  // Set flag to update LED in main loop (interrupt-safe for ESP8266)
  breathingUpdatePending = true;
}

void applyBreathingLed() {
  // This function is called from main loop, not interrupt
  if (!breathingActive || !breathingUpdatePending) return;
  breathingUpdatePending = false;
  
  #ifdef ESP32
    ledcWrite(ONBOARD_LED, breathingBrightness);
  #else
    // ESP8266: analogWrite is safe from main loop
    analogWrite(ONBOARD_LED, breathingBrightness);
  #endif
}

void startLedBreathing() {
  #ifdef ESP32
    ledcAttach(ONBOARD_LED, LED_PWM_FREQ, LED_PWM_RESOLUTION);
  #else
    // ESP8266: Set PWM frequency and range
    analogWriteFreq(LED_PWM_FREQ);
    analogWriteRange(255);
    pinMode(ONBOARD_LED, OUTPUT);
  #endif
  breathingBrightness = 0;
  breathingDirection = 1;
  breathingTicker.attach_ms(30, updateBreathing);
  breathingActive = true;
}

void stopLedBreathing() {
  if (!breathingActive) return;
  breathingTicker.detach();
  #ifdef ESP32
    ledcDetach(ONBOARD_LED);
  #endif
  pinMode(ONBOARD_LED, OUTPUT);
  digitalWrite(ONBOARD_LED, LOW);
  breathingActive = false;
}

// --- LED FEEDBACK ---
void showStatusColor(CRGB color) {
  #ifdef HAS_WARMWHITE_PWM
    setWhitePWM(0);  // Turn off white for status colors
  #endif
  for(int i=0; i<numLeds; i++) leds[i] = color;
  FastLED.show();
}

void flashStatus(CRGB color, int times) {
  for(int i=0; i<times; i++) {
    showStatusColor(color); delay(100);
    showStatusColor(CRGB::Black); delay(100);
  }
}

void saveGateways() { 
  prefs.putBytes("gw", &gateways, sizeof(gateways)); 
  Serial.printf("Saved %d gateways\n", gateways.count);
}

void addGateway(const uint8_t *mac) {
  for(int i=0; i<gateways.count; i++) {
    if (memcmp(gateways.macs[i], mac, 6) == 0) return; 
  }
  if (gateways.count < MAX_GATEWAYS) {
    memcpy(gateways.macs[gateways.count], mac, 6);
    gateways.count++;
    saveGateways();
    Serial.println("New Gateway Added");
  }
}


// --- FORWARD DECLARATIONS ---
void sendHello();
void abortOta(const char* reason);
void handleOtaNotify(HueMixLinkPacket* pkt);
void handleOtaChunk(HueMixLinkPacket* pkt);
void handleOtaCheckpointReq(HueMixLinkPacket* pkt);
void handleOtaComplete(HueMixLinkPacket* pkt);
void handleOtaAbort(HueMixLinkPacket* pkt);

#if defined(ESP8266)
void OnDataSent(uint8_t *mac_addr, uint8_t status) {
  deliverySuccess = (status == 0); // 0 means success on ESP8266
  deliveryComplete = true;
}
#else
void OnDataSent(const uint8_t *mac_addr, esp_now_send_status_t status) {
  deliverySuccess = (status == ESP_NOW_SEND_SUCCESS);
  deliveryComplete = true;
}
#endif

// --- OTA FUNCTIONS ---
void abortOta(const char* reason) {
  Serial.printf("[OTA] ABORT: %s\n", reason);
  stopLedBreathing();
  #if defined(ESP32)
    if (update_handle) {
      esp_ota_abort(update_handle);
      update_handle = 0;
    }
  #else
    Update.end();
  #endif
  otaState = OTA_IDLE;
  expected_chunk_index = 0;
  received_bytes = 0;
  flashStatus(CRGB::Red, 3);
  
  // Send HELLO to restore color state after showing error
  if (HOME_ID != 0) {
    sendHello();
    Serial.println("[OTA] Sent HELLO to restore colors");
  }
}

void handleOtaNotify(HueMixLinkPacket* pkt) {
  if (otaState != OTA_IDLE) {
    Serial.println("[OTA] Busy with another update");
    return;
  }
  
  Serial.println("[OTA] NOTIFY received");
  
  expected_firmware_size = pkt->payload.otaNotify.firmware_size;
  memcpy(expected_sha256, pkt->payload.otaNotify.sha256_hash, 32);
  
  #if defined(ESP32)
    // ESP32: Initialize update partition
    update_partition = esp_ota_get_next_update_partition(NULL);
    if (!update_partition) {
      Serial.println("[OTA] No update partition available");
      abortOta("No partition");
      return;
    }
    
    Serial.printf("[OTA] Starting update: %u bytes\n", expected_firmware_size);
    Serial.printf("[OTA] Target partition: %s at 0x%x\n", update_partition->label, update_partition->address);
    
    esp_err_t err = esp_ota_begin(update_partition, OTA_SIZE_UNKNOWN, &update_handle);
    if (err != ESP_OK) {
      Serial.printf("[OTA] Begin failed: %d\n", err);
      abortOta("Begin failed");
      return;
    }
    
    mbedtls_sha256_init(&sha256_ctx);
    mbedtls_sha256_starts(&sha256_ctx, 0); // 0 = SHA256 (not SHA224)
  #else
    // ESP8266: Initialize Update library
    Serial.printf("[OTA] Starting update: %u bytes\n", expected_firmware_size);
    
    if (!Update.begin(expected_firmware_size)) {
      Serial.printf("[OTA] Begin failed: %s\n", Update.getErrorString().c_str());
      abortOta("Begin failed");
      return;
    }
    
    br_sha256_init(&sha256_ctx);
  #endif
  
  last_ota_activity = millis();
  otaState = OTA_RECEIVING;
  expected_chunk_index = 0;
  received_bytes = 0;
  
  Serial.printf("[OTA] Set last_ota_activity to %lu\n", last_ota_activity);
  
  // Send PKT_OTA_READY immediately
  HueMixLinkPacket ready;
  memset(&ready, 0, sizeof(HueMixLinkPacket));
  ready.type = PKT_OTA_READY;
  WiFi.macAddress(ready.sourceMAC);
  memcpy(ready.targetMAC, pkt->sourceMAC, 6);
  ready.payload.otaReady.firmware_size = expected_firmware_size;
  ready.payload.otaReady.battery_mv = 0; // Not battery powered
  ready.signature = calculateHash(ready.payload.raw, 185, HOME_ID);
  
  // Send to first gateway
  if (gateways.count > 0) {
    #if defined(ESP32)
      esp_now_peer_info_t peerInfo = {};
      memcpy(peerInfo.peer_addr, gateways.macs[0], 6);
      peerInfo.channel = 0;
      peerInfo.encrypt = false;
      if (!esp_now_is_peer_exist(gateways.macs[0])) {
        esp_now_add_peer(&peerInfo);
      }
      esp_now_send(gateways.macs[0], (uint8_t*)&ready, sizeof(ready));
    #else
      if (!esp_now_is_peer_exist(gateways.macs[0])) {
        esp_now_add_peer(gateways.macs[0], WiFi.channel(), ESP_NOW_ROLE_COMBO, NULL, 0);
      }
      esp_now_send(gateways.macs[0], (uint8_t*)&ready, sizeof(ready));
    #endif
    Serial.println("[OTA] Sent READY");
  }
  
  // Start onboard LED blinking to indicate OTA in progress
  startLedBreathing();
}

void handleOtaChunk(HueMixLinkPacket* pkt) {
  if (otaState != OTA_RECEIVING) {
    return;
  }
  
  last_ota_activity = millis();
  
  uint16_t chunk_idx = pkt->payload.otaChunk.chunk_index;
  uint8_t data_len = pkt->payload.otaChunk.data_len;
  
  // Check chunk order: accept current or future chunks, ignore duplicates
  if (chunk_idx < expected_chunk_index) {
    // This is a duplicate chunk we already received - ignore it silently
    Serial.printf("[OTA] Ignoring duplicate chunk %d (already at %d)\n", chunk_idx, expected_chunk_index);
    return;
  }
  
  if (chunk_idx != expected_chunk_index) {
    Serial.printf("[OTA] Ignoring out-of-order chunk %d (expecting %d)\n", chunk_idx, expected_chunk_index);
    return;
  }
  
  #if defined(ESP32)
    // ESP32: Write to partition
    esp_err_t err = esp_ota_write(update_handle, pkt->payload.otaChunk.data, data_len);
    if (err != ESP_OK) {
      Serial.printf("[OTA] Write failed at chunk %d: %d\n", chunk_idx, err);
      abortOta("Write failed");
      return;
    }
    mbedtls_sha256_update(&sha256_ctx, pkt->payload.otaChunk.data, data_len);
  #else
    // ESP8266: Write via Update library
    size_t written = Update.write(pkt->payload.otaChunk.data, data_len);
    if (written != data_len) {
      Serial.printf("[OTA] Write failed at chunk %d: wrote %d of %d\n", chunk_idx, written, data_len);
      abortOta("Write failed");
      return;
    }
    br_sha256_update(&sha256_ctx, pkt->payload.otaChunk.data, data_len);
  #endif
  
  received_bytes += data_len;
  expected_chunk_index++;
  
  if (chunk_idx % 50 == 0) {
    Serial.printf("[OTA] Progress: %u / %u bytes (%.1f%%)\n", 
      received_bytes, expected_firmware_size, 
      (received_bytes * 100.0) / expected_firmware_size);
  }
}

void sendOtaChunkAck(uint16_t last_chunk_index) {
  HueMixLinkPacket ack;
  memset(&ack, 0, sizeof(HueMixLinkPacket));
  ack.type = PKT_OTA_CHUNK_ACK;
  WiFi.macAddress(ack.sourceMAC);
  memset(ack.targetMAC, 0, 6); // Server doesn't need target MAC
  ack.msgID = 0;
  
  ack.payload.otaChunkAck.last_chunk_index = last_chunk_index;
  ack.signature = calculateHash(ack.payload.raw, 185, HOME_ID);
  
  // Send to first gateway
  if (gateways.count > 0) {
    #if defined(ESP32)
      esp_now_peer_info_t peerInfo = {};
      memcpy(peerInfo.peer_addr, gateways.macs[0], 6);
      peerInfo.channel = 0;
      peerInfo.encrypt = false;
      if (!esp_now_is_peer_exist(gateways.macs[0])) {
        esp_now_add_peer(&peerInfo);
      }
      esp_now_send(gateways.macs[0], (uint8_t*)&ack, sizeof(ack));
    #else
      if (!esp_now_is_peer_exist(gateways.macs[0])) {
        esp_now_add_peer(gateways.macs[0], WiFi.channel(), ESP_NOW_ROLE_COMBO, NULL, 0);
      }
      esp_now_send(gateways.macs[0], (uint8_t*)&ack, sizeof(ack));
    #endif
    Serial.printf("[OTA] Sent checkpoint ACK: last_chunk=%d\n", last_chunk_index);
  }
}

void handleOtaCheckpointReq(HueMixLinkPacket* pkt) {
  if (otaState != OTA_RECEIVING) {
    return;
  }
  
  // Respond with last successfully received chunk (expected_chunk_index - 1)
  uint16_t last_chunk = (expected_chunk_index > 0) ? (expected_chunk_index - 1) : 0;
  sendOtaChunkAck(last_chunk);
}

void handleOtaComplete(HueMixLinkPacket* pkt) {
  if (otaState != OTA_RECEIVING) {
    return;
  }
  
  Serial.println("[OTA] COMPLETE received, validating...");
  otaState = OTA_VALIDATING;
  
  // Finalize SHA256
  uint8_t calculated_sha256[32];
  #if defined(ESP32)
    mbedtls_sha256_finish(&sha256_ctx, calculated_sha256);
    mbedtls_sha256_free(&sha256_ctx);
  #else
    br_sha256_out(&sha256_ctx, calculated_sha256);
  #endif
  
  // Compare SHA256
  if (memcmp(calculated_sha256, expected_sha256, 32) != 0) {
    Serial.println("[OTA] SHA256 MISMATCH!");
    Serial.print("[OTA] Expected: ");
    for(int i=0; i<32; i++) Serial.printf("%02X", expected_sha256[i]);
    Serial.println();
    Serial.print("[OTA] Calculated: ");
    for(int i=0; i<32; i++) Serial.printf("%02X", calculated_sha256[i]);
    Serial.println();
    abortOta("SHA256 mismatch");
    return;
  }
  
  Serial.println("[OTA] SHA256 verified!");
  
  #if defined(ESP32)
    // ESP32: Finalize OTA
    esp_err_t err = esp_ota_end(update_handle);
    if (err != ESP_OK) {
      Serial.printf("[OTA] End failed: %d\n", err);
      abortOta("End failed");
      return;
    }
    update_handle = 0;
    
    // Set boot partition
    err = esp_ota_set_boot_partition(update_partition);
    if (err != ESP_OK) {
      Serial.printf("[OTA] Set boot partition failed: %d\n", err);
      abortOta("Set boot failed");
      return;
    }
  #else
    // ESP8266: Finalize Update
    if (!Update.end(true)) {
      Serial.printf("[OTA] End failed: %s\n", Update.getErrorString().c_str());
      abortOta("End failed");
      return;
    }
  #endif
  
  // Send final checkpoint ACK
  if (expected_chunk_index > 0) {
    sendOtaChunkAck(expected_chunk_index - 1);
  }
  
  Serial.println("[OTA] UPDATE SUCCESSFUL! Rebooting in 2 seconds...");
  otaState = OTA_COMPLETE;
  
  stopLedBreathing();
  
  // Flash onboard LED to indicate success (avoid FastLED)
  for (int i = 0; i < 10; i++) {
    digitalWrite(ONBOARD_LED, HIGH);
    delay(100);
    digitalWrite(ONBOARD_LED, LOW);
    delay(100);
  }

  ESP.restart();
}

void handleOtaAbort(HueMixLinkPacket* pkt) {
  Serial.println("[OTA] ABORT received from server");
  abortOta("Server abort");
}
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
void loop() {
  // Apply LED breathing update (interrupt-safe for ESP8266)
  applyBreathingLed();
  
  // --- PROCESS QUEUED PACKETS (ESP8266 interrupt-safe) ---
  #ifdef ESP8266
  while (packetQueueTail != packetQueueHead) {
    if (packetQueue[packetQueueTail].valid) {
      processReceivedPacket(&packetQueue[packetQueueTail].packet, packetQueue[packetQueueTail].mac);
      packetQueue[packetQueueTail].valid = false;
    }
    packetQueueTail = (packetQueueTail + 1) % PACKET_QUEUE_SIZE;
  }
  #endif
  
  // --- OTA TIMEOUT CHECK ---
  if (otaState == OTA_RECEIVING && millis() - last_ota_activity > 30000) {
    Serial.printf("[OTA] Timeout check: millis=%lu, last_ota_activity=%lu, diff=%lu\n", millis(), last_ota_activity, millis() - last_ota_activity);
    Serial.println("[OTA] Timeout - no activity for 30s");
    abortOta("Timeout");
  }

  // --- FACTORY RESET LOGIC ---
  if (digitalRead(PIN_RESET) == LOW) {
    unsigned long holdStart = millis();
    
    // Show visual warning (Red)
    FastLED.setBrightness(100);
    fillSolid(CRGB::Red);
    FastLED.show();
    
    while (digitalRead(PIN_RESET) == LOW) {
      if (millis() - holdStart > 5000) {
        Serial.println("FACTORY RESET!");
        flashStatus(CRGB::Red, 5);
        
        // Selective reset: only clear pairing data
        prefs.remove("hid");   // Clear HOME_ID
        prefs.remove("gw");    // Clear gateways
        // Keep: "leds" (configurable LED count)
        Serial.println("[RESET] Cleared pairing data, LED count preserved");
        
        ESP.restart();
      }
      delay(10);
    }
    
    Serial.println("Reset Aborted. Requesting State...");
    fillSolid(CRGB::Black);
    FastLED.show();
    #ifdef HAS_WARMWHITE_PWM
      setWhitePWM(0);
    #endif
    sendHello();
  }

  // --- UNPAIRED BEHAVIOR ---
  if (!isPaired) {
    if (millis() - lastPairRequest > 5000) {
      sendHello();
      lastPairRequest = millis();
    }
  }
  
  #if defined(ESP8266)
    yield();
  #endif
}

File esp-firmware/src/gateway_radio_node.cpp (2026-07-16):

/* 
  HUEMIXLINK V3 - GATEWAY RADIO FIRMWARE
  Supports: ESP32
*/

#include "HueMixLink.h"
#include <Preferences.h>
#include <nvs_flash.h>
#include "soc/soc.h"
#include "soc/rtc_cntl_reg.h"
#include <esp_mac.h>
#include <esp_now.h>
#include <WiFi.h>
#include <Ticker.h>
#include <esp_ota_ops.h>
#include <esp_partition.h>
#include "mbedtls/sha256.h"

#ifndef IS_SERIAL_GATEWAY
  #define IS_SERIAL_GATEWAY 0
#endif

#if IS_SERIAL_GATEWAY
  #include <Wire.h>
  #include <Adafruit_GFX.h>
  #include <Adafruit_SSD1306.h>
#endif

Preferences prefs;
uint32_t HOME_ID = 0; 
bool nightMode = false;
bool netNodeHasWiFi = false;  // Tracks if net node has WiFi connectivity

#define PIN_LED_STATUS 19
#define PIN_RX         16
#define PIN_TX         17

#if IS_SERIAL_GATEWAY
  #define SERIAL_COM Serial
  #define SERIAL_DEBUG Serial2
#else
  #define SERIAL_COM Serial2
  #define SERIAL_DEBUG Serial
#endif

// --- STATUS LED STATE MACHINE ---
enum StatusLEDState { STATUS_LED_IDLE, STATUS_LED_ON, STATUS_LED_BRIEF_OFF };
StatusLEDState statusLEDState = STATUS_LED_IDLE;
unsigned long statusLEDTimer = 0;

// --- DATA LED BREATHING (for OTA) ---
#define DATA_LED_PWM_FREQ 5000
#define DATA_LED_PWM_RESOLUTION 8
Ticker breathingTicker;
int breathingDirection = 1;
int breathingBrightness = 0;

HueMixLinkPacket radioRx;
HueMixLinkPacket radioTx;
Payload_GatewayList activeGateways;

uint8_t lastMsgID = 0;
bool waitingForDelivery = false;
uint8_t lastTargetMAC[6] = {0}; // Store the actual target MAC for delivery reports

volatile bool pktReady = false;
HueMixLinkPacket bufferPkt;

// --- OTA STATE MACHINE ---
enum OtaState { OTA_IDLE, OTA_RECEIVING, OTA_VALIDATING, OTA_COMPLETE };
OtaState otaState = OTA_IDLE;
const esp_partition_t *update_partition = nullptr;
esp_ota_handle_t update_handle = 0;
uint32_t expected_firmware_size = 0;
uint32_t received_bytes = 0;
uint16_t expected_chunk_index = 0;
uint8_t expected_sha256[32];
mbedtls_sha256_context sha256_ctx;
unsigned long last_ota_activity = 0;

// --- STARTUP HANDSHAKE REQUEST TIMEOUT ---
unsigned long startup_time = 0;
bool handshake_request_received = false;
unsigned long last_serial_activity = 0;
#define STARTUP_HANDSHAKE_TIMEOUT 3000  // 3 seconds
#define SERIAL_IDLE_THRESHOLD 50  // Must be idle for 50ms before checking for handshake request

#if IS_SERIAL_GATEWAY
  #define OLED_WIDTH 128
  #define OLED_HEIGHT 64
  #define OLED_I2C_ADDR 0x3C
  #define OLED_RESET -1
  #define OLED_PIN_SDA 21
  #define OLED_PIN_SCL 22

  Adafruit_SSD1306 oled(OLED_WIDTH, OLED_HEIGHT, &Wire, OLED_RESET);

  struct DashboardStats {
    char cpu[8];
    char ram[8];
    char ip[24];
    char uptime[16];
    char temp[8];
    bool valid;
    unsigned long lastUpdateMs;
  };

  DashboardStats dashboardStats = {{0}, {0}, {0}, {0}, {0}, false, 0};
  char dashboardLineBuffer[96] = {0};
  uint8_t dashboardLineIndex = 0;
  bool dashboardDisplayReady = false;
  unsigned long lastDashboardRender = 0;
  unsigned long dashboardActivityFlashUntilMs = 0;
  bool dashboardScreenOn = true;
  #define DASHBOARD_STALE_RESET_MS 10000
  #define DASHBOARD_ACTIVITY_FLASH_MS 350
#endif

// --- RADIO SERIAL PARSER ---
enum SerialState { S_IDLE, S_READING, S_FOOTER };
SerialState rxState = S_IDLE;
uint16_t rxIndex = 0;
uint8_t rxRawBuffer[sizeof(HueMixLinkPacket)];

static bool shouldAckInboundPacket(uint8_t packetType) {
  return packetType == PKT_BTN_EVENT ||
         packetType == PKT_MOTION_EVENT ||
         packetType == PKT_DOOR_EVENT ||
         (packetType >= PLUGIN_EVENT_PACKET_MIN && packetType <= PLUGIN_EVENT_PACKET_MAX);
}

// --- OTA BUFFERING CONFIG ---
#define OTA_BUFFER_MAX_CHUNKS 15
#define CHUNK_PAYLOAD_SIZE 185
#define OTA_ACCUMULATOR_SIZE (CHUNK_PAYLOAD_SIZE * OTA_BUFFER_MAX_CHUNKS)
uint8_t otaAccumulator[OTA_ACCUMULATOR_SIZE];
uint16_t otaAccumulatorIndex = 0;

#if IS_SERIAL_GATEWAY
void drawCenteredText(const char* text, int y, uint8_t textSize = 1) {
  int16_t x1, y1;
  uint16_t w, h;
  oled.setTextSize(textSize);
  oled.getTextBounds(text, 0, y, &x1, &y1, &w, &h);
  int x = (OLED_WIDTH - (int)w) / 2;
  if (x < 0) x = 0;
  oled.setCursor(x, y);
  oled.print(text);
}

void drawWifiIcon(int x, int y) {
  // First signal arc (outer, largest)
  oled.drawPixel(x+0, y+3, SSD1306_WHITE);
  oled.drawPixel(x+1, y+2, SSD1306_WHITE);
  oled.drawPixel(x+2, y+1, SSD1306_WHITE);
  oled.drawFastHLine(x+3, y, 8, SSD1306_WHITE);
  oled.drawPixel(x+11, y+1, SSD1306_WHITE);
  oled.drawPixel(x+12, y+2, SSD1306_WHITE);
  oled.drawPixel(x+13, y+3, SSD1306_WHITE);

  // Second signal arc (middle)
  oled.drawPixel(x+2, y+5, SSD1306_WHITE);
  oled.drawPixel(x+3, y+4, SSD1306_WHITE);
  oled.drawFastHLine(x+4, y+3, 6, SSD1306_WHITE);
  oled.drawPixel(x+10, y+4, SSD1306_WHITE);
  oled.drawPixel(x+11, y+5, SSD1306_WHITE);

  // Third signal arc (inner, smallest)
  oled.drawPixel(x+4, y+7, SSD1306_WHITE);
  oled.drawPixel(x+5, y+6, SSD1306_WHITE);
  oled.drawFastHLine(x+6, y+6, 2, SSD1306_WHITE);
  oled.drawPixel(x+8, y+6, SSD1306_WHITE);
  oled.drawPixel(x+9, y+7, SSD1306_WHITE);

  // WiFi dot (square)
  oled.drawPixel(x+6, y+9, SSD1306_WHITE);
  oled.drawPixel(x+7, y+9, SSD1306_WHITE);
  oled.drawPixel(x+6, y+10, SSD1306_WHITE);
  oled.drawPixel(x+7, y+10, SSD1306_WHITE);
}

void drawActivityIndicator() {
  if (millis() < dashboardActivityFlashUntilMs) {
    oled.fillCircle(OLED_WIDTH - 5, OLED_HEIGHT - 5, 2, SSD1306_WHITE);
  }
}

void renderInitializingScreen() {
  oled.clearDisplay();
  oled.setTextColor(SSD1306_WHITE);
  oled.setTextSize(1);

  drawCenteredText("HueMix-Link", 19, 1);

  int16_t x1, y1;
  uint16_t wBase, hBase, wFull, hFull;
  oled.getTextBounds("Initializing", 0, 0, &x1, &y1, &wBase, &hBase);
  oled.getTextBounds("Initializing...", 0, 0, &x1, &y1, &wFull, &hFull);

  int startX = (OLED_WIDTH - (int)wFull) / 2;
  if (startX < 0) startX = 0;

  oled.setCursor(startX, 36);
  oled.print("Initializing");

  uint8_t dots = (millis() / 300) % 4;
  const char* dotsText = "";
  if (dots == 1) dotsText = ".";
  else if (dots == 2) dotsText = "..";
  else if (dots == 3) dotsText = "...";

  oled.setCursor(startX + (int)wBase, 36);
  oled.print(dotsText);

  drawActivityIndicator();

  oled.display();
}

void drawCpuIcon(int x, int y) {
  oled.drawRect(x + 2, y + 2, 12, 12, SSD1306_WHITE);
  for (int i = 0; i < 4; i++) {
    oled.drawFastVLine(x + 4 + i * 2, y, 2, SSD1306_WHITE);
    oled.drawFastVLine(x + 4 + i * 2, y + 14, 2, SSD1306_WHITE);
    oled.drawFastHLine(x, y + 4 + i * 2, 2, SSD1306_WHITE);
    oled.drawFastHLine(x + 14, y + 4 + i * 2, 2, SSD1306_WHITE);
  }
  oled.drawRect(x + 6, y + 6, 4, 4, SSD1306_WHITE);
}

void drawRamIcon(int x, int y) {
  oled.drawRect(x + 1, y + 3, 14, 10, SSD1306_WHITE);
  oled.drawFastHLine(x + 2, y + 6, 12, SSD1306_WHITE);
  oled.drawFastHLine(x + 2, y + 9, 12, SSD1306_WHITE);
  for (int i = 0; i < 4; i++) {
    oled.drawPixel(x + 3 + i * 3, y + 2, SSD1306_WHITE);
    oled.drawPixel(x + 3 + i * 3, y + 13, SSD1306_WHITE);
  }
}
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

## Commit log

2025-12-07 Add .gitignore and update platformio.ini; refactor button handling in gateway_net_node and normal_button
2025-12-27 Fix backup reload, add notifiers, and file not existing management
    [network_server.py]
2025-12-28 Change led type
2025-12-28 Refactor LED control logic to use LED_ACTIVE_HIGH for consistency
2025-12-29 Add clear LED schedule functionality with confirmation modal
2025-12-29 Activate scene when setting up button
2025-12-29 Remove configured scene from button when original scene is deleted. And handle delete/add SSE events for lights, scenes, and rooms
2025-12-29 Fix: Replace print with logger
2025-12-29 Change devices ids to uuid4
2025-12-30 Remove print
2025-12-30 Fix issue with not configured buttons
2025-12-30 Flash button when pressed on settings page
2026-01-13 Add device type definitions and update packet payloads for gateway, light, and button. Fix button not activating with short presses
    [gateway_net_node.cpp, lightstrip.cpp, normal_button.cpp]
2026-01-13 feat: Add remote control support and configuration
    - Updated DeviceManager to handle remote devices with new device_type parameter.
    - Enhanced NetworkServer to process HELLO packets from remote controls and manage pairing.
    - Implemented PacketDecoder changes to recognize remote devices and their actions.
    - Modified PairingManager to include remote devices in allowed types.
    - Added API endpoints for configuring remote controls with per-button actions and room mappings.
    - Created a new modal in the frontend for remote configuration, allowing users to set actions and scenes for each button.
    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
2026-01-13 Implementation of battery status
2026-01-13 Add remote to pairing devices
2026-01-13 Fix direction toggle on remote
    [automation_engine.py]
2026-01-15 Fix resistor divider
2026-01-25 OTA update working for all devices
2026-01-26 Change signature protocol to always include full length, fix radio node not updating properly.
    [gateway_net_node.cpp, gateway_radio_node.cpp, lightstrip.cpp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]
2026-01-28 Add scene cycle action for remote buttons and enhance device management UI
2026-01-31 Refactor color conversion methods and enhance network server reliability with socket checks
2026-02-01 Bump version to 3.8.1; update DOUBLE_TAP_WINDOW to 1000ms in button firmware and improve remote button event handling
2026-02-13 Hardware Design
    [1571627-1.step, 2171750001.step, AO3400A.step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]
2026-02-16 Motion sensor initial commit
2026-02-17 Ignore KiCad backup/local files in Hardware-designs
    [1571627-1.step, 2171750001.step, AO3400A.step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]
2026-02-18 Add pcb images, step file, and pdf schematic for all hardware designs.
    [Gateway_v1.1.kicad_pcb, Gateway_v1.1.kicad_sch, Gateway_v1.1.step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]
2026-02-18 Add production output for remote.
    [bom.csv, designators.csv, esp_now_button_3.1-Panel.kicad_pcb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]
2026-02-18 Revert "Update color functions and add new lightstrip model"
    This reverts commit 1c41b5c88474862ff84bd28d54ce498e215f0f58.
    [automation_engine.py]
2026-02-20 add motion sensor hardware
    [APHBM2012ETSGTC.stp, IRA-S410ST01.step, Lightstrip_m5_v1.kicad_sch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]
2026-02-21 Add serial labels on pcb
    [Lightstrip_m5_v1.kicad_pcb, bom.csv, positions.csv]
2026-02-22 feat: Configurable 1-4 button remotes with triple-tap configuration
    Add flexible button count (1-4) for ESP32 remotes configured via
    triple-tap reset + held button combinations. Includes hardware pattern
    validation, dynamic wakeup masks, custom UI naming (Circle/Center/Square),
    context-aware defaults, and immediate auto-registration support.
    Remotes can now operate as 1, 2, 3, or 4-button devices with proper
    firmware/UI adaptation. Backward compatible with existing remotes.
    [automation_engine.py, device_manager.py, gateway_net_node.cpp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]
2026-02-23 Add Ota Support for motion sensors and add cooldown command.
2026-02-24 Bump motion sensor version
2026-02-24 Revert "Revert "Update color functions and add new lightstrip model""
    This reverts commit 3ccff76ec2a8d7b2dcd7205871dbaeb94320e082.
    [automation_engine.py]
2026-02-24 Refactor lightstrip configurations and update OTA management for improved device handling
2026-02-24 Improve gateway led status,
2026-02-24 Fix button building script name
2026-02-24 Fix motion sensor ota failure init
    [motion_sensor.cpp]
2026-02-24 Finish ota updates for motion sensor.
2026-02-24 Lower PWM frequency to stabilize signal
    [lightstrip.cpp]
2026-03-01 correction voltage regulator
    [Lightstrip_m5_v1.kicad_pcb, Motion_Sensor_v1.1.kicad_pcb, Motion_Sensor_v1.1.kicad_sch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]
2026-03-10 Add motion sensor endpoints on pairing page.
2026-03-12 Magnetic Sensor
    [APHBM2012ETSGTC.stp, BH123A.step, Base Motion Sensor.stl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]
2026-03-16 Bug fixes remote and motion sensor
    [motion_sensor.cpp, remote_button.cpp]
2026-03-18 Use last seen gateway instead of first gateway for remotes and buttons.
2026-03-18 Fix ota chunks to also use best gateway for remotes and buttons
    [network_server.py]
2026-03-18 Update motion sensor reset button to work more efficiently.
2026-03-28 Start esp firmware for door sensor
2026-03-29 Finish implementation for door sensors
    [Base Motion Sensor.stl, Lidl Motion Sensor.stl, Magnetic Sensor.step]
2026-03-29 Fix room state retrieval and enhance SSE handling for room updates
    [automation_engine.py]
2026-03-29 Magnetic sensor update
    [Magnetic Sensor.kicad_pcb, Magnetic Sensor.kicad_sch, Magnetic Sensor.step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]
2026-03-29 Fix door sensor not turning off due to light threshold.
    [automation_engine.py]
2026-03-29 Add door closing timer
2026-04-02 update readme with new devices
2026-04-02 Make sensor after time second based
2026-04-03 Minor KiCad files update for all devices
    [Gateway_v1.1.kicad_pcb, Gateway_v1.1.kicad_sch, Lightstrip_m5_v1.kicad_pcb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]
2026-04-03 Add 3D Models
    [Axle 1_2 buttons.stl, Axle 1_3 buttons.stl, Axle 2_2 buttons.stl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]
2026-04-03 Disable unused 3d models
    [Motion_Sensor_v1.1.kicad_pcb, Normal_Button_v3.kicad_pcb]
2026-04-04 Make dimming lights motion sensor depend on overall time.
2026-04-04 Lightstrip version 2
    [AO3400A.step, Lightstrip.kicad_pcb, Lightstrip.kicad_sch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]
2026-04-05 Fix motion sensors canceling due to SSE delays.
    [automation_engine.py]
2026-04-26 Fix magnetic sensor pcb
    [Magnetic Sensor.kicad_pcb, Magnetic Sensor.kicad_sch, Motion_Sensor_v1.1.kicad_pcb]
2026-06-08 feat: Add plugin management and battery calculation features
    - Introduced a new PluginManager for managing optional plugins, including installation, lifecycle management, and event handling.
    - Added PluginInstallService to handle plugin installation sessions and progress tracking.
    - Implemented battery percentage calculation logic in a new battery.py service, supporting different battery types.
    - Enhanced OTA management by adding preferred gateway MAC address in OTASession.
    - Updated pairing.html to include an option for "Plugin Devices Only" in the device selection dropdown.
    - Created a new battery service to provide shared battery helpers across device views and services.
2026-07-16 Fix brightness analysis logging to handle None values gracefully
    [automation_engine.py]
2026-08-11 update August 2026
    [Magnetic Sensor.kicad_pcb]
2026-08-13 Fix motion sensor config validation for cooldown and time slots
2026-08-13 Revamp mesh page with topology map, battery states and skeletons
2026-08-27 Add 'All Off' remote action and fix remote scene re-ordering
    - New REMOTE_ACTION_ALL_OFF action type turns off all rooms on click
    - Hide room/scene selection when All Off is selected
    - Fix renderRemoteSelectedScenes using undefined 'rooms' variable (should be 'groups')
    - Fix same bug in findSceneById
    - Bump version to 3.16.0
    [automation_engine.py]
2026-08-29 Fix motion sensor time slots config not saving correctly
    Motion sensor config was importing _normalize_time_slots from
    door_sensors, which validates door sensor fields (open_action,
    close_action, close_delay_seconds) and strips out motion sensor
    fields (motion_action, scene_id, after_action, after_scene_id,
    after_duration_seconds). This corrupted time slots on every save.
    Added standalone _normalize_motion_time_slots and
    _normalize_light_sensitivity to motion_sensors.py so the two
    blueprints are fully decoupled.
2026-09-23 Update battery percentage calculation to display N/A for devices with pin floating
2026-10-15 Enhance rooms and zones overview with tab switching and improved data rendering
2026-10-23 Magnetic Sensor AAA battery version added
